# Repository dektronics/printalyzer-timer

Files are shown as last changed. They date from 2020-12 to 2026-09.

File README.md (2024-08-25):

# Printalyzer

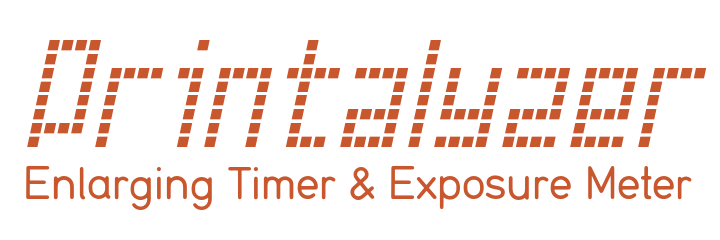
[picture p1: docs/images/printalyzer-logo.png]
Printalyzer Logo


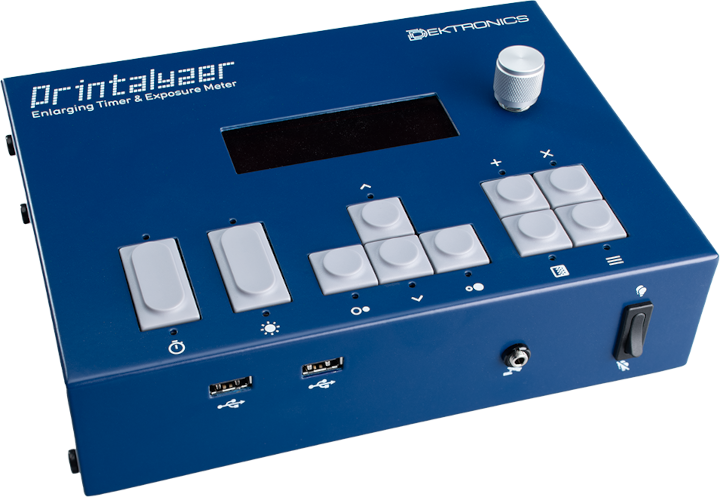
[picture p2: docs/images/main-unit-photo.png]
Main Unit Rendering


## Introduction

The Printalyzer is an F-Stop enlarging timer and print exposure meter.

A good overview of the project can be found in these blog posts:
* [Introducing the Printalyzer!](https://hecgeek.blogspot.com/2020/11/introducing-printalyzer.html)
* [Printalyzer Project Update](https://hecgeek.blogspot.com/2020/12/printalyzer-project-update.html)

Videos demonstrating the project are here:
* [Introducing the Printalyzer](https://youtu.be/2FPqqqVILP8)

The eventual goal of this project is to be available as a complete product available here:
* [Printalyzer Enlarging Timer](https://www.dektronics.com/printalyzer-enlarging-timer)

Note: This project is currently a work-in-progress, so expect the hardware and software to be continuously evolving.  The last functional version of this repository, using the revision A prototype hardware, was
'main-board-rev-a-186-g9bce418'.

## Project Layout

### Hardware
The "hardware" directory contains [KiCad](https://www.kicad.org/) projects
with the complete circuit schematics, bill-of-materials, and
PCB layouts.

* Main Board (main-board)
  * The main circuit board which contains all of the top panel controls and front panel ports
  * Runs off a +12V DC input, and contains regulators for all other voltage rails

* Power Board (power-board)
  * The AC power input board, which is the only part of the system that should ever touch mains AC power
  * Runs off power from an IEC320 C14 inlet, and provides output power to drive two IEC320 C13 outlets
  * Outputs the +12V DC power supply to run the rest of the system
  * Contains any connectors that need to be on the rear panel, isolating them if they do not involve mains AC power

* Printalyzer Meter Probe (meter-probe)
  * The circuit board contained within the external light meter probe peripheral
  * Connected to the main board and powered via a captive USB cable

* Printalyzer DensiStick (densistick)
  * The circuit board contained within the external reflection densitometer peripheral
  * Connected to the main board and powered via a captive USB cable

### Software
The "software" directory contains all the source code for the firmware
that runs on the hardware.

### Enclosure
The "enclosure" directory contains any CAD models and related resources
necessary to physically assemble the project.

## License
Individual directories will contain LICENSE files as needed, with relevant
details. Generally, the hardware will be CC BY-SA and the software will be
BSD 3-Clause. However, external resources may have their own individual license terms.

## Credits

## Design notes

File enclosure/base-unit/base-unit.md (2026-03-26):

# Printalyzer Enclosure Base Unit

## Introduction

This directory contains all the assets necessary to produce the physical
base unit enclosure for the Printalyzer. This document explains how to use
those assets, and ultimately how to assemble the enclosure.

## Electronics

### Main Board

The assets for the main circuit board are contained within the "main-board"
project under the top-level "hardware" directory. This board is installed
into the "cover" part of the main enclosure.

### Power Board

The assets for the main circuit board are contained within the "power-board"
project under the top-level "hardware" directory. This board is installed
into the "base" part of the main enclosure.

## Enclosures

### Main Enclosure

#### Enclosure components

The main enclosure is designed for sheet metal fabrication as two components.
The "base" is the bottom half where the power board is installed, and the
"cover" is the top half where the main board is installed.
Basic mechanical design files are provided, but the artwork is not published.

The provided files are as follows:
* `enclosure-full.step` - Complete enclosure model
* `enclosure-base-flat.dxf` - Flat pattern for the "base"
* `enclosure-cover-flat.dxf` - Flat pattern for the "cover"
* `design-drawings.pdf` - Basic design drawings

Base fabrication notes:
* Material: Galvanized sheet SGCC, 1.2mm thickness
* Contains 2 blind threaded standoffs, M3x0.5, 8mm length (PEM BSO-M3-8ZI)
* Contains 1 self-clinching threaded stud, M3x12mm (PEM FH-M3-12ZI)
* Contains 6 self-clinching nuts, M4x0.7 (PEM S-M4-1ZI)
* All blind standoffs must be inserted before powder coating, so that they are difficult to see from the outside of the finished product.
* Powder coat exterior surfaces only. Do not powder coat interior surfaces or the fold-up tabs with the self-clinching nuts.

Cover fabrication notes:
* Material: Galvanized sheet SGCC, 1.2mm thickness
* Contains 4 blind threaded standoffs, M3x0.5, 10mm length (PEM BSO-M3-10ZI)
* All blind standoffs must be inserted before powder coating, so they are
  difficult to see on the finished product.
* Inside of front edges, where the folds meet, need to be tack welded.
* Powder coat exterior surfaces only.  Do not powder coat interior surfaces.

#### Mounting hardware

Mounting hardware for the main enclosure consists of the following
components from [McMaster-Carr](https://www.mcmaster.com/), unless otherwise
specified. It should be possible to substitute hardware from other vendors as
long as it has the same specifications.

* Mounting "main-board" PCB to enclosure cover
  * **92005A118 (Qty. 4)** - Zinc-Plated Steel Pan Head Screw,
    M3 x 0.5mm Thread, 8mm Long
  * **98688A112 (Qty. 4)** - General Purpose Zinc-Plated Steel Washer for M3 Screw
  * **93925A417 (Qty. 4)** - Zinc-Plated Internal-Tooth Washer for M3 Screw
  * **90768A107 (Qty. 1)** - Side-Mount External Retaining Ring for 7mm ID
  * **97985A113 (Qty. 1)** - Zinc-Plated Steel External-Tooth Lock Washer for M7 Screw

* Mounting OLED display module to "main-board" PCB
  * **90657A106 (Qty. 4)** - Zinc-Plated Steel Narrow Cheese Head Slotted Screw,
    M3 x 0.5 mm Thread, 10 mm Long, 4 mm Head Diameter
  * **93657A203 (Qty. 4)** - Nylon Unthreaded Spacer,
    3 mm Long, for M3 Screw Size
  * **95225A315 (Qty. 4)** - Electrical-Insulating Hard Fiber Washer,
    for M3 Screw Size, 3.2 mm ID, 7 mm OD
  * **90576A102 (Qty. 4)** - Medium-Strength Steel Nylon-Insert Locknut,
    M3 x 0.5 mm Thread, 4 mm High

* Mounting "power-board" PCB to enclosure base
  * **92005A118 (Qty. 2)** - Zinc-Plated Steel Pan Head Screw,
    M3 x 0.5mm Thread, 8mm Long
  * **98688A112 (Qty. 2)** - General Purpose Zinc-Plated Steel Washer for M3 Screw
  * **93925A417 (Qty. 2)** - Zinc-Plated Internal-Tooth Washer for M3 Screw

* Mounting rear panel power connectors to "power board" PCB
  * **92005A120 (Qty. 6)** - Zinc-Plated Steel Pan Head Screw,
    M3 x 0.5mm Thread, 10mm Long
  * **95225A315 (Qty. 6)** - Electrical-Insulating Hard Fiber Washer,
    for M3 Screw Size, 3.2 mm ID, 7 mm OD
  * **90576A102 (Qty. 6)** - Medium-Strength Steel Nylon-Insert Locknut,
    M3 x 0.5 mm Thread, 4 mm High

* Mounting rear panel power and XLR connectors to enclosure base
  * **95836A209 (Qty. 6)** - Black-Oxide 18-8 Stainless Steel Pan Head Phillips Screw,
    M3 x 0.50 mm Thread, 10mm Long
  * **90576A102 (Qty. 6)** - Medium-Strength Steel Nylon-Insert Locknut,
    M3 x 0.5 mm Thread, 4 mm High
  * **A-SCREW-1-8 (Qty. 2)** - Black self-tapping Plastite screw
    (sold by Neutrik via electronics distributors)

#### Non-PCB Electronic Components
These electronic components are not included in the PCB's bill-of-materials,
but are ordered from the same kinds of vendors and are necessary to assemble
a complete device.

* Blackout switch
  * **Marquardt 1911.1102**
  * Rocker Switches ROCKER ON/OFF SWITCH SPST
* Power switch
  * **Marquardt 1801.1148**
  * Rocker Switches ROCKER ON/OFF SWITCH SPST
* Footswitch jack
  * **CUI MJ-3502**
  * Phono Connector 3.5mm Mono Jack
* Footswitch jack retaining ring
  * **Befaco Bananuts Black**
* Main fuse
  * **Littelfuse 0217005.MXBP**
  * Cylindrical cartridge fuse, 5x20mm
  * Fast-blow, rated for 5A @ 250V
* Graphic OLED display module
  * **BuyDisplay ER-OLEDM032-1Y**
  * 3.2" diagonal, 256x64 pixels, 4-wire SPI
  * Choose the version without the pin header
* 01x08 pin header, 2.54mm pitch
  * **Omron XG8T-1631**
  * Used to connect between the display module and the main PCB
  * Shorter than a standard pin header
* Key parallel guide
  * **Marquardt 190.059.023 (Qty. 2)**
  * Used as part of mounting the switches that have double-sized key caps

#### Key caps
For the key caps, use the following
[Marquardt](https://www.marquardt-switches.com/) parts:
* **825.000._xxx_ (Qty. 8)** - Square key cap, without LED window, 19mm pitch
* **844.000._xxx_ (Qty. 2)** - Double key cap, without LED window, 19mm pitch

The **_xxx_** portion of the part number can be any of the following:
* **.011** - Anthracite (Black)
* **.021** - Dark grey
* **.031** - Grey

_Note: Darker colors may look better when displaying the device under normal
room lighting, but lighter colors may be easier to see under actual
darkroom conditions._

For the encoder, use a knob designed for a 6mm D shaft. It is also preferable
to use a knob that has no direction marking.
The following choices have been tested so far:
* mxuteuk Black Aluminum Alloy Potentiometer Control Knob\
  Screw Type 17 x 16mm\
  Part # **KNOB-04-BK**
* mxuteuk Silver Aluminum Alloy Potentiometer Control Knob\
  Screw Type 17 x 16mm\
  Part # **KNOB-04-SR**

_For quantity orders, this same knob can be found from other vendors at
a lower price._

#### Internal wiring

* Connecting Blackout switch and Footswitch connector to the "main-board" PCB
  * **JST PHR-2 (Qty. 2)** - JST PH housing receptacle (2-pin)
  * **JSR ASPHSPH24K102 (Qty. 2)** - JST PH 4" jumper wire (cut each in half)
* Connecting "power-board" and "main-board" PCBs for power and relay
  * **JST PHR-4 (Qty. 2)** - JST PH housing receptacle (4-pin)
  * **JST ASPHSPH24K102 (Qty. 4)** - JST PH 4" jumper wire
* Connecting "power-board" and "main-board" PCBs for DMX connector
  * **JST A06SR06SR30K102A (Qty. 1)** - JST SR 4" 6-position reversed jumper wire
* Connecting "power-board" to the power switch
  * **Molex 46992-0210** - Mini-Fit Jr. Receptacle Housing
  * **Molex 215340-1122** - Mini-Fit Jr. Pre-Crimped Lead (cut in half)
  * **TE 3-520125-2 (Qty. 2)** - TE 187 Ultra-Fast Quick Disconnect Receptacle

_If there is not good electrical conductivity between the boards and the enclosure, and between the two halves of the enclosure, then a ground wire with eyelet terminals must be connected between a mounting hole on each board._

#### Other

* Rubylith-type material
  * This is a filter that is installed into the underside of the enclosure top,
    above the display module, to make the output spectrum of the display
    paper-safe.
  * The current preferred material for this purpose is Rosco E-Color #106.
* Thin transparent material to sandwich the rubylith between, for mounting
  and scratch protection.

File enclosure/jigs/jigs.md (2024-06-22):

# Assembly Jigs

## Introduction

This directory contains all the assets necessary to create the various jigs
used to aid in the assembly of the various components of the Printalyzer
Enlarging Timer and its accessories.

## PCB Assembly

These jigs are designed to help hold various components in place for soldering,
fastening, or general bench work. Many of them contain places where metal dowel
pins can be inserted to help hold the boards in correct alignment.

### Main Board

* `jig-main-board-platform-1`
  * Platform to support the main board when it is being worked on. (Orientation 1)
  * Shorter platform that fits the board with the button side facing upwards, or either side if
    the display and encoder are not yet installed.
* `jig-main-board-platform-2`
  * Platform to support the main board when it is being worked on. (Orientation 2)
  * Taller platform that fits the board with the button side facing downwards,
    with extra clearance for both the display and the encoder.
* `jig-main-board-buttons`
  * Jig to hold all of the push buttons in place for soldering.
  * Does not have clearance for the display, encoder, or button caps.
* `jig-main-board-leds`
  * Jig to hold all of the panel LEDs in place for soldering.
  * Does not have clearance for the display, encoder, or button caps.

### Power Board

* `jig-power-board-1`
  * Jig to hold all of the thru-hole components in place for soldering, and to
    make sure all the rear panel connectors are correctly aligned for fastening.
  * This board is designed to have a thin piece of adhesive foam placed onto
    each of the component holding standoffs, to help provide compliant pressure
    and deal with any vertical tolerance issues.
* `jig-power-board-2`
  * Jig to hold the nuts and washers in place on the bottom side of the board.
* `jig-power-board-platform`
  * Platform to support the power board when it is being worked on.

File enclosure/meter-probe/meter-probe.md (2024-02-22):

# Printalyzer Enclosure Meter Probe

## Introduction

This directory contains all the assets necessary to produce the physical
meter probe enclosure for the Printalyzer. This document explains how to use
those assets, and ultimately how to assemble the enclosure.

## Electronics

### Meter Probe

The assets for the meter probe circuit board are contained within the
"meter-probe" project under the top-level "hardware" directory. This board
is installed into the meter probe enclosure.

## Enclosures

### Meter Probe

#### Enclosure components
The meter probe enclosure was created with
[Autodesk Fusion 360](https://www.autodesk.com/products/fusion-360/overview),
and consists of the following components:
* `meter-probe-top.stl` - Top of the meter probe, which contains holes for
  the trigger button and the light sensor.
* `meter-probe-bottom.stl` - Bottom of the meter probe, which contains
  mounting points for the PCB and holes for screws that hold the enclosure
  together.
* `meter-probe-top-front.dxf` - Top front graphic overlay, with a matte clear
  window over the sensor hole.
* `meter-probe-top-rear.dxf` - Top rear graphic overlay, with a cutout over
  the trigger button.

#### Mounting hardware
Mounting hardware for the meter probe enclosure consists of the following
components from [McMaster-Carr](https://www.mcmaster.com/). It should be
possible to substitute hardware from other vendors as long as it has the
same dimensions.

* Mounting "meter-probe" PCB to the enclosure base
  * **90380A337 (Qty. 3)** - Phillips Rounded Head Thread-Forming Screws (M2.5 x 5mm long)
* Assembling the top and bottom of the enclosure
  * **90380A337 (Qty. 2)** - Phillips Rounded Head Thread-Forming Screws (M2.5 x 5mm long)
  * **90380A339 (Qty. 2)** - Phillips Rounded Head Thread-Forming Screws (M2.5 x 8mm long)

#### Key caps
For the cap on top of the trigger button, choose one of the following
[Marquardt](https://www.marquardt-switches.com/) parts:
* **827.100.011** - Anthracite (Black)
* **827.100.021** - Dark grey
* **827.100.031** - Grey

#### Other components
* 8mm diameter light diffuser, cut from LGT125J material with a hole punch
* 10mm diameter (0.5-1.0mm thick) UV-IR cut filter
* Captive USB mouse cable, with a rubber strain relief and a
  JST PH-compatible 5-pin internal connector.

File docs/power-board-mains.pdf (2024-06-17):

# Printalyzer

# Enlarging Timer & Exposure Meter

# Power Board

## Revision E

2024-06-12

## Table of Contents

## Table of Figures

## Circuit Board Design

The board design and layout is broken up into three major sections:
- Mains AC – The portion that handles incoming line voltage, and the primary focus of this document
- Logic DC – The portion that handles the low voltage 12VDC supply for the main board
- DMX – A completely separate low-voltage DC section that is only located on this board for mechanical convenience since it drives a rear panel connector

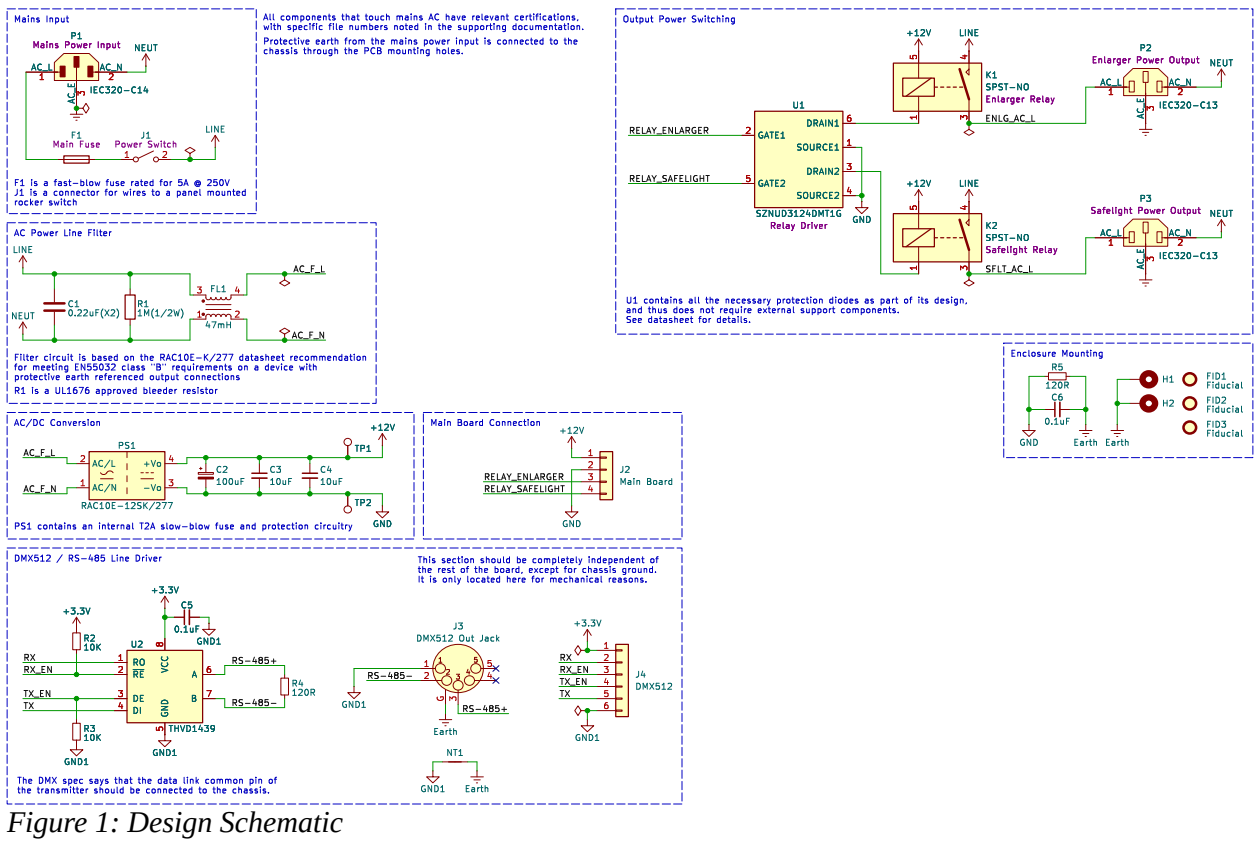
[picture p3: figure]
Figure 1: Design Schematic
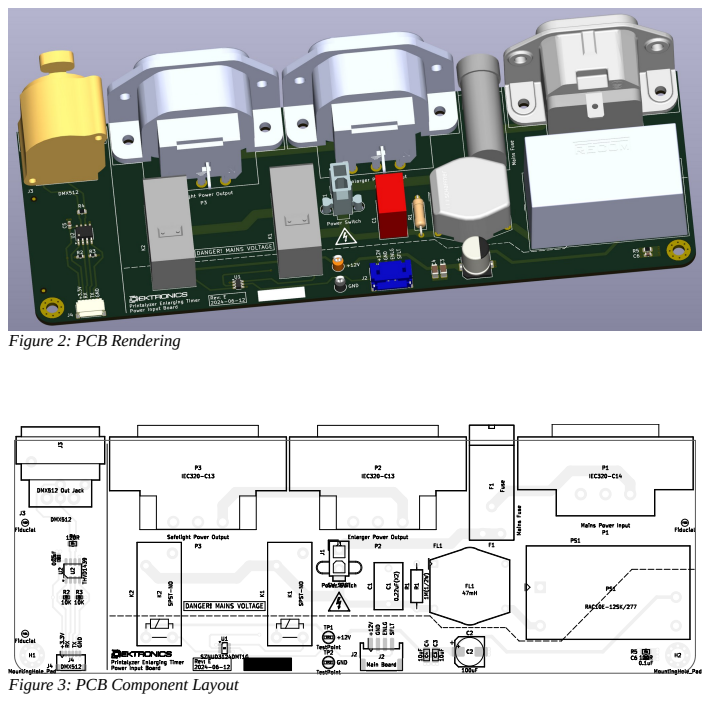
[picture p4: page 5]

Figure 2: PCB Rendering

Figure 3: PCB Component Layout

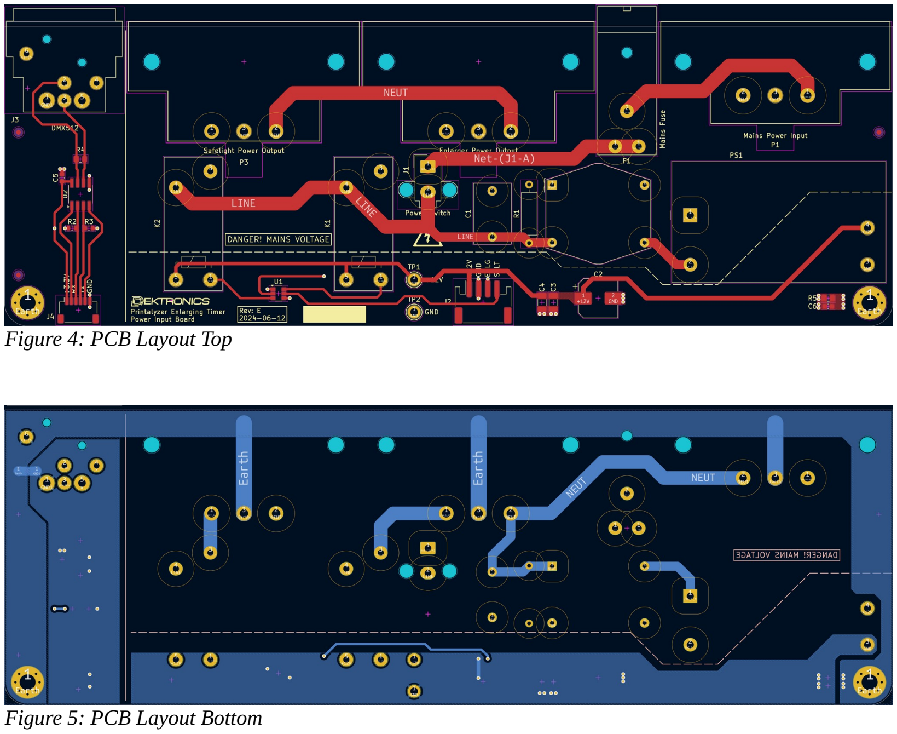
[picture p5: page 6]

Figure 4: PCB Layout Top

Figure 5: PCB Layout Bottom

## Circuit Board Manufacturing

The PCB itself is manufactured by JLCPCB with the following parameters:
- Dimenions: 193 mm x 65 mm
- Thickness: 1.6 mm
- Layers: 2
- Color: Green
- Material type: FR4-Standard TG 135-140
- Outer copper weight: 2 oz
- Surface finish: ENIG

Assembly is conducted in two phases. First, reflow soldering is used to mount the surface mount components. Second, hand soldering is used to mount the thru-hole components. Both are performed using a SAC305 solder alloy.

## Component List

Table 1: PCB Components
Section | Ref | Qty | Manufacturer | Part Number | Description
Mains AC | F1 | 1 | Schurter | 3101.01 | FUSE HLDR CARTRIDGE 400V 16A PCB
Mains AC | J1 | 1 | Molex | 1724470002 | Connector Header Through Hole 2 position
Mains AC | K1,K2 | 2 | Omron | G2RL-1A DC12 | RELAY GEN PURPOSE SPST 12A 12V
Mains AC | P1 | 1 | Schurter | GSP1.9113.1 | PWR ENT RCPT IEC320-C14 PNL SLDR
Mains AC | P2,P3 | 2 | Schurter | 6182 | PWR ENT RCPT IEC320-2-2F PANEL
Mains AC | PS1 | 1 | RECOM Power | RAC10E-12SK/277 | AC/DC CONVERTER 12V 10W
Mains AC | C1 | 1 | Würth Elektronik | 890324023028 | CAP FILM 0.22UF 10% 275VAC (X2)
Mains AC | R1 | 1 | Vishay | VR37000001004JR500 | RES 1M OHM 1/2W 5% MG AXIAL
Mains AC | FL1 | 1 | Schaffner EMC Inc. | RN116-0.5-02-47M | CMC 47MH 500MA 2LN TH
Logic DC | C2 | 1 | Nichicon | UWT1H101MNL1GS | CAP ALUM 100UF 20% 50V SMD
Logic DC | C3,C4 | 2 | Samsung Electro-Mechanics | CL31B106KBHNNNE | CAP CER 10UF 50V X7R 1206
Logic DC | C5,C6 | 2 | Samsung Electro-Mechanics | CL10B104KA8NNNC | CAP CER 0.1UF 25V X7R 0603
Logic DC | J2 | 1 | JST Sales America Inc. | S4B-PH-SM4-TB(LF)(SN) S4B-PH-SM4-TB(LF)(SN)
DMX | J3 | 1 | Neutrik | NC5FBH | XLR Connectors 5C PCB FEMALE RECEPT
DMX | J4 | 1 | JST Sales America Inc. | SM06B-SRSS-TB(LF) (SN) | CONN HEADER SMD R/A 6POS 1MM
Logic DC, DMX | R2,R3 | 2 | Vishay Dale | CRCW060310K0JNEA | RES SMD 10K OHM 5% 1/10W 0603
Logic DC, DMX | R4, R5 | 2 | Vishay Dale | CRCW0805120RFKEA | RES SMD 120 OHM 1% 1/8W 0805
Logic DC | TP1,TP2 | 2 | Keystone Electronics | 5006 | PC TEST POINT COMPACT BLACK
Logic DC | U1 | 1 | ON Semiconductor | SZNUD3124DMT1G | IC PWR DRIVER N-CHANNEL 1:1 SC74
DMX | U2 | 1 | Texas Instruments | THVD1439DR | IC TRANSCEIVER HALF 1/1 8SOIC

Table 2: Non-PCB Components
Section | Qty | Manufacturer | Part Number | Description
Mains AC | 1 | Molex | 46992-0210 | Mini-Fit Jr. Receptacle Housing
Mains AC | 1 | Molex | 215340-1122 | Mini-Fit Jr. Pre-Crimped Lead (cut in half)
Mains AC | 2 | TE Connectivity | 3-520125-2 | TE 187 Ultra-Fast Quick Disconnect Receptacle
Mains AC | 1 | Marquardt Switches | 1801.11 | Rocker On/Off Switch SPST
Mains AC | 1 | Littelfuse | 0217005.MXBP | Cylindrical cartridge fuse, 5x20mm, Fast-blow, rated for 5A @ 250V

## Mains AC Component Details

Manufacturer | Schurter
Part Number | 3101.0050
Description | External Fuse holder, 5 x 20 mm, PCB mounting
Ratings | 250 VAC · 2.5 W / 10 A (VDE) · 500 V · 16 A (UL/CSA)
Approvals | UL | File Number: E39328
| VDE | Certificate Number: 40044101
Manufacturer | Littelfuse
Part Number | 0217005.MXBP
Description | Cylindrical cartridge fuse, 5x20mm, Fast-Blow
Ratings | 5A @ 250V
Approvals | UL | File Number: E10480
| CSA | File Number: 29862
| VDE | Certificate Number: 40016647
Manufacturer | Molex
Part Number | 1724470002
Description | Connector header, through hole, 2 position
Ratings | Voltage: 600V AC (RMS)/DC, Current: 23.5A
Approvals | UL | File Number: (*)
| CSA | File Number: (*)
Manufacturer | Omron
Part Number | G2RL-1A DC12
Description | Electromechanical Relay SPST-NO
Ratings | 12VDC, 12A
Approvals | UL | File Number: E41643
| CSA | File Number: LR31928
| VDE | Certificate Number: 119650

Manufacturer | Schurter
Part Number | GSP1.9113.1
Description | Power Entry Connector Receptacle, Male Blades, IEC 320-C14 Panel Mount, Flange; Through Hole, Right Angle
Ratings | IEC | 10 A / 250 VAC; 50 Hz
| UL/CSA | 15 A / 250 VAC; 60 Hz
Approvals | UL | File Number: E96454
| VDE | Certificate Number: 40012767
| CCC | Certificate Number: 2020180204014251, 2020180204014252
Manufacturer | Schurter
Part Number | 6182.0033
Description | Power Entry Connector Receptacle, Female Sockets IEC 320-2-2/F Panel Mount, Flange; Through Hole, Right Angle
Ratings | IEC | 10 A / 250 VAC; 50 Hz
| UL/CSA | 15 A / 250 VAC; 60 Hz
Approvals | UL | File Number: E103791
| VDE | Certificate Number: 40053329
| CCC | Certificate Number: 2020180204013719 (PC I only)
Manufacturer | RECOM Power
Part Number | RAC10E-12SK/277
Description | Enclosed AC/DC Converter; 10W; 12VDC Output
Ratings | Input: 85-305 VAC 50/60Hz
Output: 12 VDC @ 833 mA
Approvals | E491408-A6019-UL | UL62368-1:2019 3rd Ed CAN/CSA-C22.2 No. 62368-1:2019 3rd Ed.
| 210824013 | IEC62368-1:2018 3rd Ed.
| 210824013 | EN IEC 62368-1:2020 + A11:2020
| 210824014 | IEC62368-1:2014 2nd Ed.
EN62368-1:2014 + A11:2017

Manufacturer | Würth Elektronik
Part Number | 890324023028
Description | CAP FILM 0.22UF 10% 275VAC (X2)
Ratings | 275VAC, Across the mains
Approvals | UL | File Number: E345659
| CQC | File Number: 13001104051
| ENEC10 | File Number: 40038405
Manufacturer | Vishay
Part Number | VR37000001004JR500
Description | RES 1M OHM 1/2W 5% MG AXIAL
Ratings | UL1676
Approvals | UL | File Number: E171160
Manufacturer | Schaffner EMC Inc.
Part Number | RN116-0.5-02-47M
Description | CMC 47MH 500MA 2LN TH
Ratings | 300 VAC, Design corresponding to UL 1283, IEC/EN 60938-1
Approvals | UL | File Number: E64388
| VDE | Certificate Number: 114916
Manufacturer | Molex
Part Number | 46992-0210
Description | Mini-Fit Jr. Receptacle Housing
Ratings | UL 94V-2, Glow-Wire Capable
Approvals | UL | File Number: E29179
| CSA | File Number: LR19980
Manufacturer | Molex
Part Number | 215340-1122
Description | Mini-Fit Jr. Pre-Crimped Lead (cut in half), UL 1015, 16 AWG
Ratings | 600V, 9A

Manufacturer | TE Connectivity
Part Number | 3-520125-2
Description | Ultra-Fast 187 Quick Disconnect Female 14-16 AWG Crimp Connector Fully Insulated
Ratings | 600V
Approvals | UL | File Number: E66717
Manufacturer | Marquardt Switches
Part Number | 1801.1148
Description | Rocker On/Off Switch SPST
Ratings | IEC | 8 (8) A 250 V AC 5E4 12 (4) A 250 V AC 1E4
| North America | 15A 250 V AC 1 1/2 HP 15A 125 V AC 3/4 HP
Approvals | UL | File Number: E41791

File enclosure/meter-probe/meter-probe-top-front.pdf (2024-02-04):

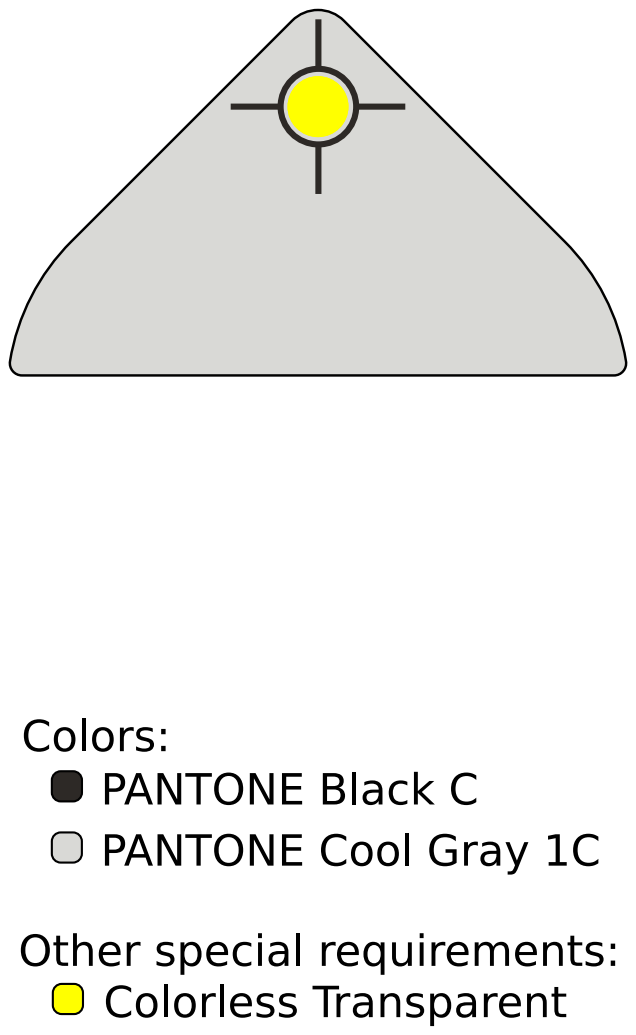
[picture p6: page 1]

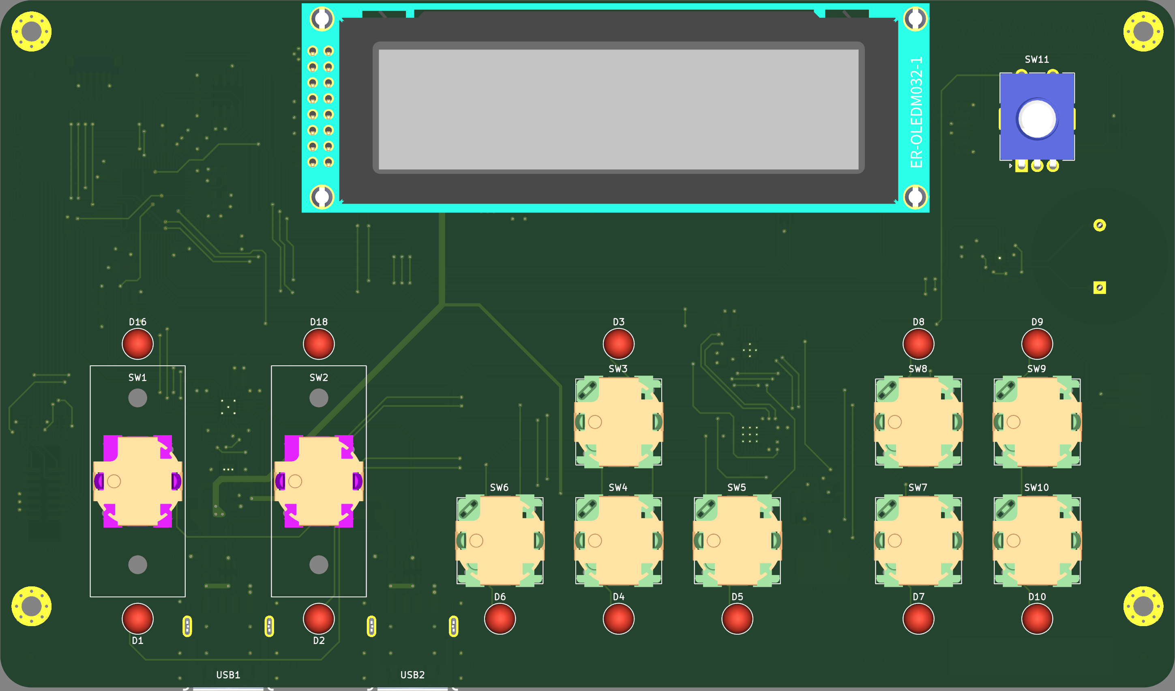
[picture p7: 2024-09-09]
docs/images/main-board-bottom.png

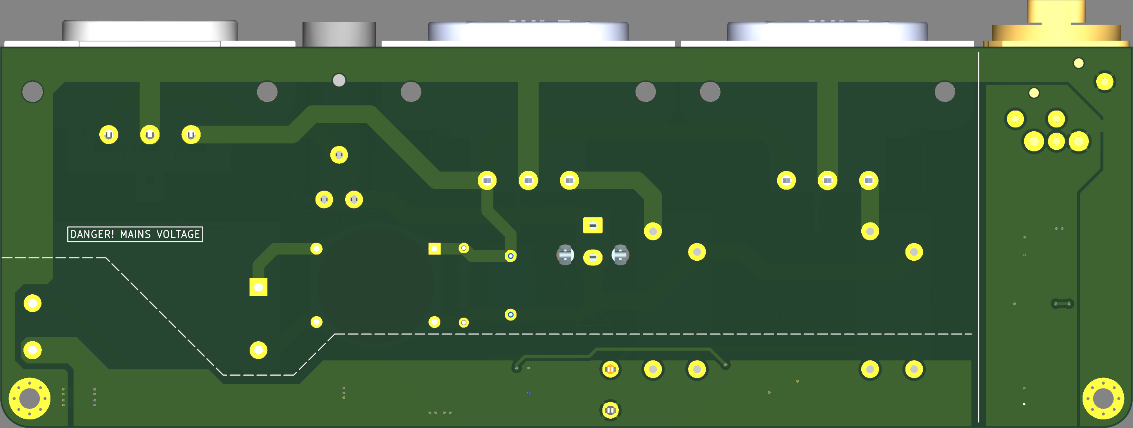
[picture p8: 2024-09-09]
docs/images/power-board-bottom.png

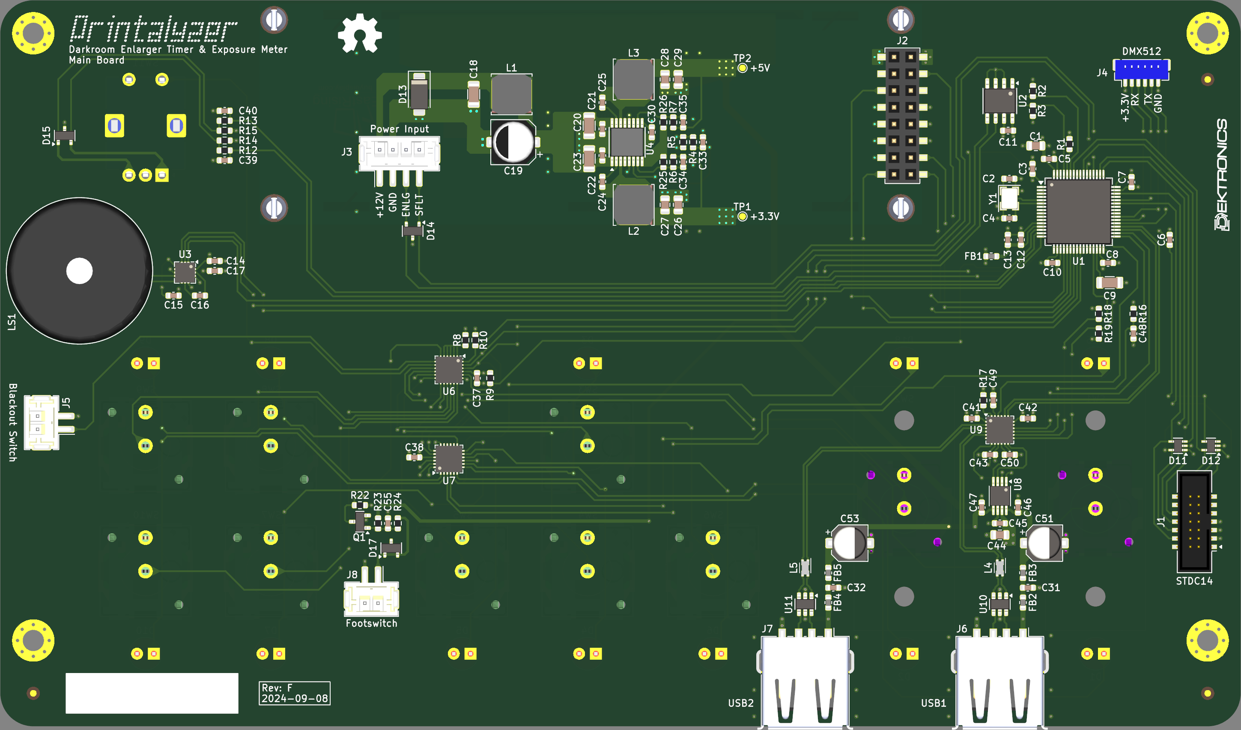
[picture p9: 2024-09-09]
docs/images/main-board-top.png

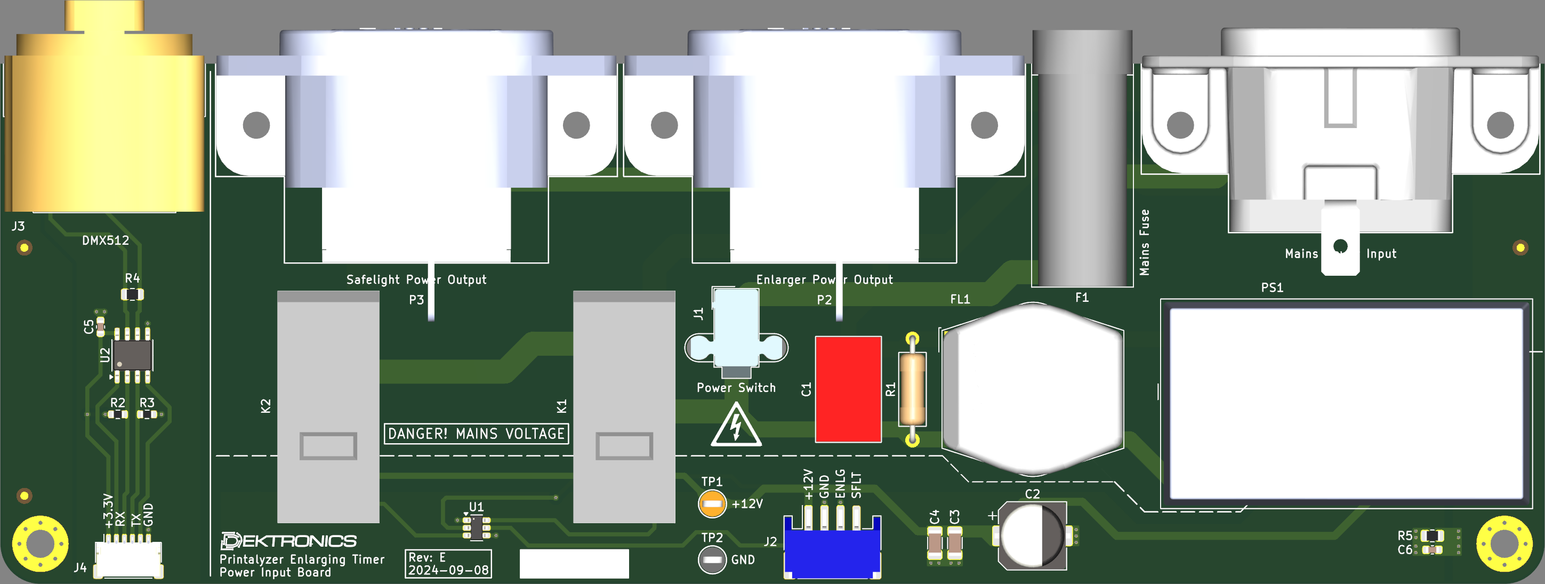
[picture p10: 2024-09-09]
docs/images/power-board-top.png

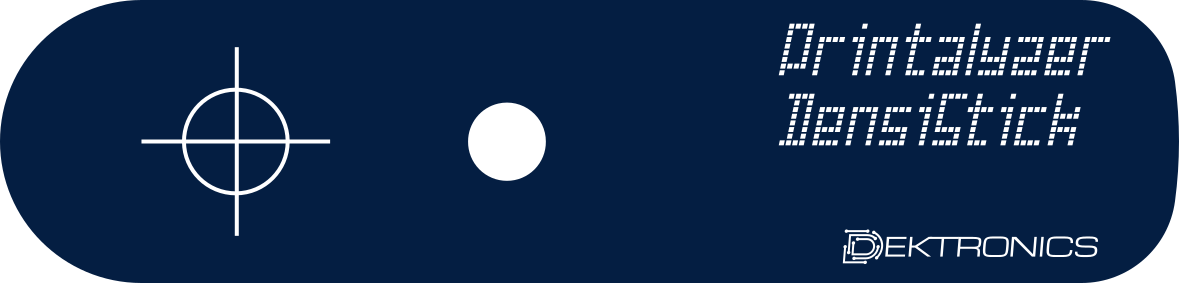
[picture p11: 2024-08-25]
enclosure/densistick/densistick-overlay-image.png

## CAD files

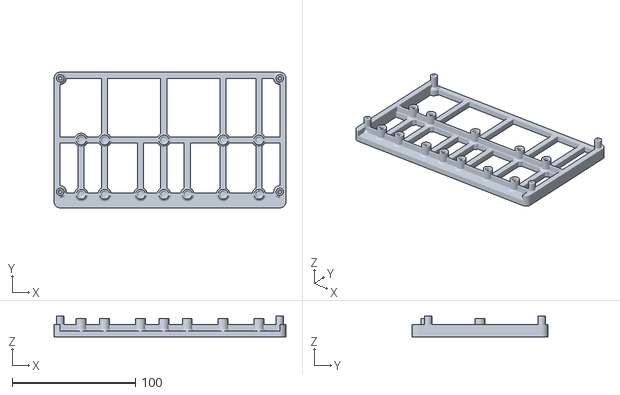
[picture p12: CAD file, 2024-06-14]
enclosure/jigs/jig-main-board-leds.stl
188.0 x 110.0 x 17.0

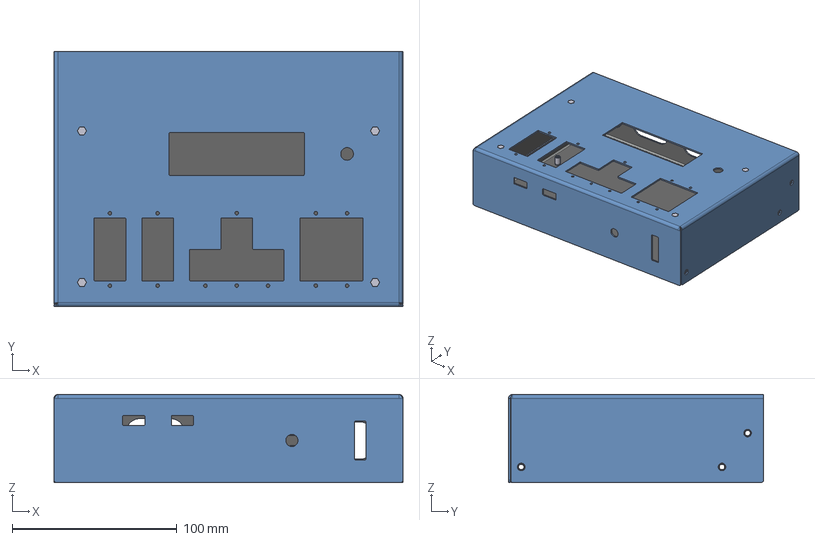
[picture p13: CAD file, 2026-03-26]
enclosure/base-unit/enclosure-full.step
211.9 x 154.9 x 53.5 mm
BSO-M3-8ZI x 2
S-M4-1ZI x 6
FH-M3-12ZI
BSO-M3-10ZI x 4

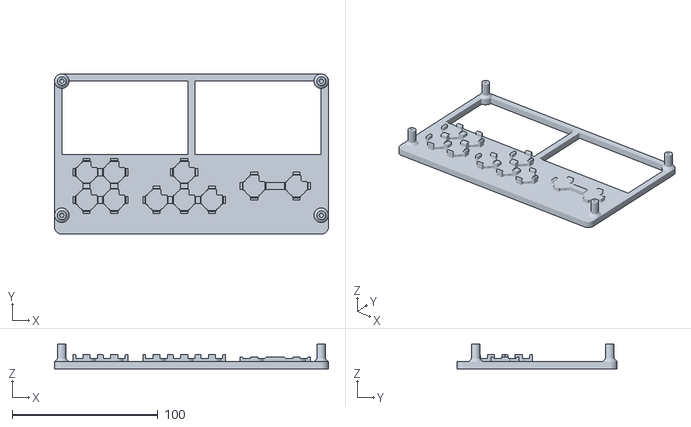
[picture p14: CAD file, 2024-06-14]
enclosure/jigs/jig-main-board-buttons.stl
188.0 x 110.0 x 17.0

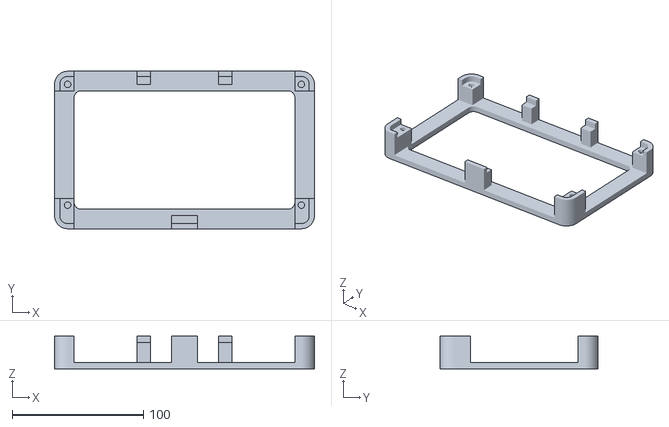
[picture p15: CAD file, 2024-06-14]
enclosure/jigs/jig-main-board-platform-1.stl
198.0 x 120.0 x 25.0

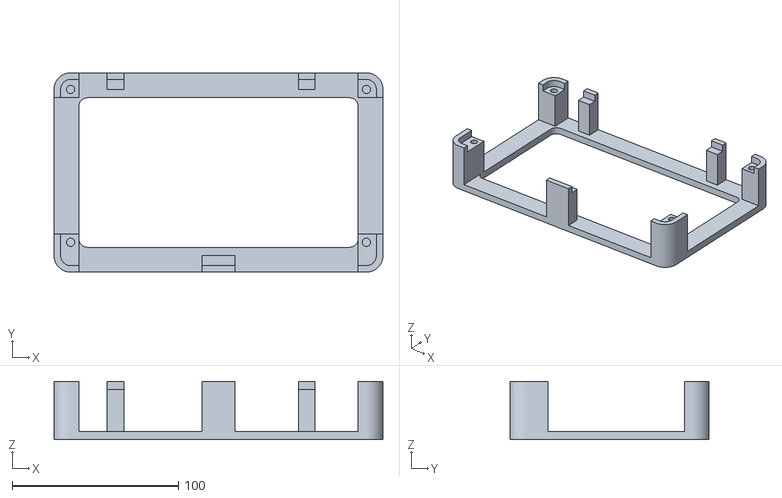
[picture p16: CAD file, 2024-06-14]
enclosure/jigs/jig-main-board-platform-2.stl
198.0 x 120.0 x 35.0

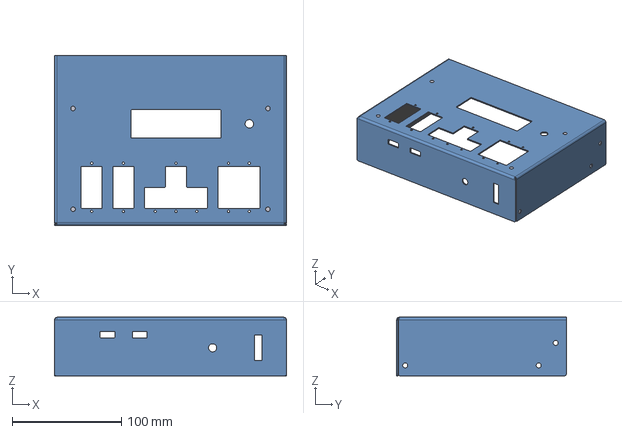
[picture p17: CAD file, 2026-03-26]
enclosure/base-unit/enclosure-cover.step
211.9 x 154.9 x 53.5 mm
BSO-M3-10ZI x 4

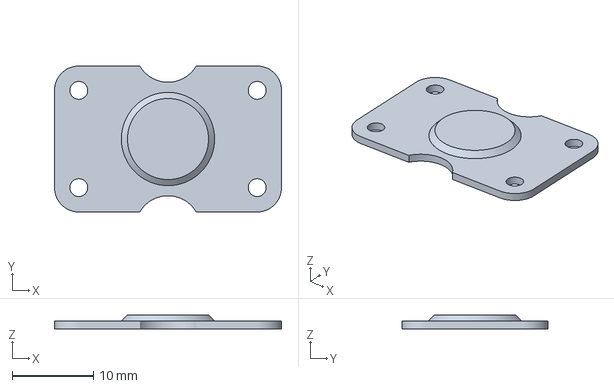
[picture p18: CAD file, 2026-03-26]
enclosure/densistick/sensor-board-cover.3mf
28.0 x 18.0 x 1.75 mm

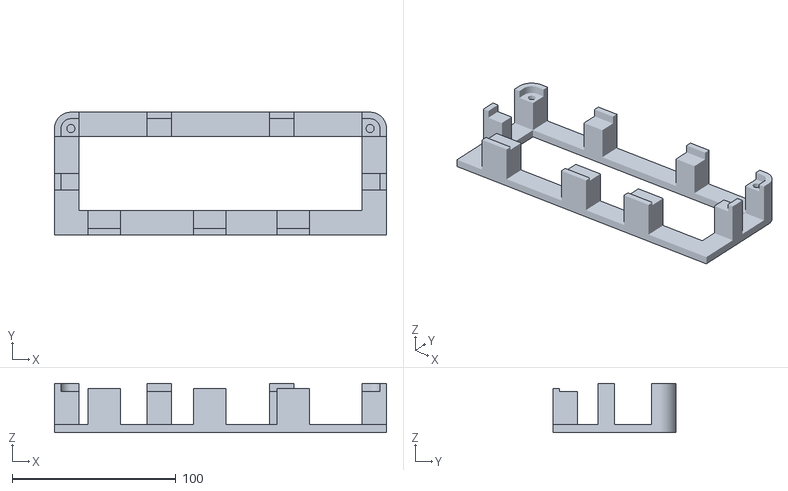
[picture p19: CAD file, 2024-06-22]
enclosure/jigs/jig-power-board-platform.stl
203.0 x 75.0 x 30.0

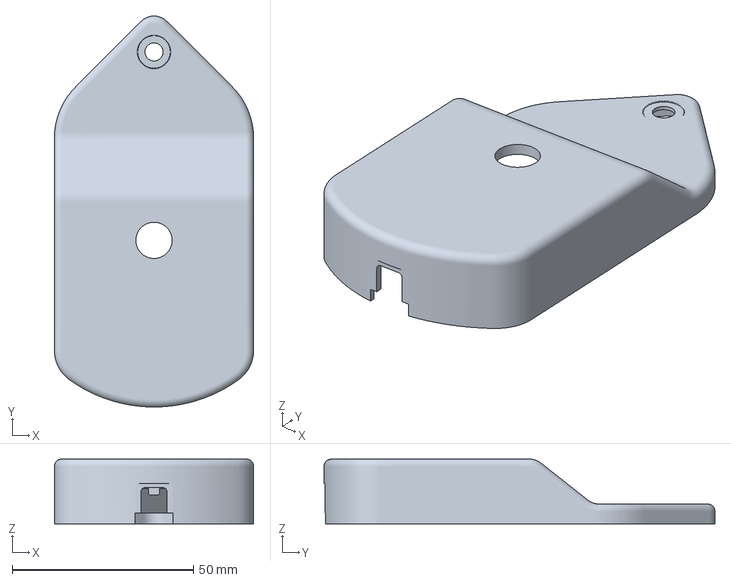
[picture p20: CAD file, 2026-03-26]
enclosure/meter-probe/meter-probe-top.3mf
55.0 x 107.9 x 17.9 mm

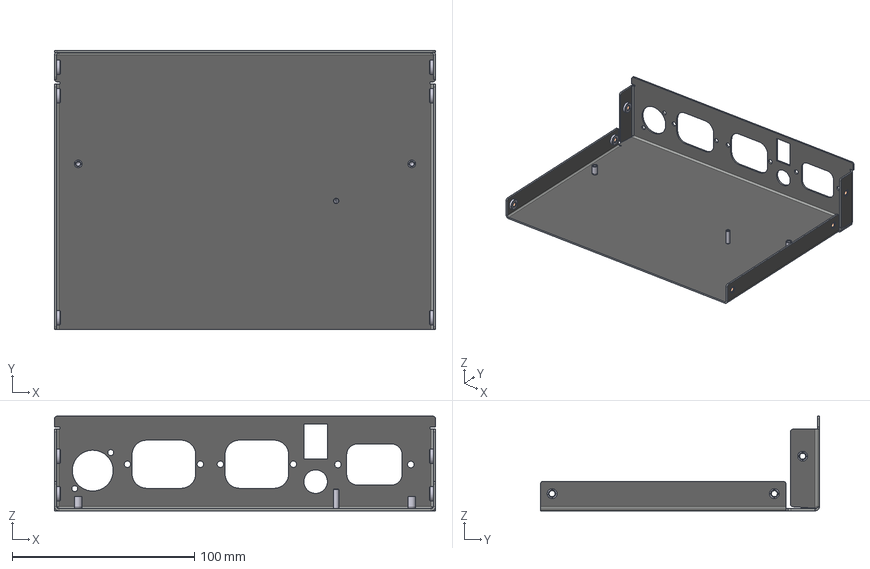
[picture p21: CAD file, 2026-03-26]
enclosure/base-unit/enclosure-base.step
209.0 x 153.0 x 52.0 mm
BSO-M3-8ZI x 2
S-M4-1ZI x 6
FH-M3-12ZI

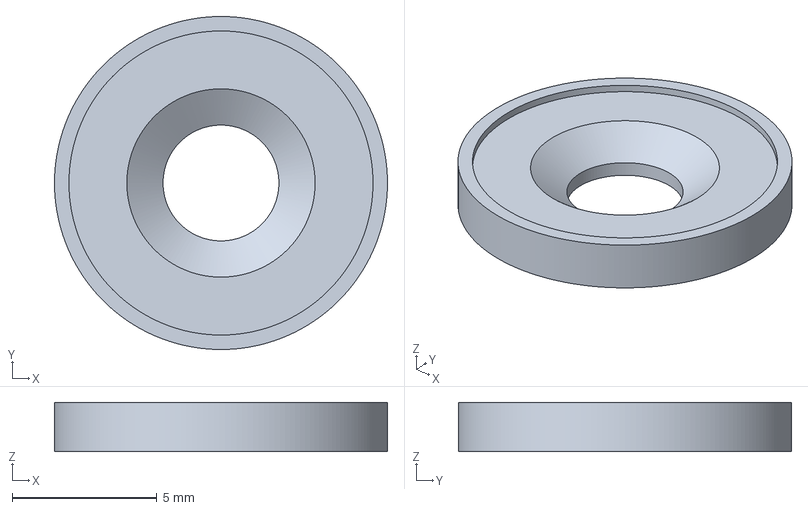
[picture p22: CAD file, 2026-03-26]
enclosure/densistick/lower-filter-ring.3mf
11.5 x 11.5 x 1.70 mm

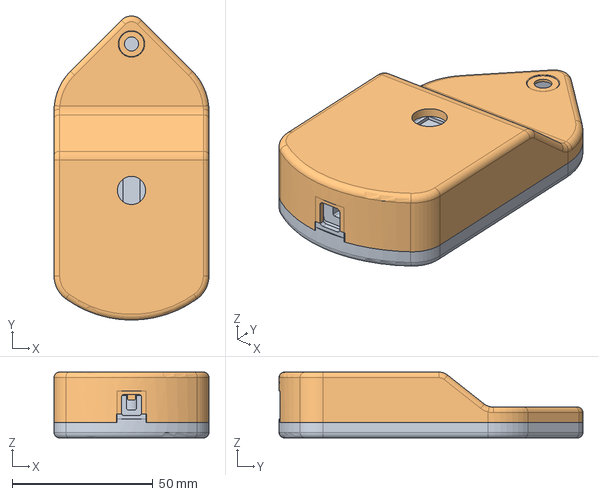
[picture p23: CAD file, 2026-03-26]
enclosure/meter-probe/meter-probe-enclosure.step
55.0 x 107.9 x 23.4 mm
Enclosure Bottom
Enclosure Top

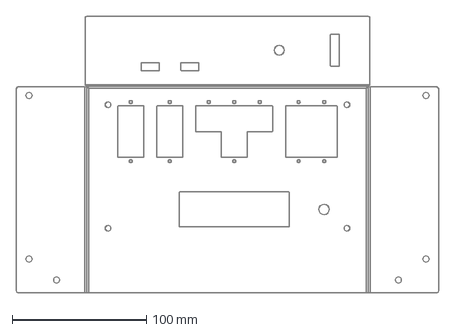
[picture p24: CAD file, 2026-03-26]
enclosure/base-unit/enclosure-cover-flat.dxf
314.6 x 206.3 mm

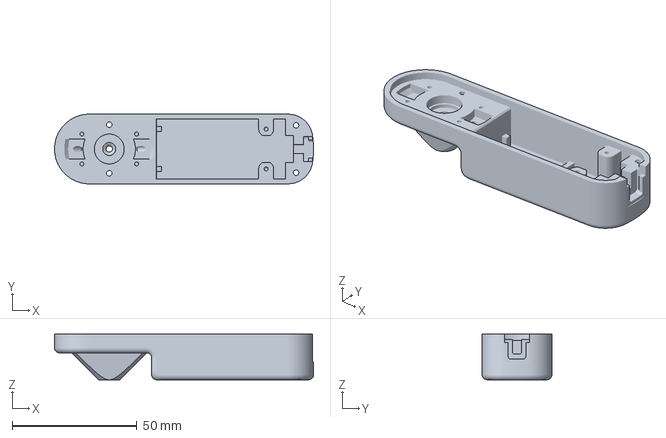
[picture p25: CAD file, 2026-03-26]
enclosure/densistick/densistick-body.3mf
104.0 x 28.0 x 18.3 mm

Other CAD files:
enclosure/jigs/jig-power-board-2.stl
enclosure/meter-probe/meter-probe-bottom.3mf
enclosure/densistick/densistick-enclosure.step
enclosure/meter-probe/meter-probe-top-rear.dxf
enclosure/base-unit/enclosure-base-flat.dxf
enclosure/densistick/densistick-body.stl
enclosure/densistick/densistick-cover.3mf
enclosure/densistick/densistick-cover.stl
enclosure/densistick/densistick-overlay.dxf
enclosure/densistick/lower-filter-ring.stl
enclosure/densistick/sensor-board-cover.stl
enclosure/densistick/upper-filter-ring.dxf
enclosure/jigs/jig-power-board-1.stl
enclosure/meter-probe/meter-probe-bottom.stl
enclosure/meter-probe/meter-probe-top-front.dxf
enclosure/meter-probe/meter-probe-top.stl

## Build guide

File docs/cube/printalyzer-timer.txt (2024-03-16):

Configuration	printalyzer-timer
STM32CubeMX 	6.10.0
Date	03/16/2024
MCU	STM32F446RETx

PERIPHERALS	MODES	FUNCTIONS	PINS
I2C1	I2C	I2C1_SCL	PB8
I2C1	I2C	I2C1_SDA	PB7
I2C2	SMBus-two-wire-Interface	I2C2_SCL	PB10
I2C2	SMBus-two-wire-Interface	I2C2_SDA	PC12
RCC	Crystal/Ceramic Resonator	RCC_OSC_IN	PH0-OSC_IN
RCC	Crystal/Ceramic Resonator	RCC_OSC_OUT	PH1-OSC_OUT
RCC	Clock-out-2	RCC_MCO_2	PC9
SPI1	Transmit Only Master	SPI1_MOSI	PA7
SPI1	Transmit Only Master	SPI1_SCK	PA5
SPI3	Transmit Only Master	SPI3_MOSI	PC1
SPI3	Transmit Only Master	SPI3_SCK	PC10
SYS	JTAG (4 pins)	SYS_JTCK-SWCLK	PA14
SYS	JTAG (4 pins)	SYS_JTDI	PA15
SYS	JTAG (4 pins)	SYS_JTDO-SWO	PB3
SYS	JTAG (4 pins)	SYS_JTMS-SWDIO	PA13
SYS	TIM11	SYS_VS_tim11	VP_SYS_VS_tim11
TIM1	Encoder Mode	TIM1_CH1	PA8
TIM1	Encoder Mode	TIM1_CH2	PA9
TIM3	PWM Generation CH3	TIM3_CH3	PB0
TIM4	Output Compare No Output	TIM4_VS_no_output1	VP_TIM4_VS_no_output1
TIM8	PWM Generation No Output	TIM8_VS_no_output1	VP_TIM8_VS_no_output1
TIM9	PWM Generation CH1	TIM9_CH1	PA2
TIM10	Enable_Timer	TIM10_VS_ClockSourceINT	VP_TIM10_VS_ClockSourceINT
TIM10	PWM Generation No Output	TIM10_VS_no_output1	VP_TIM10_VS_no_output1
USART1	Asynchronous	USART1_RX	PA10
USART1	Asynchronous	USART1_TX	PB6
USART6	Asynchronous	USART6_RX	PC7
USART6	Asynchronous	USART6_TX	PC6
USB_OTG_HS	Host_Only	USB_OTG_HS_DM	PB14
USB_OTG_HS	Host_Only	USB_OTG_HS_DP	PB15

Pin Nb	PINs	FUNCTIONs	LABELs
5	PH0-OSC_IN	RCC_OSC_IN	
6	PH1-OSC_OUT	RCC_OSC_OUT	
9	PC1	SPI3_MOSI	LED_SDI [LED Driver]
10	PC2	GPIO_Output	LED_LE [LED Driver]
14	PA0-WKUP	GPIO_Output	BUZZ_EN1 [Piezo]
15	PA1	GPIO_Output	BUZZ_EN2 [Piezo]
16	PA2	TIM9_CH1	BUZZ_DIN [Piezo]
20	PA4	GPIO_Output	DISP_CS [Display]
21	PA5	SPI1_SCK	DISP_SCK [Display]
22	PA6	GPIO_Output	DISP_DC [Display]
23	PA7	SPI1_MOSI	DISP_MOSI [Display]
24	PC4	GPIO_Output	DISP_RESET [Display]
26	PB0	TIM3_CH3	LED_OE [LED Driver]
29	PB10	I2C2_SCL	
33	PB12	GPIO_Output	USB_HUB_RESET
34	PB13	GPIO_Output	USB_DRIVE_VBUS
35	PB14	USB_OTG_HS_DM	
36	PB15	USB_OTG_HS_DP	
37	PC6	USART6_TX	DMX512_TX
38	PC7	USART6_RX	DMX512_RX
39	PC8	GPIO_Output	DMX512_TX_EN
40	PC9	RCC_MCO_2	USB_HUB_CLK
41	PA8	TIM1_CH1	ENC_CH1
42	PA9	TIM1_CH2	ENC_CH2
43	PA10	USART1_RX	
44	PA11	GPIO_Output	DMX512_RX_EN
46	PA13	SYS_JTMS-SWDIO	
49	PA14	SYS_JTCK-SWCLK	
50	PA15	SYS_JTDI	
51	PC10	SPI3_SCK	LED_CLK [LED Driver]
52	PC11	GPIO_Output	RELAY_SFLT [Safelight]
53	PC12	I2C2_SDA	
54	PD2	GPIO_Output	RELAY_ENLG [Enlarger]
55	PB3	SYS_JTDO-SWO	
57	PB5	GPIO_EXTI5	KEY_INT [Keypad]
58	PB6	USART1_TX	
59	PB7	I2C1_SDA	
61	PB8	I2C1_SCL	
PERIPHERALS	MODES	FUNCTIONS	PINS
I2C1	I2C	I2C1_SCL	PB8
I2C1	I2C	I2C1_SDA	PB7
I2C2	SMBus-two-wire-Interface	I2C2_SCL	PB10
I2C2	SMBus-two-wire-Interface	I2C2_SDA	PC12
RCC	Crystal/Ceramic Resonator	RCC_OSC_IN	PH0-OSC_IN
RCC	Crystal/Ceramic Resonator	RCC_OSC_OUT	PH1-OSC_OUT
RCC	Clock-out-2	RCC_MCO_2	PC9
SPI1	Transmit Only Master	SPI1_MOSI	PA7
SPI1	Transmit Only Master	SPI1_SCK	PA5
SPI3	Transmit Only Master	SPI3_MOSI	PC1
SPI3	Transmit Only Master	SPI3_SCK	PC10
SYS	JTAG (4 pins)	SYS_JTCK-SWCLK	PA14
SYS	JTAG (4 pins)	SYS_JTDI	PA15
SYS	JTAG (4 pins)	SYS_JTDO-SWO	PB3
SYS	JTAG (4 pins)	SYS_JTMS-SWDIO	PA13
SYS	TIM11	SYS_VS_tim11	VP_SYS_VS_tim11
TIM1	Encoder Mode	TIM1_CH1	PA8
TIM1	Encoder Mode	TIM1_CH2	PA9
TIM3	PWM Generation CH3	TIM3_CH3	PB0
TIM4	Output Compare No Output	TIM4_VS_no_output1	VP_TIM4_VS_no_output1
TIM8	PWM Generation No Output	TIM8_VS_no_output1	VP_TIM8_VS_no_output1
TIM9	PWM Generation CH1	TIM9_CH1	PA2
TIM10	Enable_Timer	TIM10_VS_ClockSourceINT	VP_TIM10_VS_ClockSourceINT
TIM10	PWM Generation No Output	TIM10_VS_no_output1	VP_TIM10_VS_no_output1
USART1	Asynchronous	USART1_RX	PA10
USART1	Asynchronous	USART1_TX	PB6
USART6	Asynchronous	USART6_RX	PC7
USART6	Asynchronous	USART6_TX	PC6
USB_OTG_HS	Host_Only	USB_OTG_HS_DM	PB14
USB_OTG_HS	Host_Only	USB_OTG_HS_DP	PB15

Pin Nb	PINs	FUNCTIONs	LABELs
5	PH0-OSC_IN	RCC_OSC_IN	
6	PH1-OSC_OUT	RCC_OSC_OUT	
9	PC1	SPI3_MOSI	LED_SDI [LED Driver]
10	PC2	GPIO_Output	LED_LE [LED Driver]
14	PA0-WKUP	GPIO_Output	BUZZ_EN1 [Piezo]
15	PA1	GPIO_Output	BUZZ_EN2 [Piezo]
16	PA2	TIM9_CH1	BUZZ_DIN [Piezo]
20	PA4	GPIO_Output	DISP_CS [Display]
21	PA5	SPI1_SCK	DISP_SCK [Display]
22	PA6	GPIO_Output	DISP_DC [Display]
23	PA7	SPI1_MOSI	DISP_MOSI [Display]
24	PC4	GPIO_Output	DISP_RESET [Display]
26	PB0	TIM3_CH3	LED_OE [LED Driver]
29	PB10	I2C2_SCL	
33	PB12	GPIO_Output	USB_HUB_RESET
34	PB13	GPIO_Output	USB_DRIVE_VBUS
35	PB14	USB_OTG_HS_DM	
36	PB15	USB_OTG_HS_DP	
37	PC6	USART6_TX	DMX512_TX
38	PC7	USART6_RX	DMX512_RX
39	PC8	GPIO_Output	DMX512_TX_EN
40	PC9	RCC_MCO_2	USB_HUB_CLK
41	PA8	TIM1_CH1	ENC_CH1
42	PA9	TIM1_CH2	ENC_CH2
43	PA10	USART1_RX	
44	PA11	GPIO_Output	DMX512_RX_EN
46	PA13	SYS_JTMS-SWDIO	
49	PA14	SYS_JTCK-SWCLK	
50	PA15	SYS_JTDI	
51	PC10	SPI3_SCK	LED_CLK [LED Driver]
52	PC11	GPIO_Output	RELAY_SFLT [Safelight]
53	PC12	I2C2_SDA	
54	PD2	GPIO_Output	RELAY_ENLG [Enlarger]
55	PB3	SYS_JTDO-SWO	
57	PB5	GPIO_EXTI5	KEY_INT [Keypad]
58	PB6	USART1_TX	
59	PB7	I2C1_SDA	
61	PB8	I2C1_SCL	

SOFTWARE PROJECT

Project Settings : 
Project Name : printalyzer-timer
Project Folder : /home/octo/devel/printalyzer-cube/firmware_d
Toolchain / IDE : STM32CubeIDE
Firmware Package Name and Version : STM32Cube FW_F4 V1.28.0

Code Generation Settings : 
STM32Cube MCU packages and embedded software packs : Copy only the necessary library files
Generate peripheral initialization as a pair of '.c/.h' files per peripheral : No
Backup previously generated files when re-generating : No
Delete previously generated files when not re-generated : Yes
Set all free pins as analog (to optimize the power consumption) : Yes

Toolchains Settings : 
Compiler Optimizations :

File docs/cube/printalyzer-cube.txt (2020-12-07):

Configuration	printalyzer-cube
STM32CubeMX 	6.1.0
Date	12/07/2020
MCU	STM32F411RETx

PERIPHERALS	MODES	FUNCTIONS	PINS
I2C1	I2C	I2C1_SCL	PB8
I2C1	I2C	I2C1_SDA	PB7
I2C2	I2C	I2C2_SCL	PB10
I2C2	I2C	I2C2_SDA	PB9
RCC	Crystal/Ceramic Resonator	RCC_OSC_IN	PH0 - OSC_IN
RCC	Crystal/Ceramic Resonator	RCC_OSC_OUT	PH1 - OSC_OUT
SPI1	Transmit Only Master	SPI1_MOSI	PA7
SPI1	Transmit Only Master	SPI1_SCK	PA5
SPI2	Transmit Only Master	SPI2_MOSI	PB15
SPI2	Transmit Only Master	SPI2_SCK	PC7
SYS	JTAG (4 pins)	SYS_JTCK-SWCLK	PA14
SYS	JTAG (4 pins)	SYS_JTDI	PA15
SYS	JTAG (4 pins)	SYS_JTDO-SWO	PB3
SYS	JTAG (4 pins)	SYS_JTMS-SWDIO	PA13
SYS	TIM11	SYS_VS_tim11	VP_SYS_VS_tim11
TIM1	Encoder Mode	TIM1_CH1	PA8
TIM1	Encoder Mode	TIM1_CH2	PA9
TIM3	PWM Generation CH1	TIM3_CH1	PC6
TIM9	PWM Generation CH1	TIM9_CH1	PA2
USART1	Asynchronous	USART1_RX	PA10
USART1	Asynchronous	USART1_TX	PB6
USB_OTG_FS	Host_Only	USB_OTG_FS_DM	PA11
USB_OTG_FS	Host_Only	USB_OTG_FS_DP	PA12

Pin Nb	PINs	FUNCTIONs	LABELs
5	PH0 - OSC_IN	RCC_OSC_IN	
6	PH1 - OSC_OUT	RCC_OSC_OUT	
9	PC1	GPIO_Output	USB_DRIVE_VBUS [USB FS]
10	PC2	GPIO_EXTI2	USB_VBUS_OC [USB FS]
14	PA0-WKUP	GPIO_Output	BUZZ_EN1 [Piezo]
15	PA1	GPIO_Output	BUZZ_EN2 [Piezo]
16	PA2	TIM9_CH1	BUZZ_DIN [Piezo]
20	PA4	GPIO_Output	DISP_CS [Display]
21	PA5	SPI1_SCK	DISP_SCK [Display]
22	PA6	GPIO_Output	DISP_DC [Display]
23	PA7	SPI1_MOSI	DISP_MOSI [Display]
24	PC4	GPIO_Output	DISP_RES [Display]
27	PB1	GPIO_EXTI1	SENSOR_INT [Meter Probe]
29	PB10	I2C2_SCL	
35	PB14	GPIO_Output	LED_LE [LED Driver]
36	PB15	SPI2_MOSI	LED_SDI [LED Driver]
37	PC6	TIM3_CH1	LED_OE [LED Driver]
38	PC7	SPI2_SCK	LED_CLK [LED Driver]
39	PC8	GPIO_Output	RELAY_SFLT [Safelight]
40	PC9	GPIO_Output	RELAY_ENLG [Enlarger]
41	PA8	TIM1_CH1	ENC_CH1
42	PA9	TIM1_CH2	ENC_CH2
43	PA10	USART1_RX	
44	PA11	USB_OTG_FS_DM	
45	PA12	USB_OTG_FS_DP	
46	PA13	SYS_JTMS-SWDIO	
49	PA14	SYS_JTCK-SWCLK	
50	PA15	SYS_JTDI	
55	PB3	SYS_JTDO-SWO	
57	PB5	GPIO_EXTI5	KEY_INT [Keypad]
58	PB6	USART1_TX	
59	PB7	I2C1_SDA	
61	PB8	I2C1_SCL	
62	PB9	I2C2_SDA	
PERIPHERALS	MODES	FUNCTIONS	PINS
I2C1	I2C	I2C1_SCL	PB8
I2C1	I2C	I2C1_SDA	PB7
I2C2	I2C	I2C2_SCL	PB10
I2C2	I2C	I2C2_SDA	PB9
RCC	Crystal/Ceramic Resonator	RCC_OSC_IN	PH0 - OSC_IN
RCC	Crystal/Ceramic Resonator	RCC_OSC_OUT	PH1 - OSC_OUT
SPI1	Transmit Only Master	SPI1_MOSI	PA7
SPI1	Transmit Only Master	SPI1_SCK	PA5
SPI2	Transmit Only Master	SPI2_MOSI	PB15
SPI2	Transmit Only Master	SPI2_SCK	PC7
SYS	JTAG (4 pins)	SYS_JTCK-SWCLK	PA14
SYS	JTAG (4 pins)	SYS_JTDI	PA15
SYS	JTAG (4 pins)	SYS_JTDO-SWO	PB3
SYS	JTAG (4 pins)	SYS_JTMS-SWDIO	PA13
SYS	TIM11	SYS_VS_tim11	VP_SYS_VS_tim11
TIM1	Encoder Mode	TIM1_CH1	PA8
TIM1	Encoder Mode	TIM1_CH2	PA9
TIM3	PWM Generation CH1	TIM3_CH1	PC6
TIM9	PWM Generation CH1	TIM9_CH1	PA2
USART1	Asynchronous	USART1_RX	PA10
USART1	Asynchronous	USART1_TX	PB6
USB_OTG_FS	Host_Only	USB_OTG_FS_DM	PA11
USB_OTG_FS	Host_Only	USB_OTG_FS_DP	PA12

Pin Nb	PINs	FUNCTIONs	LABELs
5	PH0 - OSC_IN	RCC_OSC_IN	
6	PH1 - OSC_OUT	RCC_OSC_OUT	
9	PC1	GPIO_Output	USB_DRIVE_VBUS [USB FS]
10	PC2	GPIO_EXTI2	USB_VBUS_OC [USB FS]
14	PA0-WKUP	GPIO_Output	BUZZ_EN1 [Piezo]
15	PA1	GPIO_Output	BUZZ_EN2 [Piezo]
16	PA2	TIM9_CH1	BUZZ_DIN [Piezo]
20	PA4	GPIO_Output	DISP_CS [Display]
21	PA5	SPI1_SCK	DISP_SCK [Display]
22	PA6	GPIO_Output	DISP_DC [Display]
23	PA7	SPI1_MOSI	DISP_MOSI [Display]
24	PC4	GPIO_Output	DISP_RES [Display]
27	PB1	GPIO_EXTI1	SENSOR_INT [Meter Probe]
29	PB10	I2C2_SCL	
35	PB14	GPIO_Output	LED_LE [LED Driver]
36	PB15	SPI2_MOSI	LED_SDI [LED Driver]
37	PC6	TIM3_CH1	LED_OE [LED Driver]
38	PC7	SPI2_SCK	LED_CLK [LED Driver]
39	PC8	GPIO_Output	RELAY_SFLT [Safelight]
40	PC9	GPIO_Output	RELAY_ENLG [Enlarger]
41	PA8	TIM1_CH1	ENC_CH1
42	PA9	TIM1_CH2	ENC_CH2
43	PA10	USART1_RX	
44	PA11	USB_OTG_FS_DM	
45	PA12	USB_OTG_FS_DP	
46	PA13	SYS_JTMS-SWDIO	
49	PA14	SYS_JTCK-SWCLK	
50	PA15	SYS_JTDI	
55	PB3	SYS_JTDO-SWO	
57	PB5	GPIO_EXTI5	KEY_INT [Keypad]
58	PB6	USART1_TX	
59	PB7	I2C1_SDA	
61	PB8	I2C1_SCL	
62	PB9	I2C2_SDA	

SOFTWARE PROJECT

Project Settings : 
Project Name : printalyzer-cube
Project Folder : /home/octo/devel/printalyzer-cube
Toolchain / IDE : STM32CubeIDE
Firmware Package Name and Version : STM32Cube FW_F4 V1.25.2

Code Generation Settings : 
STM32Cube MCU packages and embedded software packs : Copy only the necessary library files
Generate peripheral initialization as a pair of '.c/.h' files per peripheral : No
Backup previously generated files when re-generating : No
Delete previously generated files when not re-generated : Yes
Set all free pins as analog (to optimize the power consumption) : Yes

Toolchains Settings : 
Compiler Optimizations :

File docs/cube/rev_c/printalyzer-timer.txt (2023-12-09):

Configuration	printalyzer-timer
STM32CubeMX 	6.10.0
Date	12/09/2023
MCU	STM32F411RETx

PERIPHERALS	MODES	FUNCTIONS	PINS
I2C1	I2C	I2C1_SCL	PB8
I2C1	I2C	I2C1_SDA	PB7
I2C2	I2C	I2C2_SCL	PB10
I2C2	I2C	I2C2_SDA	PB9
RCC	Crystal/Ceramic Resonator	RCC_OSC_IN	PH0 - OSC_IN
RCC	Crystal/Ceramic Resonator	RCC_OSC_OUT	PH1 - OSC_OUT
SPI1	Transmit Only Master	SPI1_MOSI	PA7
SPI1	Transmit Only Master	SPI1_SCK	PA5
SPI2	Transmit Only Master	SPI2_MOSI	PB15
SPI2	Transmit Only Master	SPI2_SCK	PB13
SYS	JTAG (4 pins)	SYS_JTCK-SWCLK	PA14
SYS	JTAG (4 pins)	SYS_JTDI	PA15
SYS	JTAG (4 pins)	SYS_JTDO-SWO	PB3
SYS	JTAG (4 pins)	SYS_JTMS-SWDIO	PA13
SYS	TIM11	SYS_VS_tim11	VP_SYS_VS_tim11
TIM1	Encoder Mode	TIM1_CH1	PA8
TIM1	Encoder Mode	TIM1_CH2	PA9
TIM3	PWM Generation CH3	TIM3_CH3	PB0
TIM4	Output Compare No Output	TIM4_VS_no_output1	VP_TIM4_VS_no_output1
TIM9	PWM Generation CH1	TIM9_CH1	PA2
TIM10	Enable_Timer	TIM10_VS_ClockSourceINT	VP_TIM10_VS_ClockSourceINT
TIM10	PWM Generation No Output	TIM10_VS_no_output1	VP_TIM10_VS_no_output1
USART1	Asynchronous	USART1_RX	PA10
USART1	Asynchronous	USART1_TX	PB6
USART6	Asynchronous	USART6_RX	PC7
USART6	Asynchronous	USART6_TX	PC6
USB_OTG_FS	Host_Only	USB_OTG_FS_DM	PA11
USB_OTG_FS	Host_Only	USB_OTG_FS_DP	PA12

Pin Nb	PINs	FUNCTIONs	LABELs
5	PH0 - OSC_IN	RCC_OSC_IN	
6	PH1 - OSC_OUT	RCC_OSC_OUT	
9	PC1	GPIO_Output	USB_DRIVE_VBUS [USB FS]
10	PC2	GPIO_EXTI2	USB_VBUS_OC [USB FS]
14	PA0-WKUP	GPIO_Output	BUZZ_EN1 [Piezo]
15	PA1	GPIO_Output	BUZZ_EN2 [Piezo]
16	PA2	TIM9_CH1	BUZZ_DIN [Piezo]
20	PA4	GPIO_Output	DISP_CS [Display]
21	PA5	SPI1_SCK	DISP_SCK [Display]
22	PA6	GPIO_Output	DISP_DC [Display]
23	PA7	SPI1_MOSI	DISP_MOSI [Display]
24	PC4	GPIO_Output	DISP_RES [Display]
26	PB0	TIM3_CH3	LED_OE [LED Driver]
27	PB1	GPIO_EXTI1	SENSOR_INT [Meter Probe]
28	PB2	GPIO_Output	SENSOR_VBUS [Meter Probe]
29	PB10	I2C2_SCL	
34	PB13	SPI2_SCK	LED_CLK [LED Driver]
35	PB14	GPIO_Output	LED_LE [LED Driver]
36	PB15	SPI2_MOSI	LED_SDI [LED Driver]
37	PC6	USART6_TX	DMX512_TX
38	PC7	USART6_RX	DMX512_RX
39	PC8	GPIO_Output	DMX512_TX_EN
40	PC9	GPIO_Output	DMX512_RX_EN
41	PA8	TIM1_CH1	ENC_CH1
42	PA9	TIM1_CH2	ENC_CH2
43	PA10	USART1_RX	
44	PA11	USB_OTG_FS_DM	
45	PA12	USB_OTG_FS_DP	
46	PA13	SYS_JTMS-SWDIO	
49	PA14	SYS_JTCK-SWCLK	
50	PA15	SYS_JTDI	
51	PC10	GPIO_Output	RELAY_SFLT [Safelight]
52	PC11	GPIO_Output	RELAY_ENLG [Enlarger]
55	PB3	SYS_JTDO-SWO	
57	PB5	GPIO_EXTI5	KEY_INT [Keypad]
58	PB6	USART1_TX	
59	PB7	I2C1_SDA	
61	PB8	I2C1_SCL	
62	PB9	I2C2_SDA	
PERIPHERALS	MODES	FUNCTIONS	PINS
I2C1	I2C	I2C1_SCL	PB8
I2C1	I2C	I2C1_SDA	PB7
I2C2	I2C	I2C2_SCL	PB10
I2C2	I2C	I2C2_SDA	PB9
RCC	Crystal/Ceramic Resonator	RCC_OSC_IN	PH0 - OSC_IN
RCC	Crystal/Ceramic Resonator	RCC_OSC_OUT	PH1 - OSC_OUT
SPI1	Transmit Only Master	SPI1_MOSI	PA7
SPI1	Transmit Only Master	SPI1_SCK	PA5
SPI2	Transmit Only Master	SPI2_MOSI	PB15
SPI2	Transmit Only Master	SPI2_SCK	PB13
SYS	JTAG (4 pins)	SYS_JTCK-SWCLK	PA14
SYS	JTAG (4 pins)	SYS_JTDI	PA15
SYS	JTAG (4 pins)	SYS_JTDO-SWO	PB3
SYS	JTAG (4 pins)	SYS_JTMS-SWDIO	PA13
SYS	TIM11	SYS_VS_tim11	VP_SYS_VS_tim11
TIM1	Encoder Mode	TIM1_CH1	PA8
TIM1	Encoder Mode	TIM1_CH2	PA9
TIM3	PWM Generation CH3	TIM3_CH3	PB0
TIM4	Output Compare No Output	TIM4_VS_no_output1	VP_TIM4_VS_no_output1
TIM9	PWM Generation CH1	TIM9_CH1	PA2
TIM10	Enable_Timer	TIM10_VS_ClockSourceINT	VP_TIM10_VS_ClockSourceINT
TIM10	PWM Generation No Output	TIM10_VS_no_output1	VP_TIM10_VS_no_output1
USART1	Asynchronous	USART1_RX	PA10
USART1	Asynchronous	USART1_TX	PB6
USART6	Asynchronous	USART6_RX	PC7
USART6	Asynchronous	USART6_TX	PC6
USB_OTG_FS	Host_Only	USB_OTG_FS_DM	PA11
USB_OTG_FS	Host_Only	USB_OTG_FS_DP	PA12

Pin Nb	PINs	FUNCTIONs	LABELs
5	PH0 - OSC_IN	RCC_OSC_IN	
6	PH1 - OSC_OUT	RCC_OSC_OUT	
9	PC1	GPIO_Output	USB_DRIVE_VBUS [USB FS]
10	PC2	GPIO_EXTI2	USB_VBUS_OC [USB FS]
14	PA0-WKUP	GPIO_Output	BUZZ_EN1 [Piezo]
15	PA1	GPIO_Output	BUZZ_EN2 [Piezo]
16	PA2	TIM9_CH1	BUZZ_DIN [Piezo]
20	PA4	GPIO_Output	DISP_CS [Display]
21	PA5	SPI1_SCK	DISP_SCK [Display]
22	PA6	GPIO_Output	DISP_DC [Display]
23	PA7	SPI1_MOSI	DISP_MOSI [Display]
24	PC4	GPIO_Output	DISP_RES [Display]
26	PB0	TIM3_CH3	LED_OE [LED Driver]
27	PB1	GPIO_EXTI1	SENSOR_INT [Meter Probe]
28	PB2	GPIO_Output	SENSOR_VBUS [Meter Probe]
29	PB10	I2C2_SCL	
34	PB13	SPI2_SCK	LED_CLK [LED Driver]
35	PB14	GPIO_Output	LED_LE [LED Driver]
36	PB15	SPI2_MOSI	LED_SDI [LED Driver]
37	PC6	USART6_TX	DMX512_TX
38	PC7	USART6_RX	DMX512_RX
39	PC8	GPIO_Output	DMX512_TX_EN
40	PC9	GPIO_Output	DMX512_RX_EN
41	PA8	TIM1_CH1	ENC_CH1
42	PA9	TIM1_CH2	ENC_CH2
43	PA10	USART1_RX	
44	PA11	USB_OTG_FS_DM	
45	PA12	USB_OTG_FS_DP	
46	PA13	SYS_JTMS-SWDIO	
49	PA14	SYS_JTCK-SWCLK	
50	PA15	SYS_JTDI	
51	PC10	GPIO_Output	RELAY_SFLT [Safelight]
52	PC11	GPIO_Output	RELAY_ENLG [Enlarger]
55	PB3	SYS_JTDO-SWO	
57	PB5	GPIO_EXTI5	KEY_INT [Keypad]
58	PB6	USART1_TX	
59	PB7	I2C1_SDA	
61	PB8	I2C1_SCL	
62	PB9	I2C2_SDA	

SOFTWARE PROJECT

Project Settings : 
Project Name : printalyzer-timer
Project Folder : /home/octo/devel/printalyzer-cube/firmware_b
Toolchain / IDE : STM32CubeIDE
Firmware Package Name and Version : STM32Cube FW_F4 V1.28.0

Code Generation Settings : 
STM32Cube MCU packages and embedded software packs : Copy only the necessary library files
Generate peripheral initialization as a pair of '.c/.h' files per peripheral : No
Backup previously generated files when re-generating : No
Delete previously generated files when not re-generated : Yes
Set all free pins as analog (to optimize the power consumption) : Yes

Toolchains Settings : 
Compiler Optimizations :

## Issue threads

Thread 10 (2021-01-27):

Develop a simple reflection densitometer probe

dkonigsberg, 2021-01-27:
It would be a nice addition if creating accurate paper profiles did not require expensive accessories. Creating a simple reflection densitometer "puck" that could use the same device port as the meter probe, would be one way of doing this.

Fundamentally, this puck could use the same sensor that is currently being used for metering. However, it would require more light-path control, and a light source shining at a 45 degree angle in the appropriate spectrum.

Figuring out how to do this could also be a starting point for an entirely separate project.

dkonigsberg, 2021-07-20:
For now, this is the goal of the related [Printalyzer Densitometer](https://github.com/dkonigsberg/printalyzer-densitometer) project.
In the event that a cheaper limited option is still required, it would be relatively simple to make a version of that device which lacks the user interface (display, extra buttons) and the transmission base.

dkonigsberg, 2024-02-27:
This task is still being considered, due to the necessity of such a device for making decent paper profiles and the fact that we cannot count on every potential user having a separate densitometer.

The current thoughts are to try prototyping something that would share a similar sensor head design as the Printalyzer Densitometer (DPD-100), but replace the rest with the absolute bare minimum of hardware.

This would involve:

- Small enclosure, with only two pieces (main unit and cover)
- Single button for control
- USB interface for power and control
- No microcontroller, just a USB<->I2C bridge chip (e.g. FT260)
- Simple way of controlling reflection LED brightness w/o a standalone PWM source
- All logic delegated to firmware on the base unit, and/or PC software.

The viability of this idea depends entirely on the price point.

Closed 2024-08-25.

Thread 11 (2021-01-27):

Add support for controlling LED-based enlargers

dkonigsberg, 2021-01-27:
This is something that isn't likely to be provided on the first "shipped" version of the Printalyzer, as it would require extensive changes to the way enlarger control is handled.

The basic idea is to be able to control enlargers that need something a bit more sophisticated than simply switching a mains power outlet on and off. The problem is that there is no real standard here, and every different build of an LED-based enlarger would likely need something slightly different. Its also hard to draw the line between what should work "out of the box" and what should require some customized electronics on the part of the user.

There are two main approaches that could be made to work for this:
- Have a port on the back with a series of GPIO outputs with PWM capabilities, hopefully robust against misuse, that can interface to any random hardware someone wants to build an adapter for. Doing it this way may unfortunately require the Printalyzer firmware to be customized to the peculiarities of what is being interfaced to.
- Have a more generic "enlarger control interface" port on the back, which uses a flexible I2C-style interface similar to the meter probe on the front. This could be done in addition to the existing relay-mains-control outlets, or instead of them. Then, a series of modules could be developed to connect to this port, with their own dedicated MCU and capable of speaking a common protocol. These modules could be made in enlarger-type-specific variants, or even individually programmed based on what the user wants to do.

dkonigsberg, 2023-08-29:
The latest hardware/firmware now has a DMX512 control port, which is designed to be used for this purpose.

Closed 2023-08-29.

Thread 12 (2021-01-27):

Fix crosstalk issues on level-shifted front port signals

dkonigsberg, 2021-01-27:
Crosstalk issues have been observed between the front port signals that pass through `D13` (DT2636-O4S) for ESD protection, and are then level-shifted by `Q1`/`Q2`/`Q3`.

Most notably, switch bouncing seems to be the source of the crosstalk. It is mostly ignored by the TCA8418 keypad controller, but it is detected by the GPIO interrupt handler for the `SENSOR_INT` signal.

It is unclear where exactly this crosstalk is happening, however there are enough places where traces are close or crossing around these components that a PCB layout change might solve it. Adding series resistors on some of these input lines may also help. Finally, it may be a good idea to do some breadboard/scratch-PCB tests to really get to the bottom of this.

Thankfully, this issue is not causing any real problems for the system. However, it should still be fixed before a new revision of the PCB is made.

dkonigsberg, 2021-02-23:
Did some initial testing on this by triggering the footswitch, and measuring the signals at its level shifter (Q3) and the adjacent level shifter (Q1).

With a straight-through connection, triggering the footswitch induces over 2V of noise on the traces around Q1.
Adding 20 ohms of series resistance to the footswitch connection reduces that noise to around 1.4V.
Adding 34 ohms of series resistance reduces the noise dramatically, but not completely.
Adding 68-100 ohms of series resistance reduces the noise to a minor glitch that is still visible, but likely not problematic.
Adding 270 ohms of series resistance makes the noise go away completely.

It will take some more research to decide how much series resistance to actually add, and which of the input lines to add it on. However, it should be added and it does help solve the problem.

dkonigsberg, 2023-06-13:
Added series resistors in many places, and debouncing capacitors in other places, so this problem should be solved for the Rev B prototype.  Will reopen the issue if its not.

Closed 2023-06-13.

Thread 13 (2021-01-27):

Change LQFP-64 footprint for U4

dkonigsberg, 2021-01-27:
The footprint used for `U4` (STM32F411RET6) is currently the KiCad default for this package, which is likely script-derived from IEC standards. It differs from the footprint shown in STM's own datasheet for the component, which has shorter pads that don't extend as far under the IC.
During human-assembly, the vast majority of issues came from solder bridging that occurred on or around the pins of this IC. Therefore, a future revision should switch to using STM's footprint which may be less susceptible to the issue.

dkonigsberg, 2023-06-13:
Footprint updated on the Rev B prototype.

Closed 2023-06-13.

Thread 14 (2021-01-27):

Review main board trace clearance near screw holes

dkonigsberg, 2021-01-27:
There are a few places on the main board where traces seem to get a little too close to screw holes. Most obviously this has been seen near the `J2` debug connector, but it may exist in other places as well. Some cleanup of this should be done before the next PCB revision is manufactured.

dkonigsberg, 2023-06-13:
The Rev B main board was almost completely rerouted, so closing this issue for now.

Closed 2023-06-13.

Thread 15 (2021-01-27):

Reduce the sensor-to-surface distance in the meter probe

dkonigsberg, 2021-01-27:
The relationship between the meter probe PCB and the meter probe enclosure has a sensor-to-surface distance of approximately 5.96mm. However, the theoretical minimum (taking sensor package and translucent overlay thickness into account) is 0.62mm.

I think the current design limits sensor visibility to an angle of approximately 23 degrees, which might be sufficient, but we should be able to do better.

The next revision of the meter probe enclosure should make more of an effort to reduce the thickness of the enclosure about the sensor. This may be difficult due to the inherent thickness of the heat-set screw inserts used to hold the shell together, unless the front of the device is redesigned to use clips/tabs to hold itself together.

(Getting clips/tabs to work properly may be difficult with the tolerances of home FDM 3D printing, but may work fine with commercial multi-jet-fusion 3D printing.)

dkonigsberg, 2023-09-08:
Closing as this is just general design guidance at this point, and not a specific task.

Closed 2023-09-08.

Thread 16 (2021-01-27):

Improve centering of the light sensor on the meter probe PCB

dkonigsberg, 2021-01-27:
The actual sensor element inside the TCS3472 sensor IC is offset from the center of the device. It probably makes sense to tweak the PCB layout to make sure the sensor element itself is centered under the enclosure's sensor aperture, rather than just centering the IC.

The positional shift here is small fractions of a millimeter, but it still probably makes sense to do for the next PCB revision.

dkonigsberg, 2023-06-13:
The TSL2585 datasheet does not provide sufficient geometric details to do this correctly, so the current positioning is based on assumptions from the provided diagrams.  Keeping this task open for now, even if there's not much more than can be done at the moment.

dkonigsberg, 2023-09-08:
Closing as this is just general design guidance at this point, and not a specific task.

Closed 2023-09-08.

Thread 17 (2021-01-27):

Add a small I2C EEPROM to the meter probe PCB

dkonigsberg, 2021-01-27:
The design of the Printalyzer was always intended to support a variety of different meter probes, and to allow iteration on the meter probe design. However, the base unit currently has no way to actually detect what specific meter probe is connected beyond the I2C responses from the sensor itself. Since different revisions of the meter probe may use the same sensor, but different enclosures (and thus have different calibration constants), this presents a problem.

Incorporating a small I2C EEPROM directly into the meter probe would add minimal cost, but would allow both meter probe identification and sensor calibration data to be stored inside the probe itself.

For this EEPROM, there are two basic options:
- Memory with a dedicated "ID" page that can contain meter probe model/revision/serial information and then be permanently locked as read-only.
- Regular memory where all of it can be overwritten, but the firmware tries really hard to make it impossible for a normal user to overwrite the "ID" information stored at the start of the memory.

There is a cost difference between these two components, so that decision is TBD for now. However, it is possible that switching between them would require no other hardware or software changes that affect normal operation.

dkonigsberg, 2023-06-13:
Added a M24C02-D I2C EEPROM in the Rev B prototype.

Closed 2023-06-13.

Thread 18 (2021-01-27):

Review power bypass capacitor arrangement for the TCS3472

dkonigsberg, 2021-01-27:
The current design of the meter probe PCB uses a single 0.1uF 0603 capacitor on the Vdd pin of the sensor IC.

Other designs incorporating this sensor appear to show 3 different possible configurations:
https://imgur.com/gallery/W6HvW9M

- Most breakout board designs use a single 0.1uF capacitor as I'm using
- Most AMS datasheets show an example with a 1uF capacitor that they say should be low-ESR
- The official evaluation board for the sensor shows a 1uF bypass capacitor and a 22 ohm resistor to power, with a note saying that both should be 0402 sized

It is still somewhat unclear which is the best approach. I suspect the evaluation board is doing a low-pass filter on the sensor power, which may or may not be necessary in this case.  I may just switch to the design from the evaluation board out of paranoia, but none of this may actually matter.

dkonigsberg, 2023-05-02:
No longer relevant due to #34

Closed 2023-05-02.

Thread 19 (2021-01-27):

Consider adding ESD protection to the meter probe cable input

dkonigsberg, 2021-01-27:
While the main board has ESD protection on all of its external inputs, the meter probe does not have any. Thus, it is possible that incorrectly touching the plug while handling a disconnected probe could cause an issue.

It is probably good practice to add ESD protection components to this PCB, right near the wire-to-board cable connection. However, more research on the design of similar devices is likely to be a good idea.

dkonigsberg, 2023-06-13:
Added numerous TVS components in the Rev B prototype.

Closed 2023-06-13.

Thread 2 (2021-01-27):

Implement a delay period at the start of a burn/dodge exposure

dkonigsberg, 2021-01-27:
When doing burn/dodge exposures, the user will likely need to prepare various tools to cover areas of the print. It is sometimes difficult to do this at the same time as pressing a button on the Printalyzer, especially if not using the foot pedal.

There should be a short delay, accompanied by a notable countdown-style beep, at the start of a burn/dodge exposure. This will enable the user to "get ready" before the enlarger lamp switches on.

Since not all users will need this, especially those using a foot pedal, it should probably be configurable via settings.

Closed 2021-03-10.

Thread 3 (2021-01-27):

Easy way to switch paper profiles from the home screen

dkonigsberg, 2021-01-27:
Since paper profiles are likely to be changed/selected more frequently than enlarger profiles, there should be an easy way to switch between the **active** profile that does not require going into the menus and changing the **default startup** profile.

This could be done by changing the behavior of the "Menu" button so that a short press brings up profile selection, while a long press goes into the menus. However, there are probably other methods that would also work.

Once selected, there should be a clear indication of the active profile from the home screen so that the user always knows which one they are using. Since there isn't really enough screen space to elegantly display actual text, this will most likely need to be a decorated number similar to how burn/dodge exposure counts are shown.

Closed 2021-03-09.

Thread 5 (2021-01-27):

Ability to build paper profiles from a series of densitometer measurements

dkonigsberg, 2021-01-27:
There should be a something in place that can take a series of densitometer measurements of Dmin/Dmax and a step-wedge exposure (along with the corresponding PEV), and then do all the necessary math to figure out reference points and build a paper profile.

This will require the ability to select the step wedge that has been used, which can be done via the following methods:
- Select from a list of known Stouffer step wedges
- Enter a series of standard parameters (e.g. number of steps, density increment per step)
- Fine-tune patch density with densitometer measurements

Then, there needs to be a UI for inputting the following values:
- Paper Dmin and Dmax
- Wedge exposure PEV
- Per-patch density measurements
The Dmin value should probably be optional, if the other density measurements are relative to the paper base and not absolute. (This is probably the same as just saying in the documentation that it can be left as 0 in that case.)

dkonigsberg, 2021-02-19:
The bulk of this feature has now been done:
13b4da88962db26825fae387ef87bc35085bf3e9
5543488dfd4d5962c2db1c49b24a0d8aac416be4
8211c515b68a61e3df916b7c2e0714ccc8537508
e26ab17509535cd6231ce6ccb0e50c872b4a72ac

The only remaining must-have item is the ability to change the Calibration PEV target between what makes sense for a D=0.04 exposure test (~30) and what makes sense for a step wedge exposure test (~200).

dkonigsberg, 2021-03-09:
7b162603046de03f5aa7568f1ae371f50994124e
Completed ability to toggle between two different PEV targets in calibration mode.

Closed 2021-03-09.

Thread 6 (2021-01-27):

Interface for communicating with various densitometers via the USB port

dkonigsberg, 2021-01-27:
This feature is an internal interface layer that is primarily needed to support #5 .

Various densitometers have mechanisms for interfacing with a computer to ease data input for processing measurements. They primarily do this via a serial-like interface. To make step-wedge-based paper profiles a lot less tedious to create, we should support this whenever possible.

For starters, using the USB port on the Printalyzer, it should be possible to directly capture readings from the following two densitometers:
- Heiland TRD-2 /w USB option
  - Presents itself as a USB serial port
  - Has a fairly simple protocol where it streams readings
- X-Rite 810TR
  - Has an RS-232 serial port on the back
  - Should be able to use a common USB-to-Serial adapter to interface with this (not sure if that code can be universal, or if it'll need specific support for specific chipsets)
  - Has a more sophisticated interface, where we can control the device's modes and take readings

dkonigsberg, 2021-01-31:
The actual serial interfaces for both of these densitometers are almost trivial to handle.
The real challenge appears to be that USB serial interfaces are not USB CDC class devices with existing support, and tend to use a vendor-specific device class. So, a prerequisite to adding this feature is implementing drivers for relevant popular USB serial chips.

As both the TRD-2 and my spare USB-to-Serial adapters use the FTDI FT232R chip, it probably makes sense to focus on support for that as a first step.

dkonigsberg, 2021-02-09:
USB<->Serial adapter support added by:
8f39fe3e4f696fdabf6a5ff56dc742bcab0c58be
c6ba9401a1326361b2ecbd35e770a2da240a4940
c92295699a10020d62b87e4733b849f8173a264a
894a3f0dc69531b906cc4c6330b4b1fb60d6c766
59690e0fd5dfe73d8c142b0391324d747fe70d15
1a5529376789b01d827b437e531bbedd0742e59b
cf627fea2c7d3e3f12102f26b0492aa7e92eeea4
a864b34d06475cab1e2a191ce63983a1a6d96d49

Closed 2021-02-11.

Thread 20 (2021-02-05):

Use an upside-down USB connector on the main board

dkonigsberg, 2021-02-05:
The main board is mounted upside-down inside the enclosure, to provide proper clearance for all the components and positioning for the various ports.  Unfortunately, this means that any PCB-mounted connectors are also upside-down.

This isn't a big issue, but it would be nice if any "top" markings on peripheral connectors didn't appear to be facing the wrong way when being plugged in.

Given that they apparently make PCB-mount USB-A receptacles that are inverted, it would make sense to use one of those on the board.

It would be nice if this could also be done for the Mini-DIN meter probe connector as well, but I have not seen any such receptacles available.

dkonigsberg, 2023-03-20:
So they apparently don't make inverted USB-A receptacles.  Such parts are mostly just for mini/micro-USB.
Closing this unless some are discovered.

Closed 2023-03-20.

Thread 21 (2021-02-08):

Some USB-to-serial adapters send garbage when first connected

dkonigsberg, 2021-02-08:
This issue has been observed with both the FTDI FT232R and SI CP2102 adapters that have been tested, but does not appear to happen with the PL2303 adapter.

Whenever one of these adapters is plugged in and powered up, a garbage character (typically 0xFF) is sent out its serial port. After this, it seems to behave normally. (This does not happen when connecting the same adapters to the USB ports of any of my computers.)

Attempting to narrow down the cause via firmware tinkering seems to correlate this behavior to toggling the VBUS connection. If everything else about the USB port is disabled, except for that, toggling the associated GPIO triggers the issue.  The most likely root cause is some sort of transient on the VBUS line, or nearby interference. This will need to be debugged with an oscilloscope to be sure of what is going on.

In a worst case scenario, this issue can likely be worked around. It will confuse certain X-Rite densitometers, but their serial interface can be recovered by sending the right command to them.

dkonigsberg, 2021-02-23:
After some lab testing, it isn't clear that this issue has an obvious cause or is worth fixing.

It seems like the cause could very well be an extreme sensitivity (only at startup) to power supply (or ground) behavior/noise in a way that's proving hard to pin down.

When powering the dongle via a quality bench supply, the issue does not manifest the majority of the time. However, it still does happen on rare occasion.

While this issue does not happen if the FT232R dongle is plugged into one of my desktop's USB ports (as stated above), it absolutely does happen if I plug that same dongle into one of my laptop's USB ports. Therefore, it may be practically unavoidable.

If this issue is left unfixed, then a comment should be added to the user manual.  If the dongle is connected to a densitometer in output-only mode, this issue does no harm. However, if that densitometer has remote-control enabled, it may lock up the local user interface. It is possible to unlock that interface via the remote control serial protocol, but only once we actually start supporting that protocol.

dkonigsberg, 2023-09-08:
Closing as this is likely just a known issue with these parts, and not something that can be resolved.

Closed 2023-09-08.

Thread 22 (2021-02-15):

Add cancel-confirmation to menu screens

dkonigsberg, 2021-02-15:
There are many menu screens, especially in the profile editor areas, where saving is an explicit action at the bottom of a list. However, cancel is a simple button press that is easy and natural to trigger.

These screens should make an effort to detect when the user has made a change, and prompt before letting them cancel. Otherwise, there will be many cases where they think they changed a setting, didn't save it, and wonder why it didn't take effect.

Closed 2021-03-09.

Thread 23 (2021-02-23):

Add features to bootloader

dkonigsberg, 2021-02-23:
This is a follow-on task for #9, and mostly a tracker for wishlist features.

The initial bootloader is fairly basic, and mostly focuses just on the success path of getting a firmware image from a USB stick into flash. It means the minimum requirements, but is far from ideal. Before it can be deemed "complete and ready for primetime" there are some features that should probably be added:

- Implement key event handling for u8g2 to enable actual menus and button-prompt messages.
- Provide Okay/Cancel/Yes/No type prompts at various stages of the firmware install process
- Implement an actual file-list capability from reading the USB stick, such that the firmware need not always match a magic name. This will enable giving firmware images a version-based name and allowing the user to select between different images on the same stick.
- Consider adding some sort of metadata block to firmware images, so that the bootloader can display/verify more detailed information than a simple size and checksum. This may also help prevent loading of arbitrary data or data meant for a different target device.
- Consider a bootloader menu with some extra features, and possibly even a reserved page of EEPROM for persisted bootloader settings (e.g. enable/disable checksum, enable/disable firmware features that should be completely hidden from the firmware when not enabled by the bootloader).

The bootloader is the one component of the system that is essentially fixed in stone once the Printalyzer goes to a normal end-user, so making it "complete" prior to launch is a requirement. If that can't be done, then at least the firmware image format needs to be fixed in stone.

dkonigsberg, 2021-02-28:
The bootloader should check if the selected image on the USB stick matches the already-loaded firmware, and prevent (or warn) if the user tries to reinstall. This will make things easier before actual image versioning/selection is fully implemented.
Checksum verification can be used to make sure re-flashing corrupted firmware is still possible.

dkonigsberg, 2023-12-18:
Several minor tweaks to the bootloader code:
c20b7cc42736e02bdf5625c1c28896fdbd51f638
e451859c358f035950c923cc7c6ceae497c6218f
410bb24e9bcb13e39764709400dca801c6583abb
3d0756bd93f90e156e111c5c2fecc2ecf4b875d1
4a322cf6c6cfb84aff7d78472d3623cb75d40f19
c775bd0f646d28b603fc18bf85448c641befd60f

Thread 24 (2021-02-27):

Upgrade STM32F4 firmware package code from V1.25.2 to V1.26.0

dkonigsberg, 2021-02-27:
ST has upgraded the firmware package distributed with their CubeMX tooling, so we should upgrade the relevant bits of it that have made their way into our codebase.  While doing this for the "firmware" and "bootloader" modules are technically separate tasks, right now they can be taken care of under a single issue. (In the future, the "bootloader" will likely be maintained separately and less frequently.)

The most notable change is moving FreeRTOS from v10.2.0 to v10.3.1.  In addition, they bumped the USB library and some parts of the HAL. However, the majority of the changes (as far as we're concerned) appear to be general housekeeping on the codebase.

This update will be a good opportunity to update the CubeMX code import script, and to improve documentation of any code changes that have been made from the stock framework. The most notable changes are in the USB library and USB HAL interrupt handler to deal with serial adapter integration issues.

In addition to changes that CubeMX will put into a code re-generate output, there may also be changes (including some minor 'system_stm32f4xx.c' updates) that will not appear automatically. Therefore, some care should be taken to review these.

dkonigsberg, 2021-02-28:
It may make sense to take the USB host library off the firmware package release and update to the latest actually posted on Github:
https://github.com/STMicroelectronics/stm32_mw_usb_host

This is one point release past what's included in the STM32F4 firmware package, and includes the majority of minor fixes already made in our own code to resolve compiler warnings.

Closed 2021-03-01.

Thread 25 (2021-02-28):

Improve user indication/handling of short exposure times

dkonigsberg, 2021-02-28:
Enlarger profiles attempt to compensate for ramp-up/ramp-down time during exposures, which should theoretically make short exposures (especially for test strip increments) more consistent. However, they can also end up imposing a minimum exposure time.
When trying to use a time below this minimum, there should be some sort of warning and/or behavior change on the device. This situation is most likely to happen on incremental test strip creation, but is technically possible for normal exposures as well.

For test strips, possible solutions include:
- Prevent creation of test strips with increments that are too short
- Switch test strip mode from incremental to to separate exposures
- Block off sections of the test strip so only portions that can be exposed correctly are created

For normal exposures, a simple limit or warning will suffice.

Closed 2023-08-29.

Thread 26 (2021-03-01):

Add a "densitometer" mode to the meter probe

dkonigsberg, 2021-03-01:
This would be a special mode just for measuring relative density changes across the projected negative. You would switch to it from the same selection system used to toggle between "Printing" and "Calibration."

Basically it keeps track of the lightest area measured, then shows a density reading relative to that as you meter across the image. This would be a fairly simple thing to implement, and would not require keeping track of any state beyond the lowest and most recent measurement.

Closed 2021-03-01.

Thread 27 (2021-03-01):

Display color head filter settings for the selected contrast grade

dkonigsberg, 2021-03-01:
When using a color enlarger, it is possible to use the dichroic filter controls on the enlarger head to select output equivalent to a known contrast grade. However, doing this often requires referencing a chart that is often posted on or near the enlarger head.

It may be useful for the Printalyzer to directly display these numbers, below the selected contrast grade on the main display.
There are a few different schemes for these filters, but lookup tables for all of them can be integrated.

The main question to answer is how this should be configured.  Does it make more sense as a global setting, as part of an enlarger profile, or as part of a paper profile?

It is a property specific to an enlarger, but the same enlarger can be used with either dichroic filtration or standard over/under-the-lens multigrade filters.

However, due to effects on exposure (and thus the paper profile), it may actually make sense to put this setting in the paper profile properties.

Closed 2021-03-14.

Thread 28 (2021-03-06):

Improve wire-to-board cable connection for the meter probe

dkonigsberg, 2021-03-06:
The process of attaching the cable to the PCB is currently quite difficult and time consuming. One must manually strip all the conductors, carefully feed them into the holes, and solder them in place. This is a bit fiddly to get right, and soldering for too long can melt insulation.

Using Molex/JST type connectors can work, but the tooling to do this easily may not be available. So this option may have to be a backup choice.

They do also apparently make IDC-type connectors that could be used for this purpose, such as these product lines from AVX:
https://www.avx.com/products/connectors/wire-to-board/idc-connectors-14-28-awg/

These IDC-type connectors may end up being the easiest option, if they work out.

dkonigsberg, 2023-06-13:
Fixed for the Rev B prototype with Kyocera AVX 009175003001006 IDC connectors, which let the captive cable wires get attached with a simple punch-down tool.

Closed 2023-06-13.

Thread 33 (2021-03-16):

Add temporary spot metering to the burn/dodge adjustment editor

dkonigsberg, 2021-03-16:
This is a feature that may make the user experience of adding a burn/dodge adjustment a lot nicer.

When in the adjustment editor, if the enlarger lamp is on, the meter probe button should take a reading. However, this reading should not go into the main exposure state. Rather it should be placed as an "overlay" on the current tone graph (possibly drawn in a slightly different style from the other marks). It will then be possible to visualize what the adjustment does to a specific point of interest.
Taking additional readings can just replace this highlighted one, rather than overlay a completely separate tone graph. Furthermore, there is no need to persist this reading as part of the configured adjustment state.

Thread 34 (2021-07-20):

Select alternative sensor to replace the TCS3472

dkonigsberg, 2021-07-20:
The [TCS3472](https://ams.com/tcs34725) sensor has recently been discontinued by the manufacturer. As such, a new sensor is going to need to be selected for this project's meter probe.

If it still makes sense to stick with a similar RGB-type sensor, then the most direct replacements appear to be the [TCS3400](https://ams.com/tcs3400) and the [TCS3410](https://ams.com/tcs3410).

Alternatively, a non-color sensor such as the [TSL2572](https://ams.com/tsl25721) could work.

Regardless, any alternate sensor must retain the quick integration time capability for enlarger profiling, and also have adequate low light sensitivity under darkroom conditions.

It is also probably worth testing the placement of a UV/IR cut filter in the optical path, if that improves the quality of readings from the sensor across a variety of conditions.

dkonigsberg, 2023-06-13:
Going with the TSL2585 for the Rev B prototype.

Closed 2023-06-13.

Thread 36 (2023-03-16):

Finalize power board layout and component selection

dkonigsberg, 2023-03-16:
This task is basically a placeholder to cover a potentially endless process of nitpicking that needs to be put aside to make real progress on the rest of the project.  This issue is to cover any changes after commit ae0389b94e9373f0d56c7953cbd01af74e56ad83, and refers to process in the context of the state of things at the time of that commit.

The power board has a number of elements for which we can spend an endless amount of time changing our minds, which include:

- Whether to use Bulgin or Schurter IEC320 connectors (latest update is Schurter)
- Which connector to use for connecting the power switch wires (currently using Molex 768290002, Mega-Fit dual-row series)
- Exactly where to position the power switch wire connector, due to mechanical clearance concerns
- Which AC/DC converter to use, though the current choice (Cincon CFM06S120-E) seems to be a good fit. Alternatives include the CUI PSK-6B-S12 or the Mean Well IRM-10-12.
- Exactly which board-to-board connectors to use, though the current JST selections are probably fine. Still unsure whether to use the horizontal or vertical variants, however.
- Exactly where to position the two relays, the internal fuse holder, etc.
- Exactly where to position the J2 connector and the post-AC/DC-converter components.
- Whether there should be a net tie between U2's ground pin and the chassis ground plane

For such a simple board, this is one area where extensive nitpicking is important.  This is the only part of the product with a safety concern, so it has to be right.  Also, the design/layout will have to be followed up with the assembly of a complete documentation package that includes component data and approval records.

dkonigsberg, 2023-06-13:
Finalized for the first prototype build.  May nitpick further in the future, but it should be good enough for now.

Closed 2023-06-13.

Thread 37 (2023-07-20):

Fix power side-effect with level shifting circuitry for meter probe interface

dkonigsberg, 2023-07-20:
A portion of the meter probe interface's level shifting circuitry, specifically the part used for the sensor interrupt pin and the probe button, is based around a particular [BSS138 circuit](https://cdn-shop.adafruit.com/datasheets/AN10441.pdf).

While this circuit is simple, and generally works, it has one major problem.  If the +3.3V rail is live, but the +5V rail is off, then some amount of voltage leaks through to the +5V side.  This seems to cause the `PROBE_VBUS` net to maintain a constant voltage of around +2.8V when the meter probe port power (`PROBE_DRIVE_VBUS`) is explicitly turned off.

That is just enough voltage to cause the meter probe button to work, even if the meter probe should be off.  It might not be enough for the rest of the meter probe to function in this state, but its not a chance worth taking.

This problem absolutely needs to be solved for the next hardware revision, and there are a number of possible approaches:

- Add the ability to control the +3.3V supply to the BSS138 level shifters
- Switch to using a dedicated level shifter IC, such as the [TXS0102](https://www.ti.com/product/TXS0102) or [LSF0102](https://www.ti.com/product/LSF0102) which offer a cleaner way to enable/disable their functionality

It might also make sense to put the next revision on hold, pending a change to the availability of the PCA9527 bus extender, as using that part would reduce the number of lines we need to care about here from 2 to 1.

dkonigsberg, 2023-09-12:
The path forward with this is going to involve changing components in two areas of this interface.
First, the I2C bus portion will be switched from the [TCA9517A](https://www.ti.com/product/TCA9517A) to the [PCA9527](https://www.nxp.com/products/interfaces/ic-spi-i3c-interface-devices/ic-bus-repeaters-hubs-extenders/three-channel-bidirectional-bus-extender-for-hdmi-ic-bus-and-smb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).  The latter IC was initially avoided due to part availability issues, but its now starting to become available from the usual vendors. Its overall a better choice, for a number of reasons:

- It can handle SCL, SDA, and the interrupt line, whereas most other ICs can only do SCL/SDA
- The way it does dynamic pull-ups does not appear to cause line ringing, and is safe to use on the 5V side that goes across the cable
- Because of how they can be paired, up to 1400pF of capacitance can be okay on the cable, providing plenty of headroom.
- Various app notes point to this IC as the currently recommended solution.

The likely implementation will somewhat resemble this example from the datasheet:
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

Second, the approach taken for level-shifting the button will now be changed.  We no longer need to worry about the interrupt line, due to the above IC, so that helps somewhat.  The problem with the popular "bi-directional" BSS138 level shifter circuit is that it doesn't handle the case of the 5V rail being turned off.  The new approach will still use the BSS138, but in a different configuration that will no longer place a voltage on the button output when the 5V rail to the meter probe port is disabled.  Furthermore, this new approach should probably also be applied to the footswitch port.

This alternate circuit looks something like this:
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

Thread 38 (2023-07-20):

Move footswitch connector off the main board

dkonigsberg, 2023-07-20:
Rev B of the main board moved the footswitch connector from a panel-mount jack to a PCB-mount jack on the edge of the board.

This seemed like a good idea in theory, but in practice it makes it impossible to actually install the PCB into the updated L-shaped enclosure design.

Thus, we need to go back to the old design, which most likely means putting a 2-pin JST PH style connector on the main PCB, and connecting a panel-mount footswitch connector via a pigtail wire.

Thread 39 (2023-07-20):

Replace AC/DC converter brick on the power board

dkonigsberg, 2023-07-20:
The current (Rev A) power board uses a [Mean Well IRM-10-12](https://www.meanwell-web.com/en-us/en-US/ac-dc-single-output-encapsulated-power-supply-irm--10--12) AC/DC converter brick.  While this part does work, it unfortunately has terrible EMC performance and would likely cause the unit to fail a conducted emissions test.  Using it would likely necessitate additional filter components on the power board, which would add cost and complexity.

As of the latest round of testing, the most likely candidate to replace this part is the [Recom RAC10E-K/277](https://recom-power.com/en/products/ac-dc-power-supplies/ac-dc-pcb-mounted/rec-s-RAC10E-K!s277.html).  So far, it seems to have significantly better EMC performance on a conducted emissions test, and may end up meeting all the requirements as-is without additional filtering.  Furthermore, it has the same size, footprint, pin-out, and cost as the IRM-10-12, so its essentially a drop-in replacement.

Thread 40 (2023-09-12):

Change RS-485 transceiver from MAX3075EESA+ to THVD1439DR

dkonigsberg, 2023-09-12:
This is mostly a drop-in part swap, changing from the MAX3075EESA+ to [THVD1439DR](https://www.ti.com/product/THVD1439/part-details/THVD1439DR) for cost reasons.

dkonigsberg, 2023-09-12:
The THVD1439 datasheet also has recommendations for layout and pull-up/pull-down resistors that should be followed.

Closed 2023-09-19.

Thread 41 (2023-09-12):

Reduce power board width as much as possible

dkonigsberg, 2023-09-12:
Reduce board width by as much as possible, even if only a few millimeters can be taken out.  The idea is to maximize how much we can then reduce the width of the overall enclosure, since the current prototype is a lot wider than the original prototype.

There's at least a millimeter that can be taken off either side.  There may also be a few mm between connectors that can be taken out, but care must be taken to avoid risk of clearance issues.

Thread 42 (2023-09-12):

Change encoder part to increase various height dimensions

dkonigsberg, 2023-09-12:
The current design specs a CUI encoder with a 5mm threaded section and a 15mm overall height.

Recommend switching to the Bourns PEC11L-4120F-S0020, which offers a 7mm threaded section and a 20mm overall height.  The goal is to increase the number of threads that poke above the top of the enclosure, and improve fit of the encoder knob.

As part of this change, the footprint should also be reviewed to ensure there's sufficient copper around the mechanical pin pads.  They were a little thin on the last prototype.

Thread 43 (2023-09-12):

Fix power test points on the main board

dkonigsberg, 2023-09-12:
Move, remove, or replace the power test points on the main board.  The current ones hit the back of the display module, and the PCB should really be completely flat on the back-side in that area.

Closed 2023-09-19.

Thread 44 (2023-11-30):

Select alternative config EEPROM for the main board

dkonigsberg, 2023-11-30:
The current I2C EEPROM being used for this purpose is the ST [M24M01-R](https://www.st.com/en/memories/m24m01-r.html), which is now marked as "not recommended for new designs."  It is a 1Mbit (128kb) part.
There does seem to be plenty of vendor stock out there, but for the sake of future-proofing it is probably best to select something else.

This is a fairly standard type of component, so finding a drop-in replacement should hopefully be easy.  Either the same capacity, or larger capacity, depending on what is out there.

dkonigsberg, 2023-11-30:
The most obvious alternative seems to be the brand-new [M24M01E](https://www.st.com/en/memories/m24m01e-f.html) series, which adds additional features and seems to sell for a much lower price.

dkonigsberg, 2024-01-24:
Another option is the onsemi [CAT24M01](https://www.onsemi.com/products/timing-logic-memory/memory/eeprom-memory/CAT24M01), which may be a more direct drop-in replacement.

dkonigsberg, 2024-02-27:
Changed EEPROM to CAT24M01, since its the most direct drop-in replacement.

Closed 2024-02-27.

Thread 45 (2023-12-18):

Add display settings

dkonigsberg, 2023-12-18:
Some elements of how information is displayed on the device should be configurable, as a first step toward some sort of localization and customizability.

The first item that should be added here, is a configurable decimal separator.  (Similar to [this feature](https://github.com/dektronics/printalyzer-densitometer/issues/51) from the densitometer firmware.)

Actual internationalization of the UI, especially the menu text, might be a good idea in the future. However, doing it right adds a lot of complexity to the development process.  As such, it might make sense to just focus on things like display formats for now.

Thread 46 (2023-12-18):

Remove button-embedded indicator LEDs from the buttons on the right side

dkonigsberg, 2023-12-18:
The cluster of buttons on the right side of the device (add-adjustment, test-strip, menu, and cancel) all currently have embedded indicator LEDs.  The purpose of these LEDs was as a way of indicating device state, whereas all the other LEDs across the top panel are primarily for indicating button location when in a darkroom environment.

However, as development of the device as proceeded, two issues have come up against these supplemental LEDs:

1. Indicator lights in these buttons don't directly correspond to any sort of obvious device state, and any state we would want to indicate does not obviously correlate to these buttons.
2. The particular red LEDs in these buttons (chosen by the switch manufacturer) fail the paper-safety test with Foma B&W paper.

As such, we might as well get rid of them.
In specific, this means replacing all the Marquardt 6425.3111 buttons on the device with the LED-free Marquardt 6425.0101 buttons used elsewhere.

It might make sense to add additional state indiciator LEDs, outside of buttons, elsewhere on the panel. However, a decision on that is still TBD.

dkonigsberg, 2024-02-27:
Changed buttons and added suggested panel LEDs elsewhere.

Closed 2024-02-27.

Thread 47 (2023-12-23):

Improve return path layout around display module on the main board

dkonigsberg, 2023-12-23:
The layout around the display module connector on the main board could use some improvement.  The ground plane should surround the connector more closely, perhaps even on the directly adjacent layers, and general routing of the SPI signals should be improved with careful attention to the return path.

Since the largest source of radiated emissions in preliminary testing appears to be the harmonics of the display's SPI frequency, and because probing has shown that its most strongly emanating from that connector, this is simply a place where its better to be paranoid than otherwise.

dkonigsberg, 2023-12-23:
Just a quick update...  Dropping the GPIO speed for the SPI pins from "Medium" to "Low" seems to resolve the emissions spikes, with no obvious downsides.  However, some of this is still probably a good idea to look into for the next board revision.

dkonigsberg, 2024-02-27:
Some minor changes implemented that should help, but there's a limit to what's practical here.

Closed 2024-02-27.

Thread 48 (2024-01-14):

Improve main power switch connection

dkonigsberg, 2024-01-14:
Originally the power switch was connected by wires soldered directly to the PCB.

In Rev B, those wires were changed to connect via [Weidmüller 1825960000](https://catalog.weidmueller.com/catalog/Start.do?localeId=en&ObjectID=1825960000) wire-to-board connectors that use a spring-fit action.  In practice, its difficult to get these sufficiently secure with stiffer wires across a relatively short distance.

Upon further investigation, it seems like the connection point can be moved to the opposite side of the internal fuse, for less cramped wire routing.
Additionally, switching to an actual plug-in-socket connector should provide a much safer and more reliable connection.  The current top candidate is the [Molex Mega-Fit](https://www.molex.com/en-us/products/connectors/wire-to-board-connectors/mega-fit-connectors) series, with a variant that has the necessary approvals and for which pre-made cable assemblies are available.

Closed 2024-02-27.

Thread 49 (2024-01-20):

Convert meter probe interface to USB

dkonigsberg, 2024-01-20:
The current meter probe interface uses a form of buffered I2C over a cable with a 6-pin [Mini-DIN](https://en.wikipedia.org/wiki/Mini-DIN_connector) connector.  This has the advantage of being able to leverage cables left over from the era when PS/2 keyboards and mice were common in PCs, but it also has a number of disadvantages:

- Attaching the cable inside the device requires separating many wires, carefully punching them into the connector, and trimming the ends. This is a process prone to human error.
- The available stock of suitable cables tend to be rather thick
- Thick cables make it a little more annoying to manipulate the meter probe, especially when the meter probe is on the lighter side
- Thick cables cannot easily be strain-reliefed by simply kinking them inside the enclosure, and necessitate some sort of cable clamp of which a suitable option has not been found
- Despite many real-world examples of it being done, I2C is technically not considered to be a suitable protocol for off-board connections due to cable capacitance and noise susceptibility issues
- Mini-DIN connectors are technically not designed for hot-plug, and its not too difficult to fail to plug them in all the way if enough insertion force is not used

The proposed solution to this is to switch the meter probe interface to simply using USB, as it solves many of these issues:

- USB device cables are widely available as a surplus/replacement product intended for use in computer mice
- These "mouse cables" are very flexible, usually have a rubber strain relief as part of their construction, and also typically come with a board connector (often JST PH compatible) already attached
- USB is explicitly designed for hot-plug, and uses differential signalling for better noise immunity

The chosen approach for this change is to integrate the [FTDI FT260](https://ftdichip.com/products/ft260q/) USB bridge IC, which provides a HID-compatible USB 2.0 FS interface on one side, and provides I2C and several supporting signals on the other side.

This IC does have a few drawbacks that will need to be managed, but it is hopefully worth it for the benefits.  These basically revolve around the 1ms SOF interval of USB, which limits our interrupt response time and transaction rate to much lower than we'd have with a direct I2C interface.  However, testing has shown that these can be sufficiently managed so as to not be a serious problem.

The integration plan involves using the "Bus Powered Configuration with +1.8V I/O Voltage" from the datasheet, to enable the use of a simpler LDO, and a configuration EEPROM that is large enough to serve as both the configuration memory and the sensor calibration memory.

dkonigsberg, 2024-02-27:
Changes implemented

Closed 2024-02-27.

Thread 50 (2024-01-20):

Convert base unit peripheral ports entirely to USB

dkonigsberg, 2024-01-20:
There are currently two peripheral ports on the front of the base unit.  One is USB 2.0 FS, and the other is buffered I2C with some support signals over a 6-pin Mini-DIN connector.  As of right now, the Mini-DIN port is dedicated to the meter probe and the USB port is for installing firmware updates and connecting miscellaneous peripherals.

With the implementation of #49, the Mini-DIN port will no longer be necessary.  Furthermore, it will often become desirable to connect more than one USB device to the unit at the same time.  This is so the meter probe does not need to be unplugged if someone wants to insert a memory stick, connect a densitometer, or attach a small keyboard.

The obvious solution to this situation is to simply use a hub, either internally (via an integrated USB hub IC) or externally (as provided by the user). Of course this presents a number of problems with the current design:

- The [ST USB Host Library](https://github.com/STMicroelectronics/stm32_mw_usb_host), which is what our current USB interface is based on, does not support hubs (and is under a somewhat icky license)
- The common open-source [TinyUSB](https://github.com/hathach/tinyusb) library has minimal host support, and does not support USB host on the STM32
- The open-source [CherryUSB](https://github.com/cherry-embedded/CherryUSB) library has far more developed host-side support, actually does support both hubs and STM32, but does not support the (non-DMA) "FS" peripheral in the [STM32F411RE](https://www.st.com/en/microcontrollers-microprocessors/stm32f411re.html) we're currently using

Putting all of that together, here's the proposed path forward:

- Remove the specialized Mini-DIN port from the device (this will eliminate a number of unique components).
- Switch the MCU over to the [STM32F446RE](https://www.st.com/en/microcontrollers-microprocessors/stm32f446re.html), using its (DMA capable) "HS" USB peripheral in FS mode. (this will be a complicated change, but we'll stick with the same package and as few differences as possible)
- Integrate the CherryUSB stack in place of the ST stack for running the USB host interface
  - This will require major bootloader changes, which are hopefully manageable
  - This will require rewriting all of our custom USB<->Serial drivers
  - This has the benefit that any code changes/additions we have to do will be under a much more comfortable license situation, which for some could be enough motivation all on its own.
- Implement the [Microchip USB2422](https://www.microchip.com/en-us/product/USB2422) hub controller, to provide two downstream ports on the device and offer a point of intermediary port control. Can also use a 2-port power controller as part of the implementation, and an MCU-supplied clock signal, to simplify things.
- Switch the external USB ports to using the reverse-mount [Amphenol 74626-11S0BPLF](https://www.amphenol-cs.com/usb-7462611s0bplf.html) connector, so they no longer feel upside-down to the end user due to internal PCB orientation.

_Note: The footswitch port uses a 3.5mm jack, and will remain unchanged by all of this. While USB-attached footswitches do exist, the ones that use a simple 2-wire connection tend to be of much higher quality at an acceptable price range._

dkonigsberg, 2024-02-27:
Changes implemented

Closed 2024-02-27.

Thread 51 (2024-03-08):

Fix USB cable connector routing on the meter probe board

dkonigsberg, 2024-03-08:
The D+ and D- pins on the (Rev E) meter probe's cable connector are backwards with respect to the FT260 IC's input.  This can be worked around by swapping conductors on the attached cable, but that's not a desirable workaround.  Better to just fix the board so the cable will work out of the box.

Closed 2024-04-19.

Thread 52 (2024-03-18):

Fix power switch cable connector size and placement

dkonigsberg, 2024-03-18:
The power board (Rev C) currently uses a [Molex 768290002](https://www.molex.com/en-us/products/part-detail/768290002) Mega-Fit 5.7mm pitch connector, combined with a [Molex 451360201](https://www.molex.com/en-us/products/part-detail/451360201) cable assembly (cut in half, with QC connectors crimped on) as a way of attaching the power switch.

In the current revision of the board, this arrangement has the following problems:

- With the plug and wire hardness connected, the whole thing is rather tall
- This height slightly invades the area where the main board overlaps inside the enclosure, causing fit issues
- The wires on the cable assembly are quite stiff, and also too thick (12AWG) to actually fit the current choice of QC connectors (which only hold up to 14AWG).

This absolutely needs to be fixed, sooner rather than later,  The current proposed approach towards fixing the issue is as follows:

- Draw a reference line on the power PCB layout that's offset >25mm from the interior edge of the board, marking the location where the main board will overlap it inside the enclosure
- Adjust the position of the power switch connector so that it does not cross this line
- Review available connector choices to see if there's anything smaller and/or shorter, which offers better fitting and more flexible wires.  (stiff wires can cause undesired side force on the QC connectors)

The main challenge with smaller and/or more reasonable connectors is simply that the pins are closer together than we'd like for trace clearance.  As such, extra layout/routing care may be necessary.

dkonigsberg, 2024-04-08:
One simple solution would be to not use the noted cable assembly, which uses 12AWG wires, and instead simply buy the components to make a 16AWG assembly:

- Pre-crimped lead: [797582037](https://www.molex.com/en-us/products/part-detail/797582037)
- Crimp socket (plug): [1700010102](https://www.molex.com/en-us/products/part-detail/1700010102)

A bit challenge with selecting any options is wanting sufficient clearance between the pins, and being able to find pre-crimped leads that match the system.

dkonigsberg, 2024-04-15:
The other solution, now likely for the next revision, is to change to a smaller connector.  The Molex Mega-Fit stack puts the top of the plug 28.8mm above the PCB, plus whatever space the cable bend takes.

The alternative now being considered is the Molex Mini-Fit Jr series. With this connector, the stack puts the top of the plug only 23.5mm above the PCB (plus cable bend).  While only a ~5mm difference, when combined with the ease of repositioning a smaller connector, this should be more than enough.  The only downside is that the lowest common rating of the Mini-Fit components is only 9A per contact. However, we're fusing at 5-6A, so that should be fine.  Will still stick to 16 AWG wires, for better flexibility.

Closed 2024-04-19.

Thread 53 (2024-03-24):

Oversize power board enclosure mounting holes

dkonigsberg, 2024-03-24:
The internal mounting holes on the power board currently use a standard KiCad footprint for M3 mounting holes.

To account for tolerance issues between the mounting of the rear panel connectors and the manufacture of the enclosure, these holes should be changed to be a little oversized. That way the board is more tolerant of things not lining up perfectly.

Since the only critical position of this board is those rear panel connectors, and since they have their own mounting points, this is unlikely to have any real downsides.

Closed 2024-04-19.

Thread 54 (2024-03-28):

Switch to an encoder with longer protruding threads

dkonigsberg, 2024-03-28:
The encoder on the main board PCB does not protrude very far above the surface of the enclosure, which means that the nut securing it doesn't have many threads to grab onto.  There's about 10mm from the PCB to the enclosure surface to work with.

The current encoder, the PEC11L-4120F-S0020, only extends 11.5mm from the PCB to the top of the threaded section.

According to current research, the best alternatives are either the PEC11H-4120F-S0020 or the ACZ11BR2E-20FD1-20C.  Either of these extend 13.5mm from the PCB to the top of the threaded section, which should work much better.

Closed 2024-04-19.

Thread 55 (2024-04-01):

Fix startup process so the blackout switch takes effect before any illumination is initialized

dkonigsberg, 2024-04-01:
This is a seemingly simple issue, but there's enough cross-dependency between all of the relevant components to make it not so simple.

Basically, we need to know the initial state of the blackout switch as early in the startup process as possible, and then feed that state into the code that initializes all of the illumination features of the device.

However, this needs to be done independently from the normal blackout callback handling in the illumination controller, because that operation has a number of side-effects that may depend on components that haven't yet been initialized.

Another idea is to simply make everything initialize in an "off" state, then fully initialize the keypad and blackout handling code, then enable light-emitting features.

Regardless, the main challenge could be the fact that we'd like to show the startup splashscreen earlier rather than later in the startup process flow.

Closed 2025-03-11.

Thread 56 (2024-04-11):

Power board needs filtering between the relays and the AC/DC converter

dkonigsberg, 2024-04-11:
The power board contains a pair of relay-switched outlets for controlling enlargers and safelights.  Sometimes, switching these AC loads can causes transients which manage to make their way across to the DC side and can then cause intermittent issues.

The easiest way to reproduce this issue is to use a 10W halogen desk lamp as a "test" enlarger load.  It is powered by a wall wart which contains a transformer that converts 120VAC to 12VAC.  Turning the power to the wall wart on can cause a minor spike, while turning the power off causes a noticeably larger spike.  When this event happens, there's a good chance that connected USB peripherals (such as the meter probe) will stop responding.  (It is unclear if this is due to those devices reacting to the spike, or some other components on the USB interface.)

Here's an example of what this looks like, when measured with an oscilloscope connected to the 12VDC output of the power board and set to AC coupling:
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

This problem can be temporarily eliminated by simply placing an EMC line filter between the enlarger relay outlet and the wall wart.  That is good enough for development, but not a viable long term solution.

The current thoughts about how to fix this for real involve placing some sort of filter at the input to the AC/DC converter brick.  This filter would likely go in place of the internal fuse holder and MOV, which are redundant components that already exist inside the AC/DC brick itself.  (There is still an external fuse, which should handle most other concerns.)

The filter will likely consist of a common mode choke, possibly combined with X and Y capacitors in the usual arrangement. There will be a preference towards using such components with all the relevant safety ratings and sufficiently encapsulated to avoid exposed metal contacts on the top of the PCB.

dkonigsberg, 2024-05-09:
Another likely source of EMI issues is power line noise from nearby brushed AC motors, which some old enlargers use to control the up/down movement of the head.  A good analog for these are old sewing machine motors, which have similar specifications.  Such motors produce far larger transients on start/stop than the above-noted transformer spike, and can cause these same sorts of problems.

Completely solving the issue for all possible sources of noise will likely require a combination of solutions, from improvements to the main board's input filtering and grounding strategies, improvements to decoupling around specific components, software robustness to faults, and a lot of testing.

dkonigsberg, 2024-06-06:
Since this issue was first opened, a number of important things have happened. Notably, extensive testing has now been done with an EFT burst generator, some filter schemes have been tried on and around the power board, and Recom has released an important datasheet update for the AC/DC converter.

The datasheet update contained this specific section of interest:
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

Upon talking with Recom, and reviewing some preliminary specs for the mentioned CMC, I've decided to take the following path forward on this task:

- Select a 47mH CMC with a >=0.5A current rating (45mH with the provided specs doesn't usefully exist as an off the shelf product)
- Put a 0.22uF X capacitor across the input to this CMC (Recom says "long cable" means >1m).
- Consider keeping the bleed resistor currently in the interim design
- Not going to bother with Y capacitors for now
- Review the DC output path, but changes here on the power board may not be useful (TVS diode can probably be removed, as I doubt it performs a useful function here.)

There likely will be changes made to the power input path on the main board, but those aren't covered by this task.

dkonigsberg, 2024-06-13:
Issue resolved to the extent it likely will be.

Closed 2024-06-13.

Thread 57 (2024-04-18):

Move TVS diode D15 further away from the encoder

dkonigsberg, 2024-04-18:
The TVS diode associated with the encoder contacts is currently placed right under the device. This puts it a bit too close to the pins and mounting location, and could lead to assembly issues or mishaps.

This part should be moved a bit further away, as there is ample space in that part of the board.

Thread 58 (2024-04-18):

Increase clearance between traces and display mounting nuts

dkonigsberg, 2024-04-18:
In a few spots, signal traces get rather close to where the display mounting hex nuts are placed.  Some effort should be made to increase the clearance around these spots, to reduce the likelihood of an assembly mishap scratching an important trace.

This can be done by either increasing trace clearance directly, or moving affected traces to the other side of the board.

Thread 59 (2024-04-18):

Add assembly registration holes to the main board and power board

dkonigsberg, 2024-04-18:
The main board and power board may be easiest to assemble as standalone boards, rather than as part of a panel.

If they are handled that way, then it makes sense to add the panel edge rail registration holes to the PCB itself.  Doing this involves adding 3-4 2.05mm holes in a similar arrangement as the fiducial marks.

A little more double-checking needs to happen before this is actually implemented, though, as it may make sense to do the power board as a 2-board panel, even if the main board isn't panelized.

dkonigsberg, 2024-06-07:
This issue might end up being closed without implementation, as it may be easier to simply have edge rails on all the boards.
This idea was floated in casual conversation with an assembly house, but there hasn't been much useful follow-up looking into whether or not it should really be done.

dkonigsberg, 2024-12-03:
Going to not do this, in favor of keeping such things on rails, even if its a one-board panel.

Closed 2024-12-03.

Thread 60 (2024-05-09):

Add additional bypass capacitors to resolve EMI issues

dkonigsberg, 2024-05-09:
The USB2422 IC is especially susceptible to conducted EMI.  The evaluation board datasheet suggests optionally adding 1nF capacitors in a variety of places to help with this.  Lab tests have shown that adding these definitely helps with the problem.  Additionally, adding a 1nF capacitor to the MCU's VDDA pin (which drives the internal PLL, and hence the clock line that runs to the USB2422), also seems to help.

Thus, this task is to add 1nF bypass capacitors (in addition to the ones already there) to the following places:

- USB2422 PLLFILT and CRFILT pins (qty 2)
- USB2422 power pins (qty 3)
- STM32F446RE VDDA pin (next to C12)

This is related to #56

dkonigsberg, 2024-06-06:
Given that the ability of MLCCs to filter high frequency noise has more to do with the package size, than the capacitance value, and given that we'd rather not put 0402 capacitors on the main board, this issue may not be worth implementing.  Chances are that any promising preliminary results from kludging these onto an existing board were not actually conclusive, and other things had a larger impact.

dkonigsberg, 2024-06-13:
This is hopefully taken care of, well enough, by some changes to power input filtering and minor bypass capacitor changes around the USB hardware.
Considering the details of how the EMI issues have been manifesting, if they still exist on Rev E hardware then its probably easier to just make sure the software is robust enough to recover from them.

Closed 2024-06-13.

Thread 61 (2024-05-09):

Update USB connector footprint to improve manufacturability

dkonigsberg, 2024-05-09:
The USB connector footprint is mostly surface mount, except for two thru-hole mechanical pins for the shield.  While these pins do need to be soldered after reflow, the connector is extremely fragile until this is done.

One suggestion is to add some paste layer spots around the annular ring of these mechanical pins, so that they will get at least partially soldered during the reflow process. This should hold them in place until additional soldering can happen, or potentially even make additional soldering unnecessary.

Below is an example of such a footprint:
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

dkonigsberg, 2024-05-24:
This is an example of the first approach being tried:
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

dkonigsberg, 2024-06-13:
Implemented in the Rev E hardware, as shown above.
Will re-open, or open a new task, if this approach needs further tweaking.

Closed 2024-06-13.

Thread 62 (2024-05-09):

Revisit main board grounding strategy

dkonigsberg, 2024-05-09:
The main board's grounding strategy is currently somewhat naive, as it uses DC ground for everything (including TVS diodes) and then directly bonds the DC circuit ground plane to the chassis through the mounting holes.

There is a lot of confusing and conflicting advice out there as to how to correctly handle this.  It is often suggested to connect TVS diodes to the chassis ground.  Then some suggest connecting DC ground to the chassis in one place near I/O ports.  Some suggest doing this, but then connecting the rest of the mounting holes through high voltage capacitors.  Furthermore, some suggest that when the chassis is actually connected to mains earth, then don't connect DC ground to the chassis except maybe at the power supply, and maybe connect all the mounting holes through capacitors.  Like always, the real answer is some form of "it depends" where the specific scenario in question is never directly covered.

As some of the improvements in power filtering that will result from #56 are likely to couple some amount of noise to mains earth, dealing with this correctly is going to become a little more important.

So for the next revision, the current proposal is to do the following:

- If main board power input filtering is added, GND needs to go through that filter **before** its connected to the internal ground plane.
- All TVS diodes around the main board should now connect to chassis ground.
- All mounting holes should now connect to chassis ground.
- Some sort of traces/fills of chassis ground may need to be added, to help connect mounting holes and provide access to anything that needs to connect to them.
- Add high voltage capacitors between the mounting holes and DC ground, to avoid a difference in AC potential
- Any time a chassis-grounded shield needs to also connect to DC ground, do it through a filter similar to what is on the USB connector shields.  This may be a concern for the footswitch jack.  (It also may be a concern for the XLR connector on the power board.)

And finally, all of this can be changed or thrown out if more useful advice is actually provided.

dkonigsberg, 2024-05-13:
It should be noted that there's a good chance that the current approach is perfectly fine.  Its just that there is so much conflicting guidance out there that it always creates doubt, so this ticket was created simply to track that doubt.

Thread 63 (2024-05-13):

Change main board panel illumination LEDs again

dkonigsberg, 2024-05-13:
The main board has an array of panel illumination LEDs, to make it easier to see the button locations in a darkroom environment. These LEDs shine through small holes placed adjacent to the panel buttons.

The early prototypes used the Lite-On LTL-4225, which are somewhat standard T-1 3/4 LEDs.  They worked, but were slightly too tall to comfortably fit in the space between the top of the PCB and the interior surface of the enclosure. Whether or not they fit, is way too dependent on manufacturing/assembly tolerances.

The more recent prototypes switched to using the SunLED XLUR11D. These are smaller T-1 LEDs, which require spacers to achieve the desired height for being close to the interior surface of the enclosure.  While this option works, adding the spacer involves an extra component and an extra manual assembly step for each LED.  It would be best to avoid this, if possible.

The current proposal is to switch to the Lite-On LTL-10223W.  This LED is closer in size to the original choice, a little bit shorter and without a flanged base. Making sure its aligned correctly during soldering may depend a bit more heavily on a positioning jig, but should still be possible.  Its specs are also similar to the original choice, but with a wider viewing angle.  Its possible there will be a bit more spill from its light, so that should be tested to see if that is even a concern.

Closed 2024-05-24.

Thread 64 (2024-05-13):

USB host implementation needs to be robust against hub IC failures

dkonigsberg, 2024-05-13:
The most common failure mode of the issues noted in #56 and #60 is that the USB2422 hub IC stops responding on the upstream USB interface. Probing has shown that the USB lines go completely dead when this glitch happens.  The current theory is that this is a result of noise on the clock or signal lines breaking the state machine of the hub.

Regardless, toggling the "VBUS detect" pin on the USB2422 seems to cause it to reset its state and start working again.  Actually doing this is the easy part.  Detecting the issue in firmware, and cleanly handling all the state and race issues around the toggle is a bit more work.

So what needs to happen, is that the firmware needs to be able to detect when this state happens.  This could be via a timeout on some periodic hub transaction, or more likely a timeout on something the USB host interface always does when idle (such as an SOF interrupt).  Then, when the issue is detected, a robust reset cycle should be implemented.  Since its likely that multiple glitch events happen in a row, a glitch during reset shouldn't be allowed to break anything.

Ultimately the hope is that hardware fixes will make the occurrence of this glitch rather rare. But as it cannot be eliminated completely, it should still be handled gracefully.

Testing of this code is best performed on the initial "Rev D" hardware configuration, since that is especially vulnerable to the issue. Future updates to the power board and main board may make it harder to deliberately reproduce.

dkonigsberg, 2024-05-21:
The first step of resolving this is handled by the following two commits:
598103fcea51e4cb04459859221a0171e1b0a4ae
1fa5e16ee356f8af803434ec6a69954996ea0347

They solve the issue of the USB layer becoming non-responsive due to the USB2422 freezing up and refusing to respond to USB commands.  Further work may be needed to deal with this issue in downstream hubs, particularly handling of various USB device reset (and maybe overcurrent) events that are not currently handled by CherryUSB.

dkonigsberg, 2024-12-04:
Testing under the latest hardware (Main board F, Power Board E, Meter Probe F) and firmware as of today (2024-12-04) shows pretty good behavior.  The 1kV EFT pulses do cause the USB device to reset, but it seems to recover every time.  Furthermore, bursts don't seem to cause any extra problems.  These tests included bursts during a long exposure countdown.

However, in the interest of extra robustness, there are a few cases which should be explicitly tested and handled (even if they need to be artificially induced for development):

- Internal hub does not recover on a VBUS toggle, and needs a full reset
- Errors during descriptor and setup requests when the FT260 is reconnecting
- General review of places where things could get stuck

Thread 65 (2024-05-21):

Rework power supply scheme for the meter probe

dkonigsberg, 2024-05-21:
Extensive testing has shown that the root cause of all the issues which have led to #56, #60, and #64 may actually be related to the meter probe itself.  This realization was arrived at because these particular USB glitches only seem to occur when testing with the meter probe.  They do not seem to occur with any other USB peripherals, including the evaluation board for the controller IC (FT260) used in the meter probe.

First, some basic issues were noticed, which should be addressed:

- The bulk capacitor on `VBUS` should be increased in size. (FT260 eval board uses a 4.7uF tantalum, whereas the meter probe currently uses a 4.7uF MLCC.  It would be a better idea to simply use a 10uF MLCC here.)
- The `RESETN` pin has a smaller resistor and a capacitor on it in the recommended schematic, whereas it only has a 10k resistor on the current meter probe.  For stability, the components on the meter probe here should be changed to match the recommended schematic.

Bodging around these two issues in bench testing did improve resistance to one of the easier power transient tests (lamp transformer on unfiltered AC supply), but did not help against the more difficult tests (AC motor or EFT generator). Regardless, implementing these changes is a good idea.

Then, upon further inspection, the likely root issue was noted.  The meter probe runs the FT260 I/O voltage at 1.8V, based on the example on page 34 of the FT260 datasheet. This was done because the TSL2585 sensor needs 1.8V, and results in everything on the surrounding board running at 1.8V.  This includes the sensor, EEPROM, push button pull-up, and various FT260 pin pull-ups.  This also likely means that the margins on the power rails and many of the pins are now rather small, and could be a lot more sensitive to glitches.

So the plan is to switch to a new power supply configuration, which is a much closer match to how the breadboarded version of the meter probe works:

- Incorporate all the changes noted above
- Switch the FT260 I/O voltage to 3.3V, using its internal regulator, as shown on page 31 of the FT260 datasheet
- Use the FT260 `VOUT3V3` pin to provide a 3.3V rail for the EEPROM and the push button
- Keep the 1.8V regulator mostly separate, directly tapping the filtered `VBUS` 5V rail and providing 1.8V to just the TSL2585 section
- Leverage the fact that the TSL2585 has 3.3V tolerant I/O pins to avoid the need for any additional level shifting

This is essentially how the breadboarded version of the meter probe is configured, using the FT260 evaluation board and a dedicated breakout board for the TSL2585. Testing has shown that the breadboarded version is mostly immune to the power glitch. (it only fails on a repeated burst from the EFT generator, not normal pulses, which is more of a lab test than a real world transient, and one that can likely be handled in software.)

dkonigsberg, 2024-06-07:
A new version of the meter probe with this change has been constructed, and is performing far better in initial tests.  This issue may be closed shortly, pending a little bit more testing.

dkonigsberg, 2024-06-13:
Updated (Rev F) meter probe with these changes is performing much more reliably.
There really isn't that much more that can be tweaked here, so closing this issue for now.

Closed 2024-06-13.

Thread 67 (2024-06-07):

Rework main board power input and voltage regulation

dkonigsberg, 2024-06-07:
The main board receives +12VDC from the power board, from which it then needs to provide both 3.3V and 5V rails for various purposes.  The on-board components typically run off 3.3V, while the front ports (including USB) require 5V to operate.

The current design brings power into a pair of RT8258 buck regulator circuits, from which both rails are generated.

The proposed change is to do the following:

- Redesign the power input path using some suggestions from [Infineon AN80994](https://www.infineon.com/dgdl/Infineon-AN80994_Design_Considerations_for_Electrical_Fast_Transient_(EFT)_Immunity-ApplicationNotes-v09_00-EN.pdf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), such that both the +12VDC and GND inputs pass through various components before going to the buck regulators or ground plane, to improve power quality and hopefully reduce the impact of transients.
- Replace the current buck regulator setup with one based around the [TI TPS54294](https://www.ti.com/product/TPS54294) dual converter, which has performed quite well in testing and should make it easier to use a single input filter path
- Clean up the output path, removing unnecessary components (the ferrite beads currently there are likely unnecessary, for example)

The motivation behind these changes is similar to the motivation behind #56, #60, and #65, which is to generally improve the power subsystem in the device.  Actual cost is unlikely to change much, and there may be a slight reduction in component count.

dkonigsberg, 2024-06-13:
Changes implemented on the Rev E hardware.

Closed 2024-06-13.

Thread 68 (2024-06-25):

Tweak footprints for CMC (FL1) and bleeder resistor (R1) for easier installation

dkonigsberg, 2024-06-25:
Both of these component footprints are based on stock KiCad footprints for similar components.  The holes in their pads are somewhat tight, making component installation difficult.

This task is to slightly increase the diameter of the pad holes for these parts, to make assembly easier.

This is only a minor mechanical change, and should have no functional impact.

Closed 2024-09-02.

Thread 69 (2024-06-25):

Increase size of mechanical pin holes for the rotary encoder

dkonigsberg, 2024-06-25:
The mechanical pin holes for the rotary encoder on the main board are extremely tight, and make component installation quite difficult.  The size of these should be adjusted for ease of assembly.

This is a purely mechanical change, and should have no functional impact.

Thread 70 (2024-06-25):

BOM consolidation of low value resistors

dkonigsberg, 2024-06-25:
On the main board, there are both 220 ohm and 330 ohm resistors.  Considering how close these values are, and what they're being used for, there is no need for both values.  Combine these to reduce BOM line item count.

dkonigsberg, 2024-09-01:
Redundant resistors removed as part of a different change.

Closed 2024-09-01.

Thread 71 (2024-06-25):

Make sure all 1% resistors are marked as such on the schematic

dkonigsberg, 2024-06-25:
During assembly, it was discovered that R11 was not marked as 1% in its schematic label.  This should be fixed, and the rest of the schematic should be reviewed to make sure no other similar omissions exist.

If a part isn't explicitly marked as 1%, then its tolerance should not matter.

Closed 2024-07-23.

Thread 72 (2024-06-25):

Fix startup issues with new buck converter on the main board

dkonigsberg, 2024-06-25:
The Rev E hardware switched over to the TI TPS54294 buck converter, which is a dual-output component that can supply both the 3.3V and 5V rails.
In testing, it was found that the power board sometimes cannot supply the inrush current needed to start both sides of the converter at once. When this happens, the power rails either fail to come up or initialize unreliably.

Extensive lab testing has reproduced this issue with a test board and bench instruments providing the supply and load.

To solve this problem, three changes are being proposed:

1. Sequence the power rails, so that 3.3V comes up before 5V.
2. Slightly delay the startup of the power rails, so that the AC/DC converter's 12V supply has a little time to stabilize and charge its capacitors
3. [Optional] Add feedforward capacitors to the buck converter's feedback circuit to help stabilize its response

The first change alone may be sufficient to solve the problem, but doing all three should lead to a generally better and more reliable system.

The current plan is to bodge these change into the Rev E hardware to get development and testing back on track, then to incorporate them directly into the Rev F update.

Closed 2024-07-23.

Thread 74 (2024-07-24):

Review and clean up main board power input

dkonigsberg, 2024-07-24:
As a result of #67, several changes were made to the power input path on the main board.  This includes adding ferrite beads and a TVS diode, as well as some routing adjustments.

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

The goal of these changes was to reduce the effect of EFT bursts downstream in the system.

In practice, these changes appear to have accomplished little, and might even be counterproductive on their own.

Going forward, this area of the board should be reviewed and updated, pending additional lab testing.  The TVS diode is still a good idea, though perhaps a different one.  The EMI filter section is still absolutely needed.  However the ferrite beads should probably be removed, and adjustments to the capacitors may still make sense.

Closed 2024-09-01.

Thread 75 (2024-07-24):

Review and clean up USB port power connections

dkonigsberg, 2024-07-24:
The front USB ports contain several components between their power/ground pins and the rest of the system.  These were rearranged and added to in the latest Rev E hardware, and now have the following configuration:

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

Every example or evaluation board schematic for USB ports seems to do this differently.  Some put ferrite beads on power and ground, some only put ferrite beads on power, there are various configurations of capacitors, and some even stick a common mode choke upstream on the data lines.

Regardless, what's done here is probably not the best solution.  This whole layout needs to be reviewed and updated, possibly pending some lab testing on prototype hardware.  The most likely solution will involve reverting to the Rev D layout, removing the ferrite bead on ground, and making some adjustments to the ferrite bead configuration on power.

Closed 2024-09-01.

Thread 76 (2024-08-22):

Improve display module connection and mounting

dkonigsberg, 2024-08-22:
The current approach for mounting the OLED display module is somewhat fiddly and labor intensive.  It involves soldering a short pin header to the display module itself (the normal ones are too long), then assembling it to the main board using a screw+spacer+washer+locknut stack in all four corners, then soldering the other side of the connector.

This can be made easier, using some slightly more expensive connector and mounting hardware.

The proposal is as such:

- Use the stock version of the display module that ships with normal-length pin headers
- Add the Harwin M20-7810845R connector (or similar) to the main PCB.  This is a special reverse-mount surface-mount connector that is soldered on the component side, with the display module's pins sticking through and securing into it.  As a result, no manual soldering will be necessary to mount the display.
- Place Wurth 9775046360R standoffs in each of the four corners of the display.  This is a reverse-mount SMD solderable threaded standoff, which should protrude ~3mm above the display side of the PCB.  With these, mechanically securing the display should only require four screws (and some Loctite), and little else.  Maybe lock washers, but those are optional.
- Increase the main PCB board width (and/or tweak the standoff footprints) just enough to make it all fit.  Don't move the enclosure mounting holes if possible.

dkonigsberg, 2024-08-28:
Decided to go with the Harwin reverse-mount pin connector, and Keystone 8879 standoffs.
By using these particular nylon standoffs, its easy to later change our minds if they don't workout, without having to change any board designs.

Closed 2024-08-28.

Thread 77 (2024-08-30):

Change LED driver to enable more panel illumination features

dkonigsberg, 2024-08-30:
The "panel illumination" LEDs are the set of LEDs that surround all of the buttons on the top of the device, and are used to make it easier to see where the buttons are when operating the device in a darkroom environment.

These LEDs are currently driven by a [STP16CPC26](https://www.st.com/en/power-management/stp16cpc26.html) driver IC.  This driver allows for on/off control of individual LEDs, but only allows for easy brightness control on a global level.  It is controlled via a PWM signal to set LED brightness, and control messages via SPI to turn LEDs on and off.

In cases where it would be a nice UI touch to call attention to particular buttons by making certain LEDs brighter or pulsate, more granular control would be helpful.

The proposal is to switch to the [AW9523B](https://www.awinic.com/en/productDetail/AW9523BTQR), which is controlled via I2C and supports per-channel brightness settings.  This driver also works by varying the current, rather than PWM.  It is also a much cheaper IC, though it cannot be sourced from the same distributors as most other components.

Making this switch will free up 3-4 I/O pins, an SPI peripheral, and a timer channel.  However, there isn't likely to be another use for those in the system.

Closed 2024-09-01.

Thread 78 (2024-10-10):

Fix orientation of ESD321 TVS diodes on all peripherals

dkonigsberg, 2024-10-10:
Nearly all TVS diodes I've ever used are documented such that pin 1 is the cathode and marked on the package.

Apparently the ESD321DYAR (but **not** the ESD321DPYR) is a special exception to this.  On the ESD321DYAR, pin 1 is still marked, but the cathode is actually on pin 2.

This is briefly mentioned in the [datasheet](https://www.ti.com/lit/ds/symlink/esd321.pdf), on page 3, in a way that's very easy to miss.

It also confused someone enough to result in a [TI forum thread](https://e2e.ti.com/support/interface-group/interface/f/interface-forum/1410599/esd321-pin1-position).

Fixing this on the EDA side likely involves some footprint changes, however as far as the actual PCB is concerned, it is little more than a positioning data and silkscreen update.

Note: This issue affects current working designs of the Meter Probe and the DensiStick, and must be addressed before the next revision of those are assembled.

Closed 2024-11-24.

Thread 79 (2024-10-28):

Investigate EOL digital potentiometer component

dkonigsberg, 2024-10-28:
Just received a part life notification from Digi-Key, indicating that the MCP4017T-104E/LT digital potentiometer is now end-of-life.
Need to investigate whether this part is really being discontinued, or if its just a vendor database rule being triggered by some change in supplier part numbering specifics.

This part is used to control the LED drive current on the DensiStick.

Ultimately, either a drop-in replacement needs to be found, or an alternative solution.  So this will be a BOM change or a circuit change.

In practice, the only drive current settings actually being used are "maximum current" (minimum resistance) and "minimum current" (maximum resistance).  A digital pot is the easiest, cheapest, and most flexible way to accomplish this, but not the only way.  So anything that makes it easy to switch between 2-3 resistance settings on the LED driver's RSET pin will work here.

dkonigsberg, 2024-10-28:
After a little digging, this seems to be just a manufacturing change.

While not linked in the Email, Digi-Key does have a document talking about it:
https://mm.digikey.com/Volume0/opasdata/d220001/medias/docus/6448/BLAS-06WDEF500.pdf

Which then links  to the following document on Microchip's website:
https://www.microchip.com/product-change-notifications/Data/BLAS-06WDEF500/PCN_BLAS-06WDEF500_Recommended%20Replacements.pdf

This gist of this is that we simply need to update our BOM such that:
`MCP4017T-104E/LT` becomes `MCP4017T-104E/LTY`

This replacement part is not yet listed with vendors, but is effectively the same thing with a different finish on the leads.

dkonigsberg, 2024-12-03:
There's a good chance that the existing part will be available in quantity for long enough that a production quantity can be purchased, and that the new part won't be available until after that point.  So this issue should be tracked, but a BOM change isn't a production hold-up.

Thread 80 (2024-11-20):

Change DensiStick LED driver wiring to reduce minimum drive current

dkonigsberg, 2024-11-20:
The current LED driver design in the DensiStick drives a pair of LEDs from a MIC4812, using a 100k I2C potentiometer (MCP4017-104E) as part of its current set resistor (RSET) chain.

More specifically, each LED is wired to two channels of the MIC4812, and RSET uses a 16.5k resistor with the 100k digital pot.
This gives a maximum current of 100mA per LED, with a minimum current of 14mA per LED.

This is fine for measurement, but still a little bit too bright for idling.

The proposed change is to wire each LED to only one channel of the MIC4812 (so only using 2 of 6 total channels), and changing the base current set resistor to 8.25k.  This will keep the 100mA maximum, but drop the minimum to about 7.6mA.

Closed 2024-11-24.

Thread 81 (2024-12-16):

Put serial number rectangle on opposite side of DensiStick board

dkonigsberg, 2024-12-16:
The white silkscreen filled rectangle, intended as a spot to write the device serial number, is on the component side of the DensiStick board.  This side is not visible once the board is installed into the lower half of its enclosure, and thus becomes obscured a little early in the assembly process.

It would make more sense to put this on the back-side (top-side as installed) part of the board, and/or both sides.

If this change gets made, it needs to be a silkscreen-only change, and done right before generating the final Gerber files for mass production.  No need for it to be part of any prototypes.

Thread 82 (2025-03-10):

Update configuration import/export code

dkonigsberg, 2025-03-10:
There's a feature where the device configuration can be imported/exported to/from a USB stick.  Its been a long time since this code was touched, and thus its out-of-date with respect to the current device functionality.

This code needs to be brought up-to-date with the current device featureset.

There are also additional import/export implementations related to the Meter Probe and DensiStick peripherals.  Those were primarily added to support development, and should probably be removed.  If updated, they don't need to be as user visible.  Meter Probe calibration is considered a "factory" task performed by external software, and DensiStick calibration is a user-interactive flow.

dkonigsberg, 2025-03-14:
"Factory" setup and calibration for the Meter Probe and DensiStick are currently being handled with a combination of [FT_Prog](https://ftdichip.com/utilities/#ft_prog) and an all-in-one internal application.  This internal application also runs the calibration rig being used to calibrate the meter probes.

While there are no end-user use cases where someone may want to alter the contents of the calibration memory on these peripherals from the Printalyzer Enlarging Timer itself, there may be use cases where someone wants to fiddle with it out-of-band.  This is especially true if anyone wants to build their own hardware from the schematics published in this repository.

To that end, as a follow-on task, this internal application should probably be split into two separate applications.  There should be a published "utility" that can handle everything necessary to take "fresh" hardware and configure it, and there should still be an internal application to run the internal calibration rig.  (obviously these two will share some interface code)

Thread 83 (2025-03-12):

Add watchdog support to the firmware

dkonigsberg, 2025-03-12:
This task is a bit of a "maybe" where it is debatable whether it should be implemented.

In the unlikely event that the device firmware becomes non-responsive, a watchdog timer could be used to make the device auto-reset.  However, a blind auto-reset isn't really safe for this device and some user interaction will always be required.

Thus, we have two possible options:

1. If the device freezes, the user will quickly notice and simply toggle the power switch
2. If the device freezes, a watchdog will reset it into a "safe" mode that informs the user of the freeze, after which user interaction will still be required to get back into a normal operating mode.

This sort of user-in-the-loop "safe" mode is necessary, because the user may have light sensitive materials out that they need to secure before continuing to fiddle with the device.  And even if they don't, a user is likely to perform some unwanted action on the device if they're not well aware of what happened.

Another downside of implementing a watchdog timer is that there will then be landmines all over the firmware where a reset could be triggered if we forget to kick the watchdog in some loop somewhere.

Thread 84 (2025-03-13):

Change XLR connector used for the DMX512 control port

dkonigsberg, 2025-03-13:
This is an optional change, pending further investigation.  It would likely require a new power board revision to implement.

The connector currently being used for the DMX512 output port is the Neutrik [NC5FBH](https://www.neutrik.com/en/product/nc5fbh) or [NC5FBH-B](https://www.neutrik.com/en/product/nc5fbh-b).  This is a 5-pin XLR connector for a metal shell.  This is also a very expensive connector, but with pricing varying wildly between different distributors and the two variants, almost changing every time one looks at pricing.  There is a similar plastic shell connector, the [NC5FAH](https://www.neutrik.com/en/product/nc5fah), which is sometimes a little bit cheaper.  However, due to the aforementioned pricing variety, the difference isn't always there.

During development and testing, a number of interesting things with DMX connectors and cables have been discovered:

- While the "standard" connector is 5-pin XLR, the vast majority of DMX devices use a 3-pin XLR connector.  Its extremely uncommon to find any piece of hardware that actually has a 5-pin connector on it.
- 3-pin XLR connectors are massively cheaper than 5-pin XLR connectors
- The metal shell of DMX cables is rarely connected to anything, and is often painted black and non-conductive.  Even when the shell is conductive, there is rarely any continuity from the shell on one end to the other.  This means that having metal contact in the shell area of a receptacle connector provides no real benefit.

Keeping this all in mind, it may make sense to just switch from the NC5FBH over to something in the [NC3FAH](https://www.neutrik.com/en/neutrik/products/xlr-connectors/xlr-chassis-connectors/a-series) series or the [NC3FAAH](https://www.neutrik.com/en/neutrik/products/xlr-connectors/xlr-chassis-connectors/aa-series) series.

This shouldn't require any changes to the metal chassis design or mounting screws.

dkonigsberg, 2025-08-31:
Right now Neutrik appears to have marked many connectors as "Phase Out" on their website, including may of the options listed above.  The NC5FBH-B is also marked "EOL" by Mouser, but the others aren't as of yet.  Some of these appear to have what might be replacement parts listed on the Neutrik website, but those parts aren't yet known to distributors.

The safest option for now is probably to switch to the NC5FAH as it still seems to have good stock, even if its status is a little ambiguous.  It is also a drop-in replacement.  If a new revision of the power board is required, the 3-pin variants might be worth considering, but otherwise its probably best to just stick with the 5-pin version.

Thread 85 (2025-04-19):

Switch light sensor in peripherals from the TSL2585 to the TSL2522

dkonigsberg, 2025-04-19:
Both the Meter Probe and the DensiStick use an ambient light sensor from AMS-OSRAM to perform their functions.  At the time those devices were originally designed, the best available choice was the [TSL2585](https://ams-osram.com/products/sensor-solutions/ambient-light-color-spectral-proximity-sensors/ams-tsl2585-light-sensor-with-uva-detection).  This sensor has two Photopic photodiodes, which measure the spectrum these devices are intended to measure, as well as two UV-A and two IR photodiodes which are not used.

Recently, AMS-OSRAM has released the new [TSL2522](https://ams-osram.com/products/sensor-solutions/ambient-light-color-spectral-proximity-sensors/ams-tsl2522-ambient-light-sensor-with-flicker-detection) sensor, which has four Photopic photodiodes.  In testing, the TSL2522 gets approximately double the signal for a given light level as the TSL2585, which is highly desirable to improve the low-light sensitivity of the Meter Probe.

Unfortunately the TSL2522 has a different pinout from the TSL2585, even if it is otherwise almost identical in design and interface.  So to implement this change, a new PCB revision will be required.

While there is little benefit to also making this change on the DensiStick, it should still be made there for the sake of component commonality across the project's PCBs.

Closed 2025-07-17.

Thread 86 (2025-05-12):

Piezo buzzer component is EOL

dkonigsberg, 2025-05-12:
The main board uses a [Murata PKM22EPPH4001-B0](https://www.murata.com/en-us/products/productdetail?partno=PKM22EPPH4001-B0) as its piezo buzzer for all the beeps and bloops of the timer.  Apparently Murata just decided to EOL their entire catalog of these components, though the "last time buy" date isn't until 3/31/2027.

Need to either decide to stick with this part, and simply order a long term supply, or select an alternative.  Even if this part is kept, alternatives should at least be researched.

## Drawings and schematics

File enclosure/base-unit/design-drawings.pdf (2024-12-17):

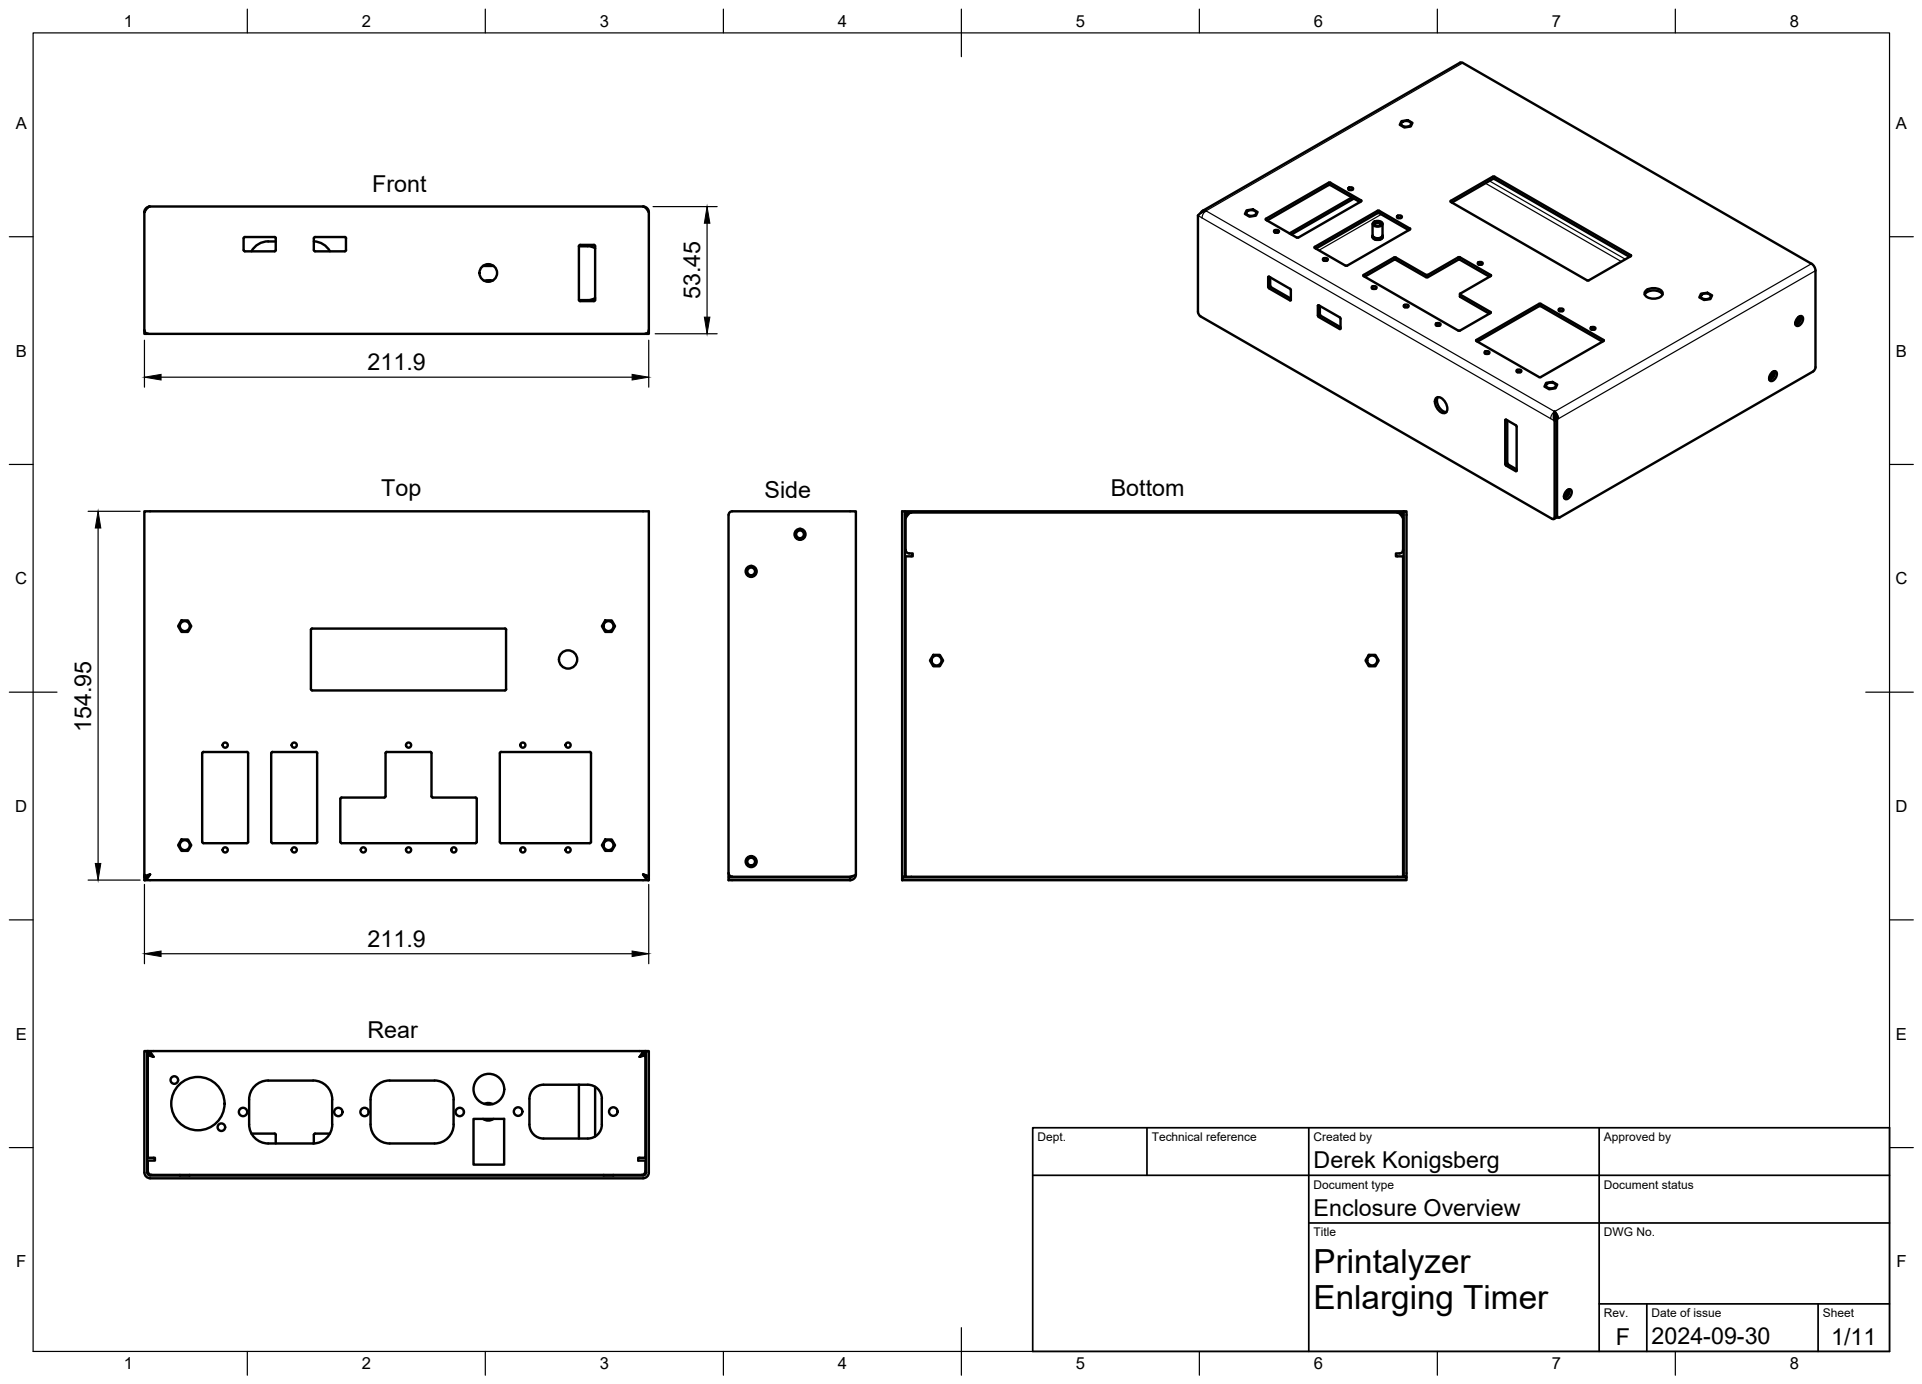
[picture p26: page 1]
Title; DWG No.; Rev.; Date of issue; Sheet; Enlarging Timer; Derek Konigsberg 53.45

Dept. | Technical reference | Created by | Approved by

Document type Enclosure Overview | Document status

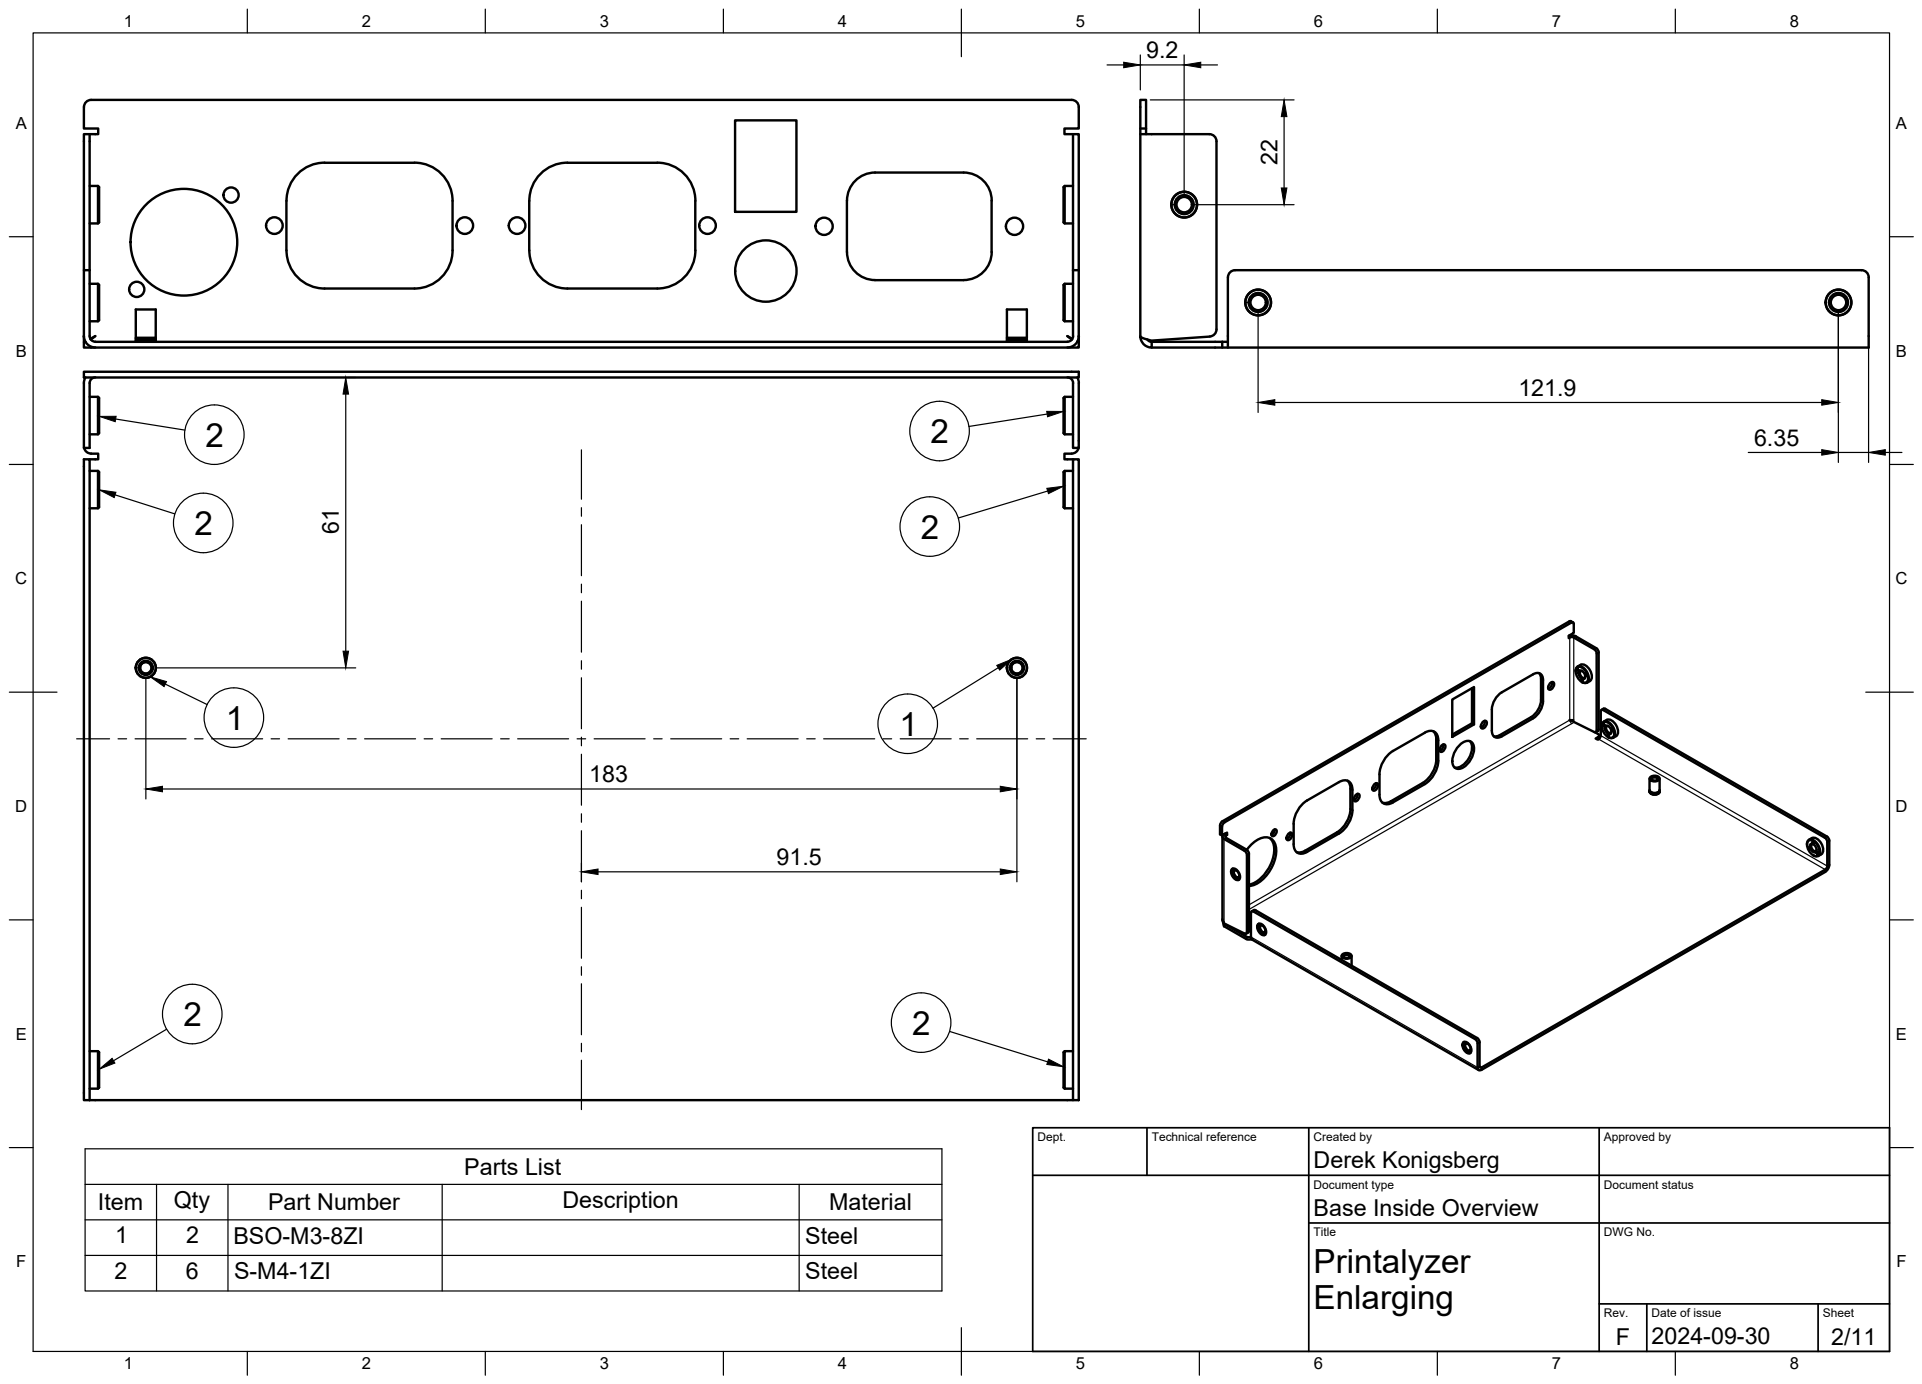
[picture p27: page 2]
Dept.; Technical reference; Created by; Approved by; Title; DWG No.; Parts List; Derek Konigsberg

Document type Base Inside Overview | Document status

Item | Qty | Part Number | Description | Material
1 | 2 | BSO-M3-8ZI | | Steel
2 | 6 | S-M4-1ZI | | Steel

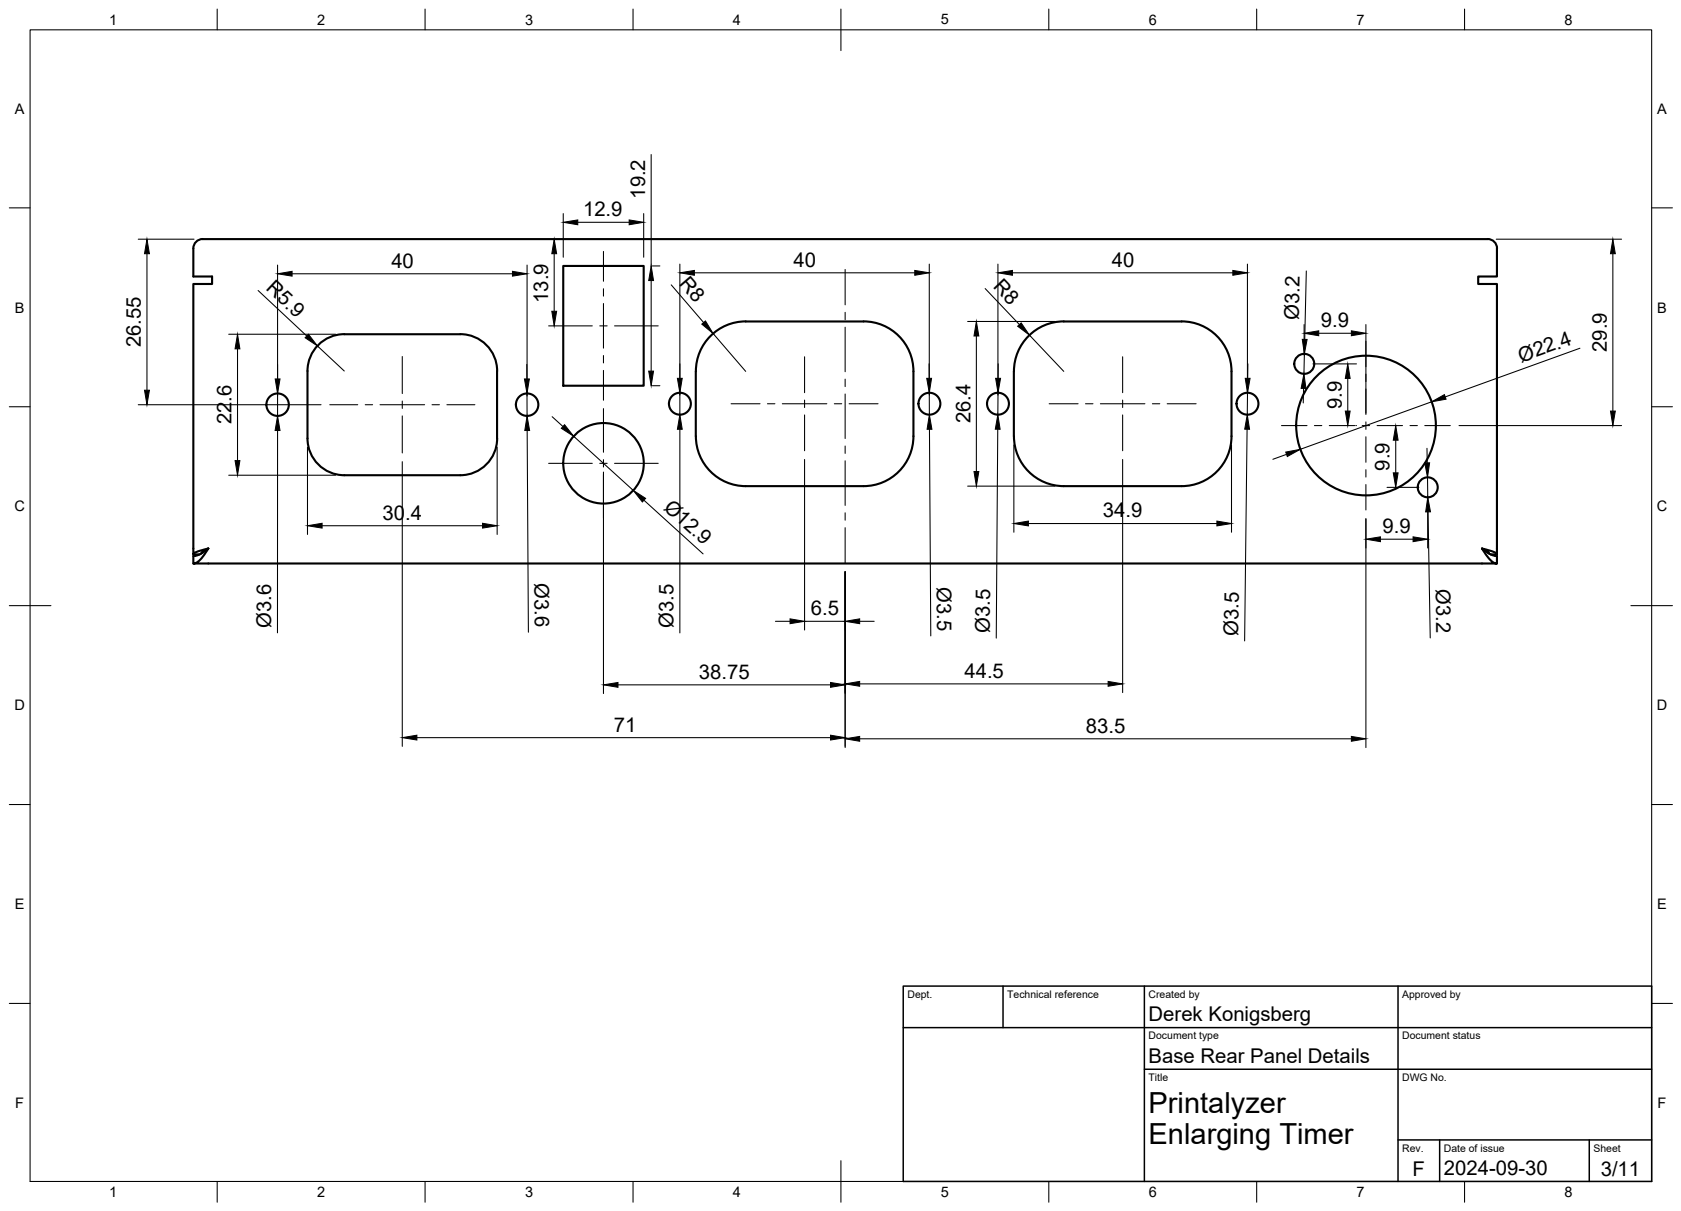
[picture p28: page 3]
Title; DWG No.; Derek Konigsberg Ø3.6

Dept. | Technical reference | Created by | Approved by

Document type Base Rear Panel Details | Document status

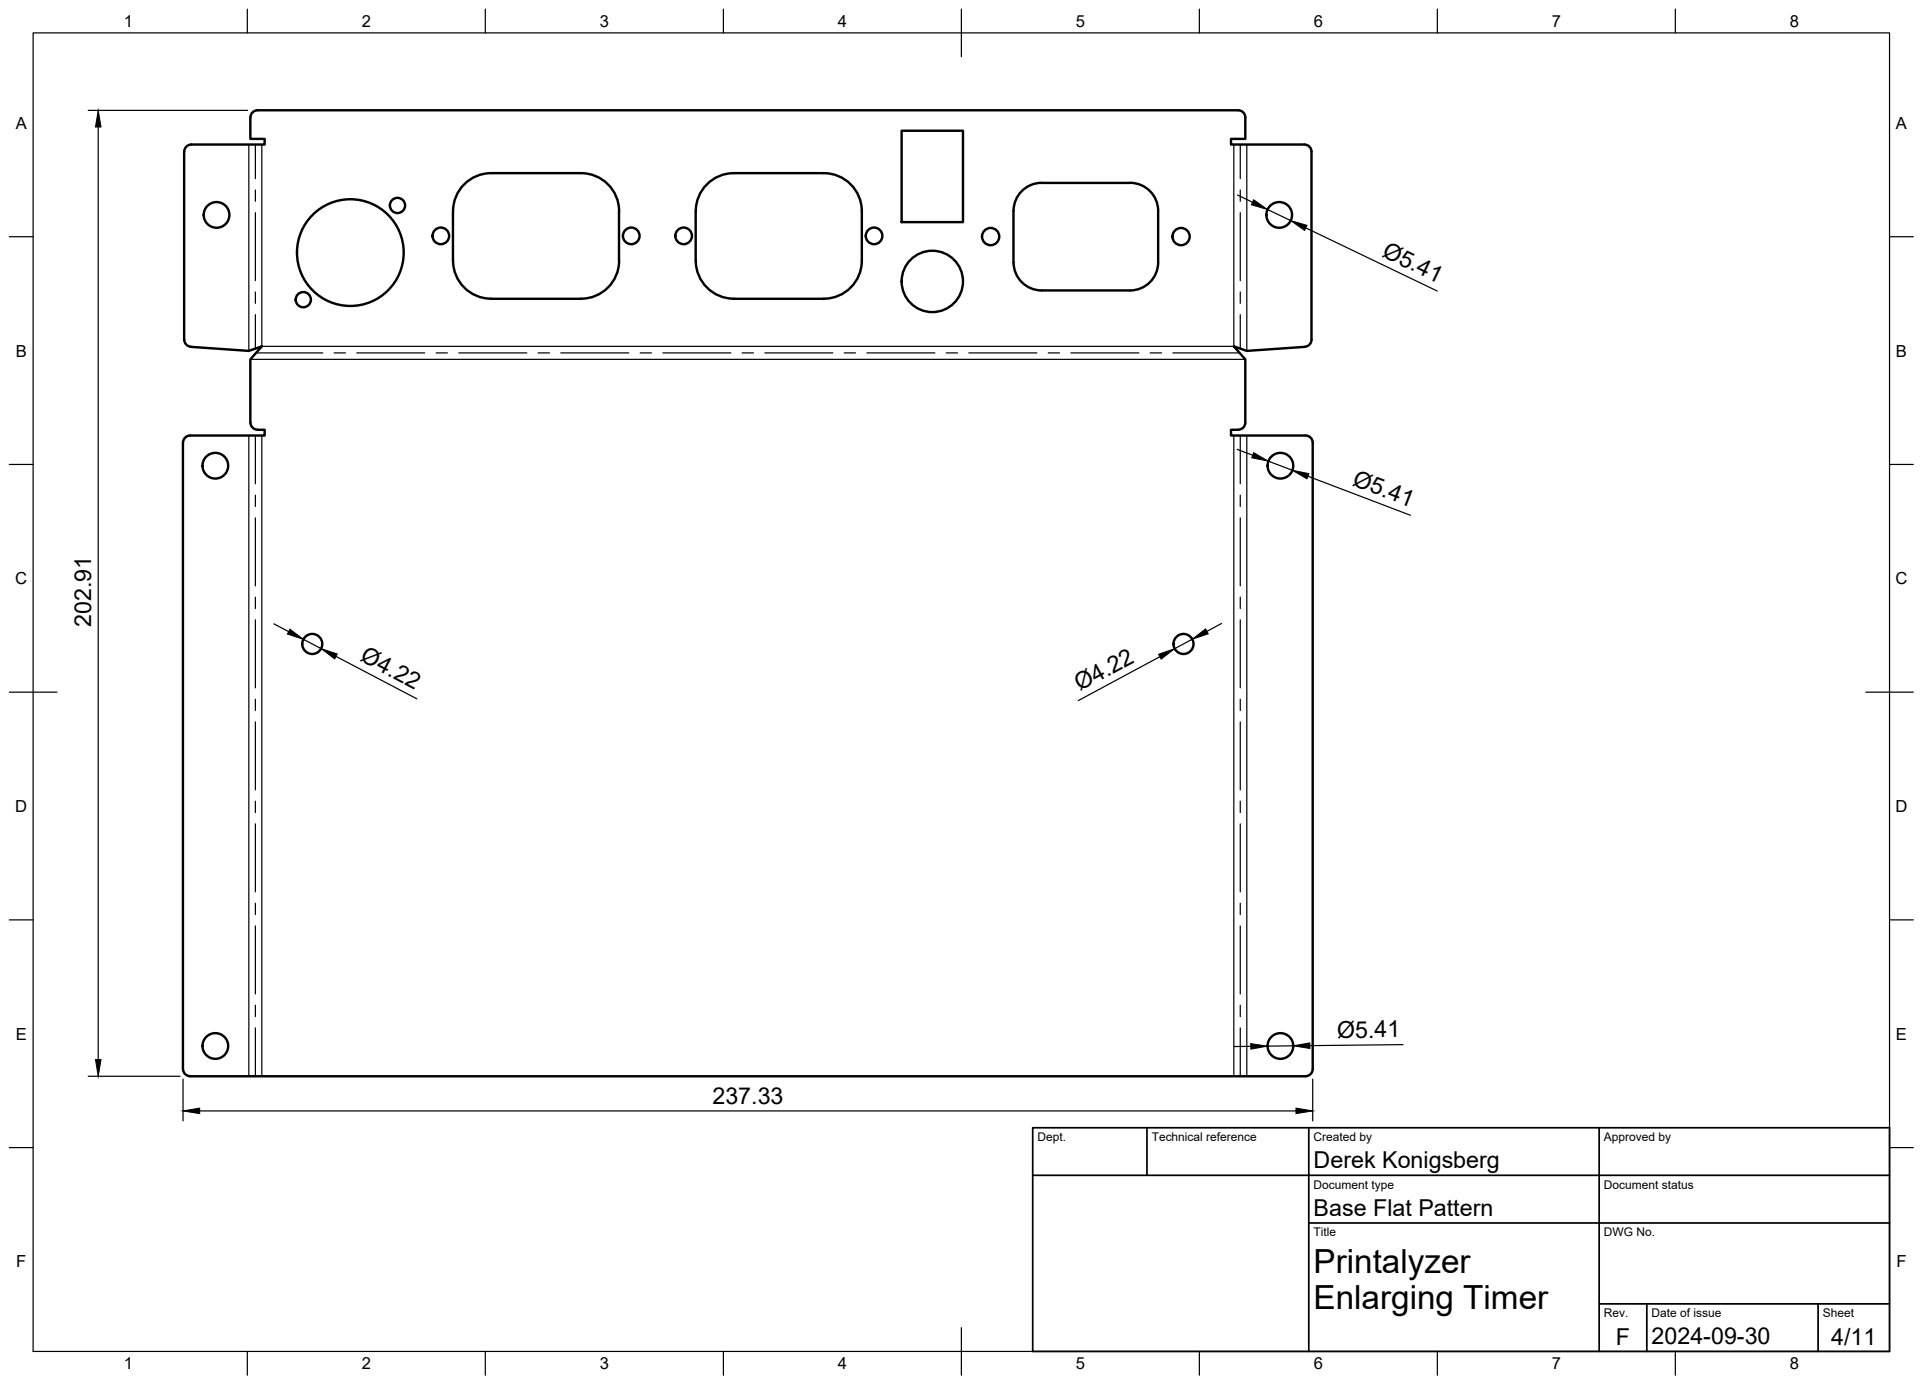
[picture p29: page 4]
Title; DWG No.

Dept. | Technical reference | Created by Derek Konigsberg | Approved by

Document type Base Flat Pattern | Document status

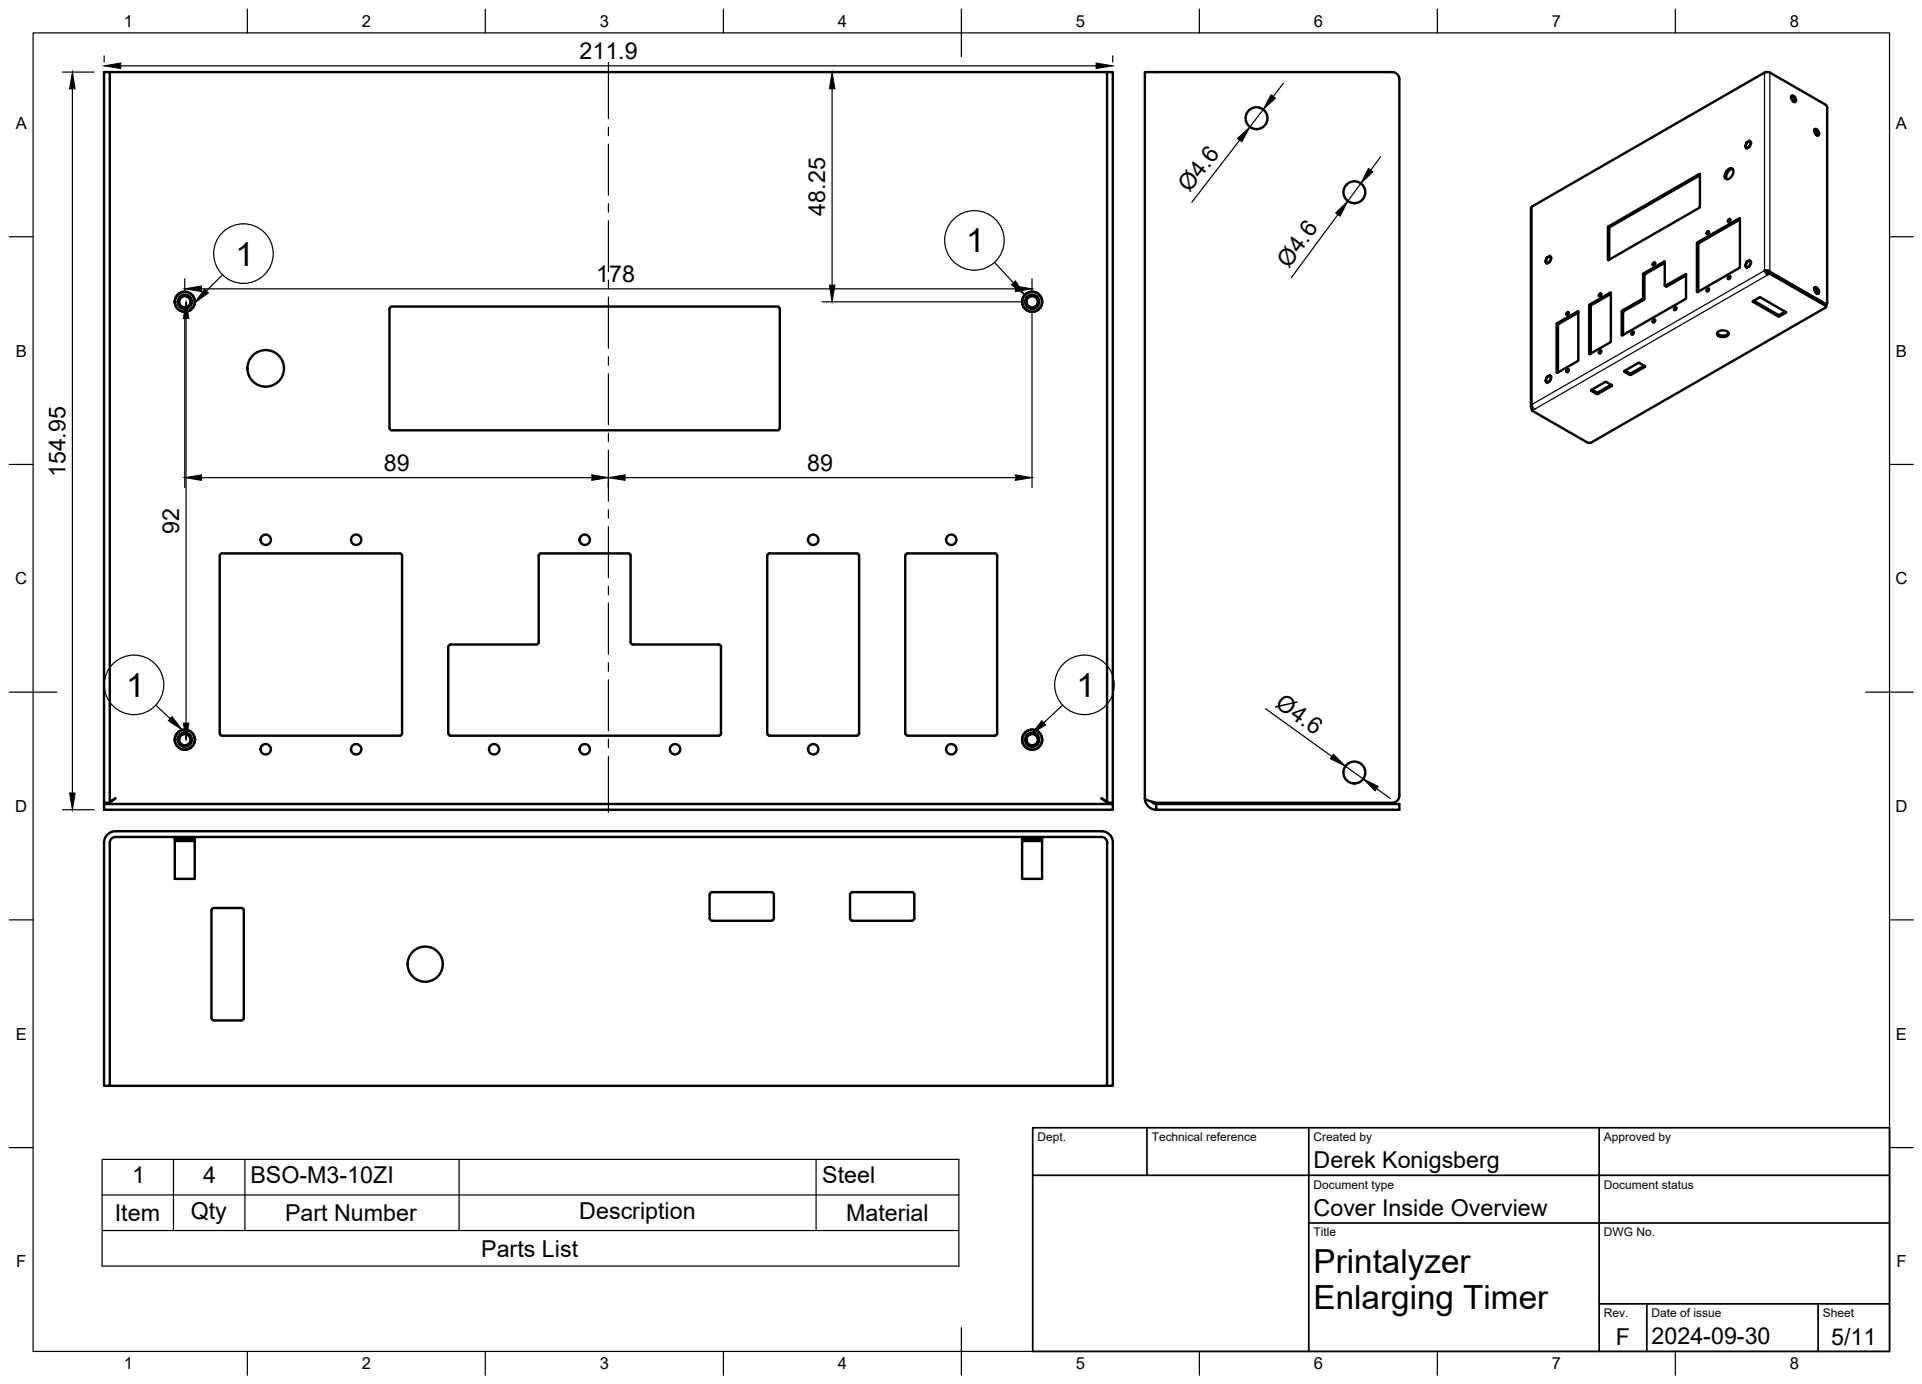
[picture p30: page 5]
Title; DWG No.; Parts List

Dept. | Technical reference | Created by Derek Konigsberg | Approved by

1 | 4 | BSO-M3-10ZI | | Steel
Item | Qty | Part Number | Description | Material

Document type Cover Inside Overview | Document status

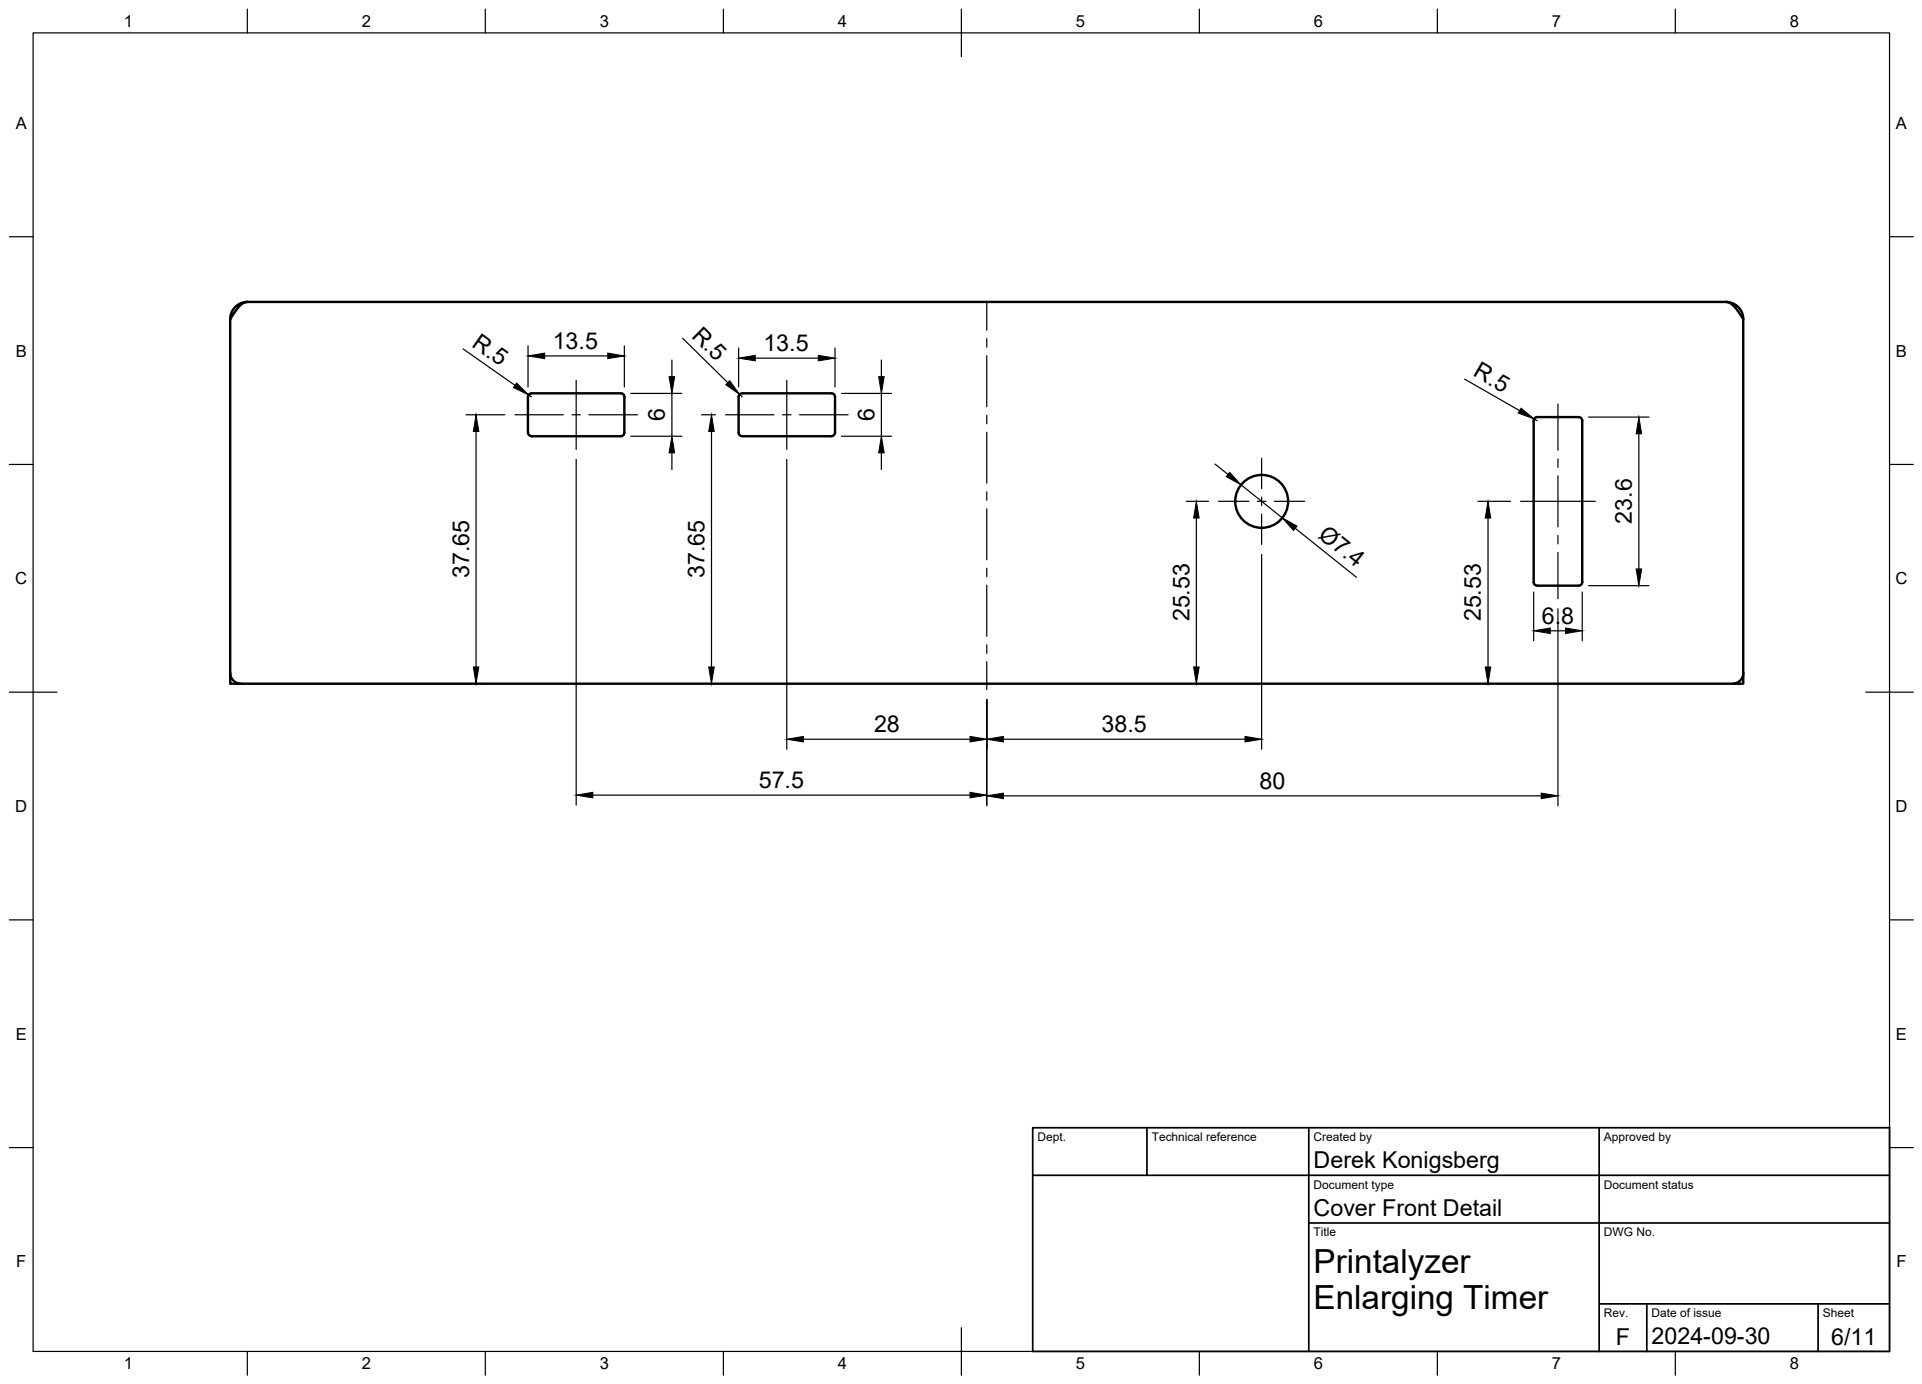
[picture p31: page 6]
Title; DWG No.

Dept. | Technical reference | Created by Derek Konigsberg | Approved by

Document type Cover Front Detail | Document status

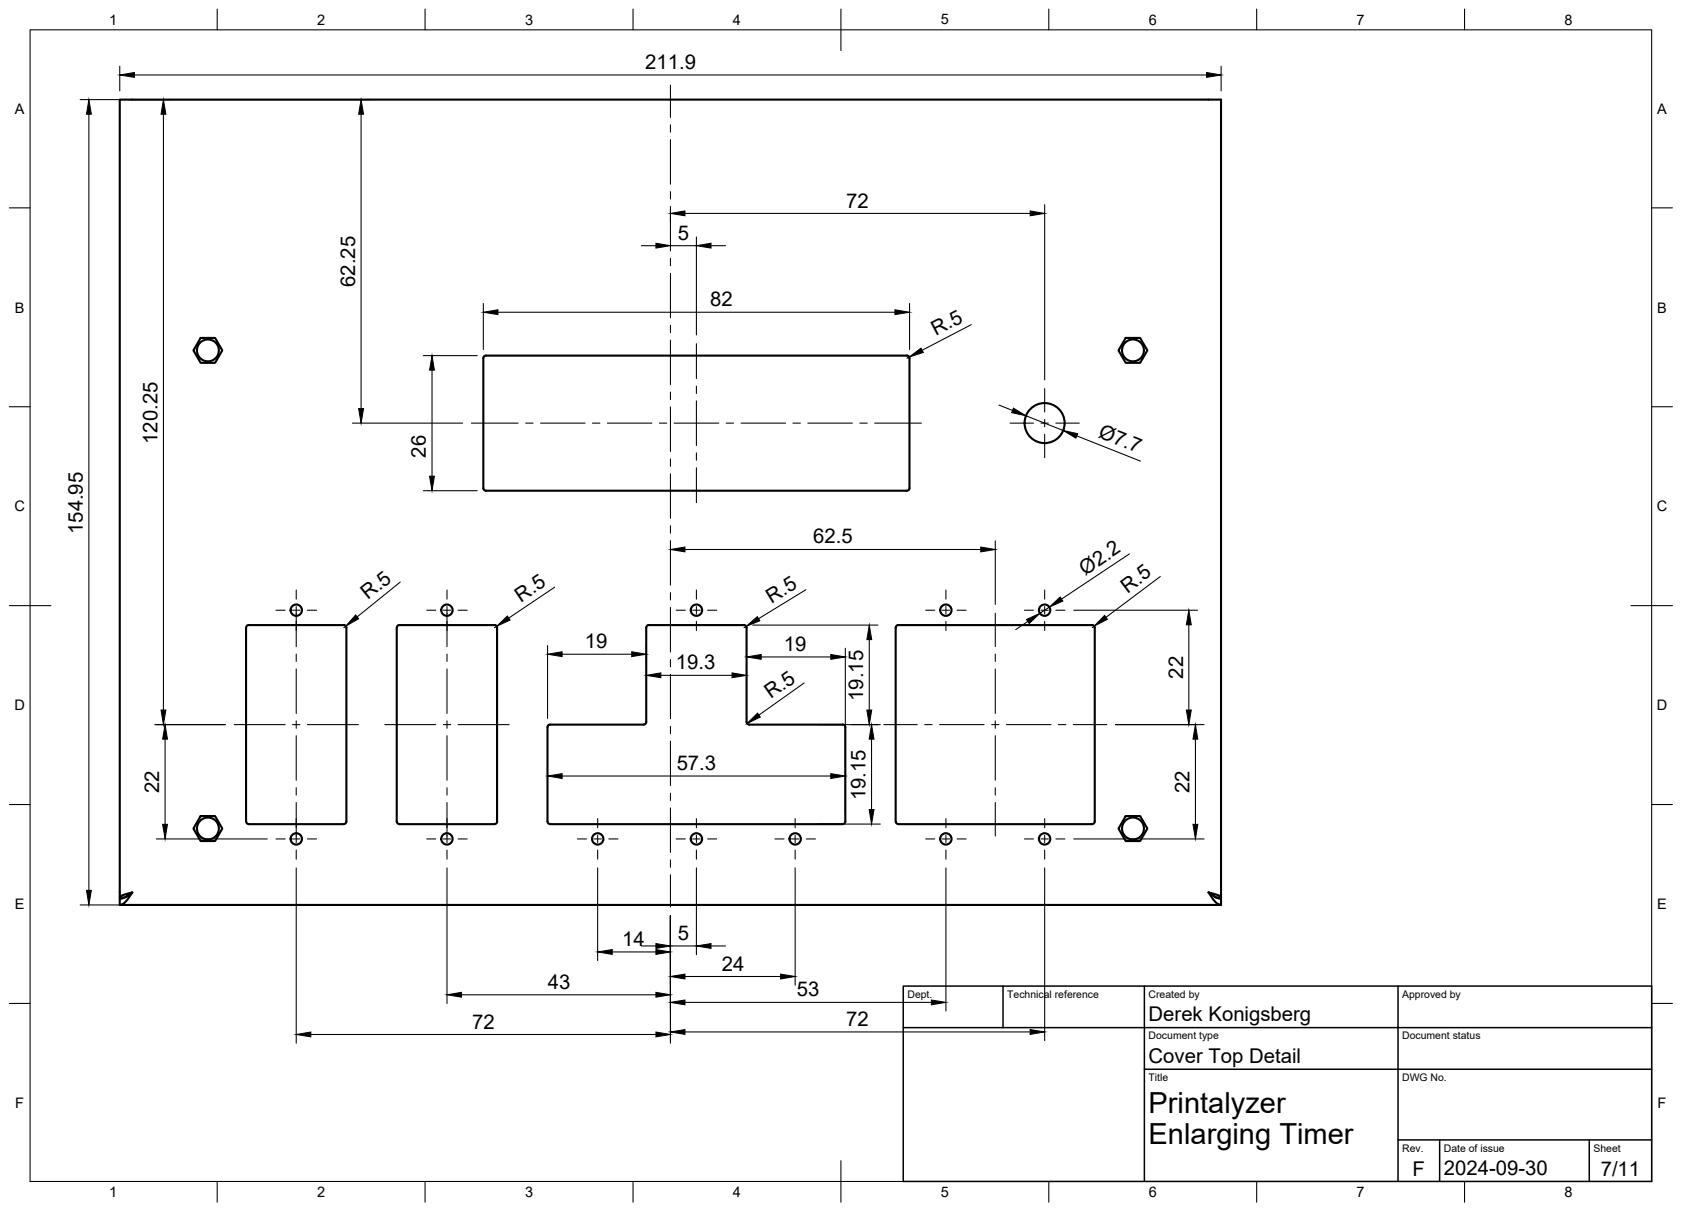
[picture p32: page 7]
Dept.; Technical reference; Created by; Approved by; Document type; Document status; Title; DWG No.; Derek Konigsberg 154.95

Cover Top Detail
Printalyzer

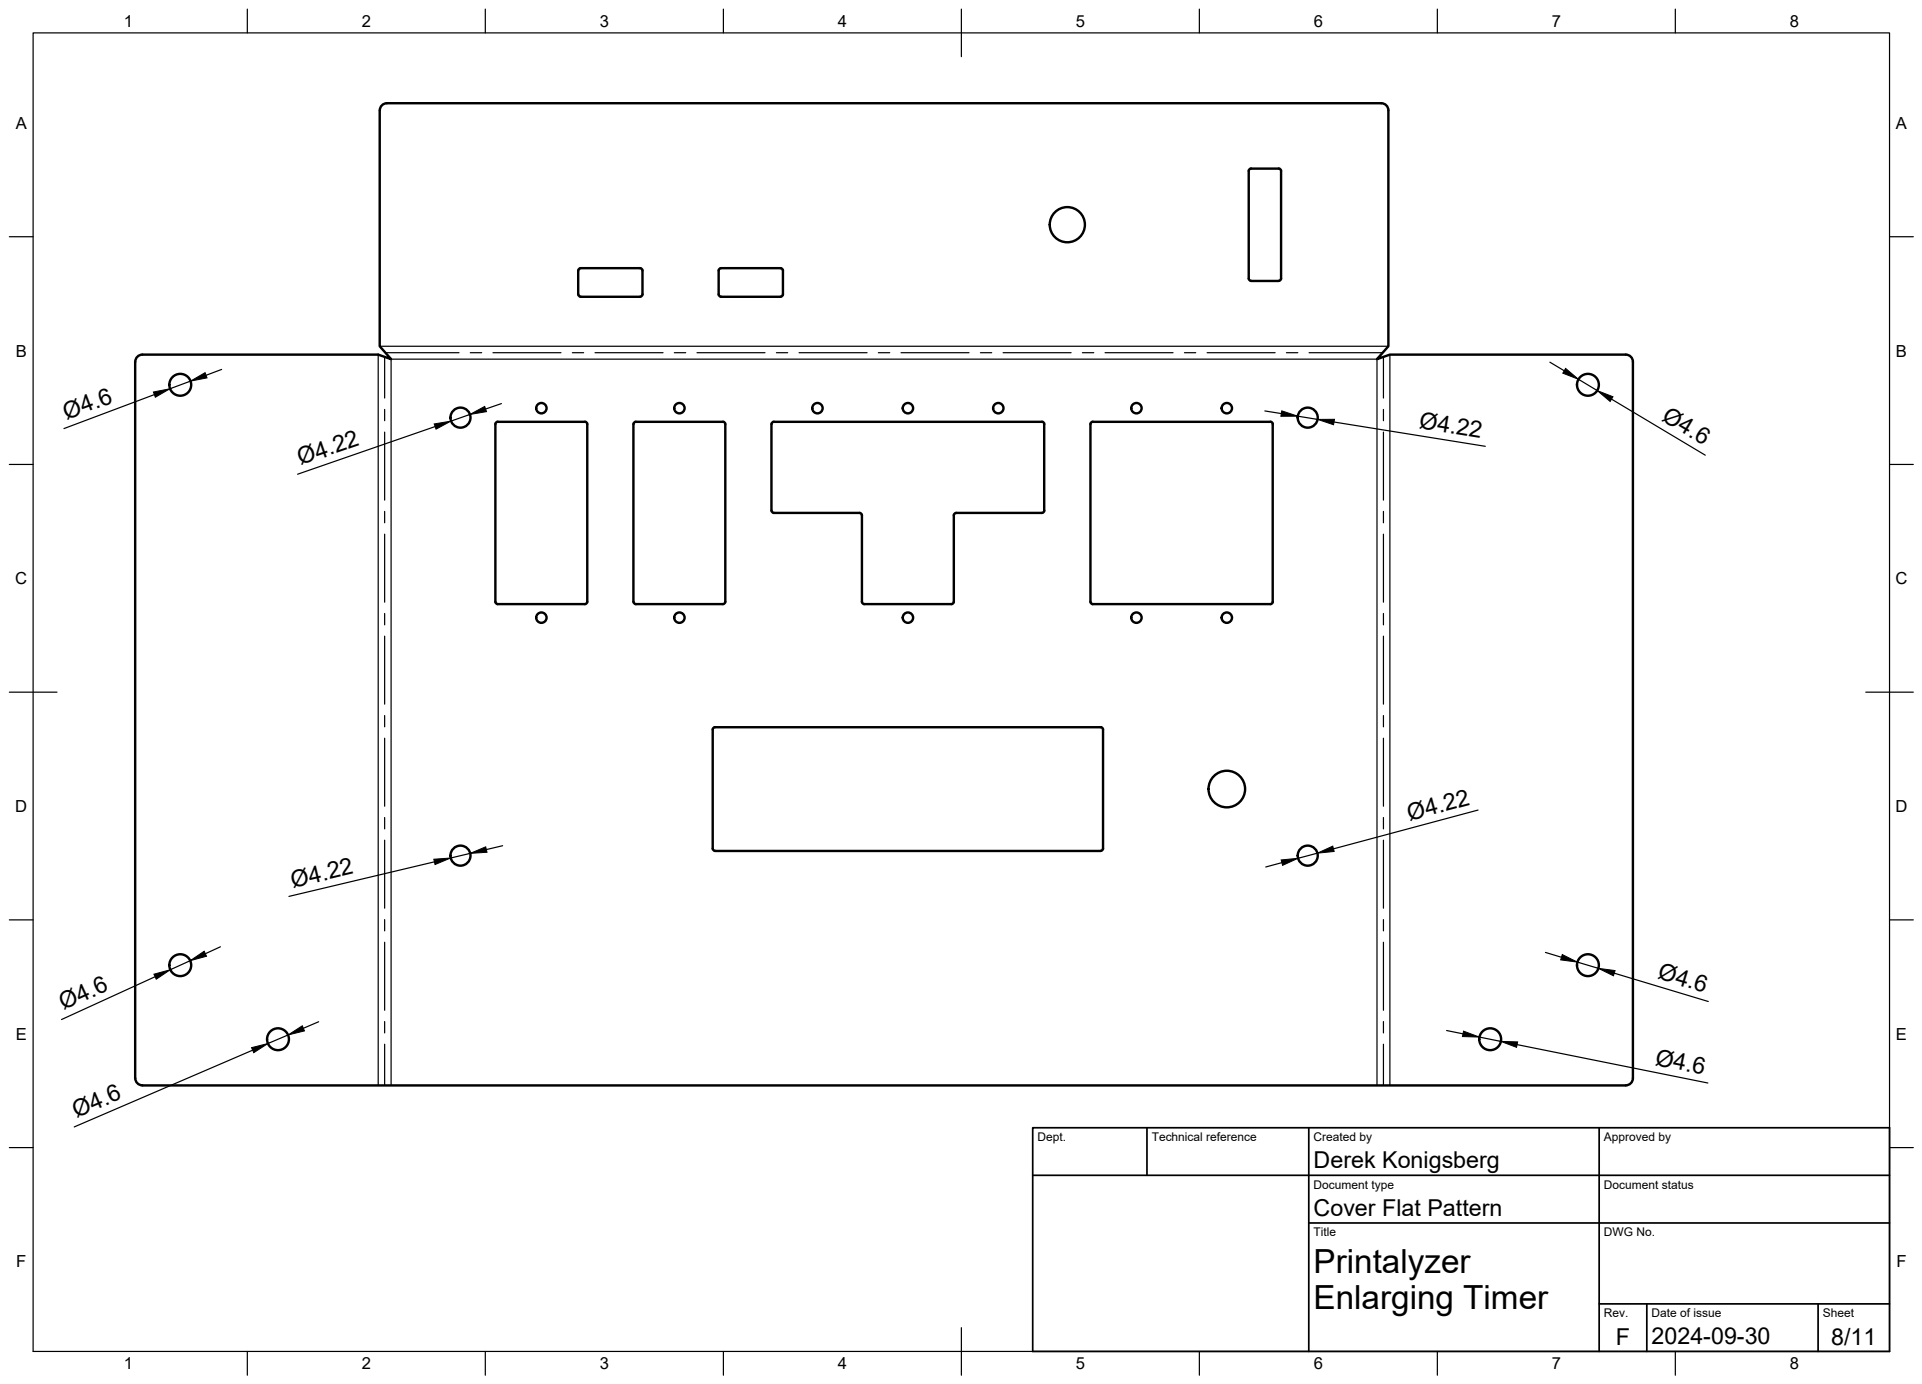
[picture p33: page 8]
Title; DWG No.

Dept. | Technical reference | Created by Derek Konigsberg | Approved by

Document type Cover Flat Pattern | Document status

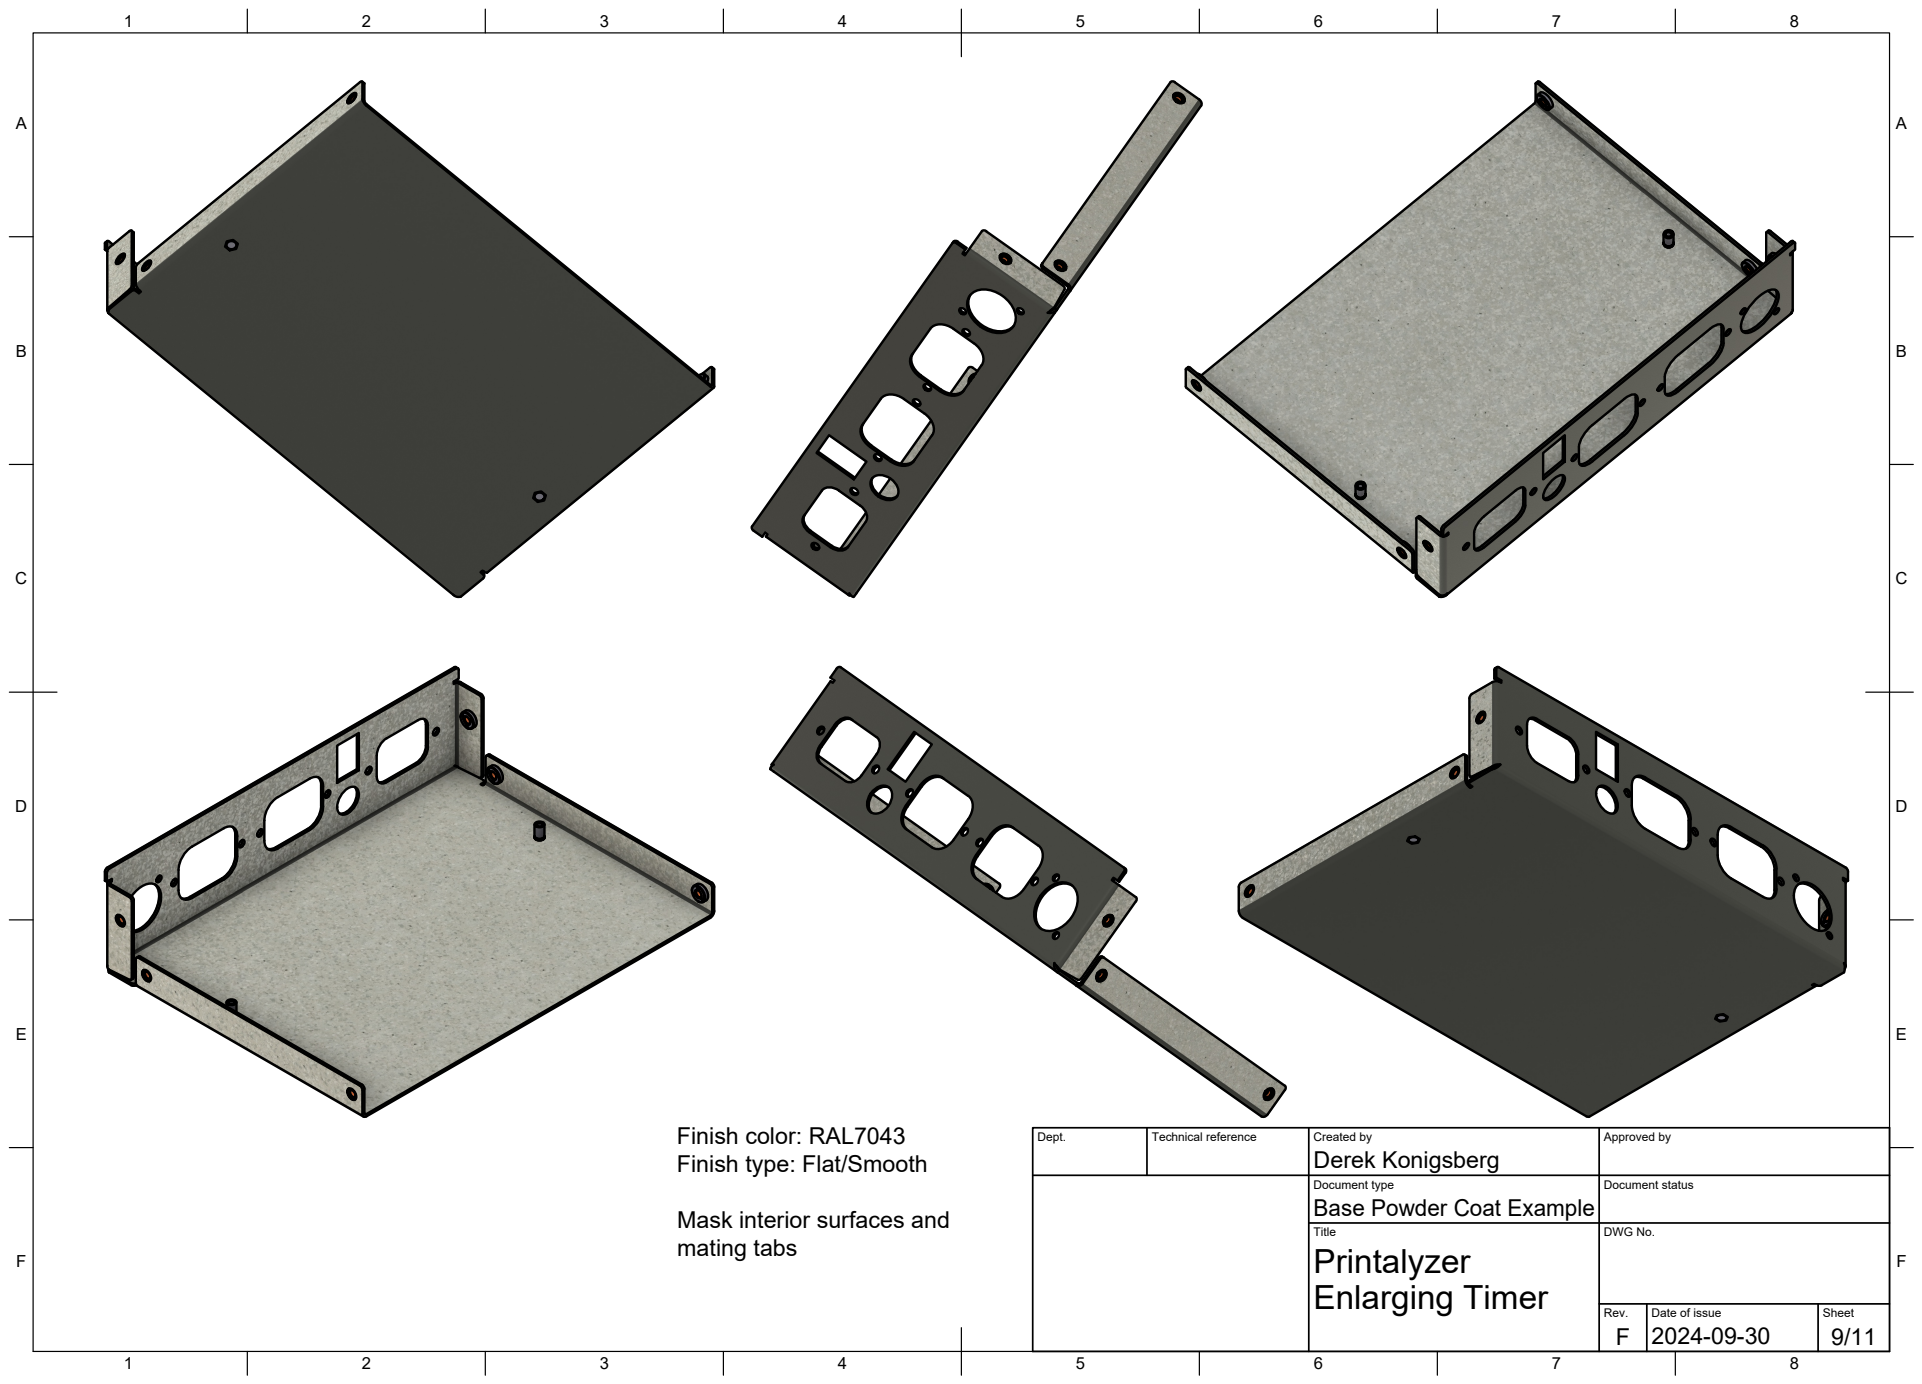
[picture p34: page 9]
Title; DWG No.

Finish color: RAL7043
Finish type: Flat/Smooth

Dept. | Technical reference | Created by Derek Konigsberg | Approved by

Document type Base Powder Coat Example | Document status

Mask interior surfaces and
mating tabs

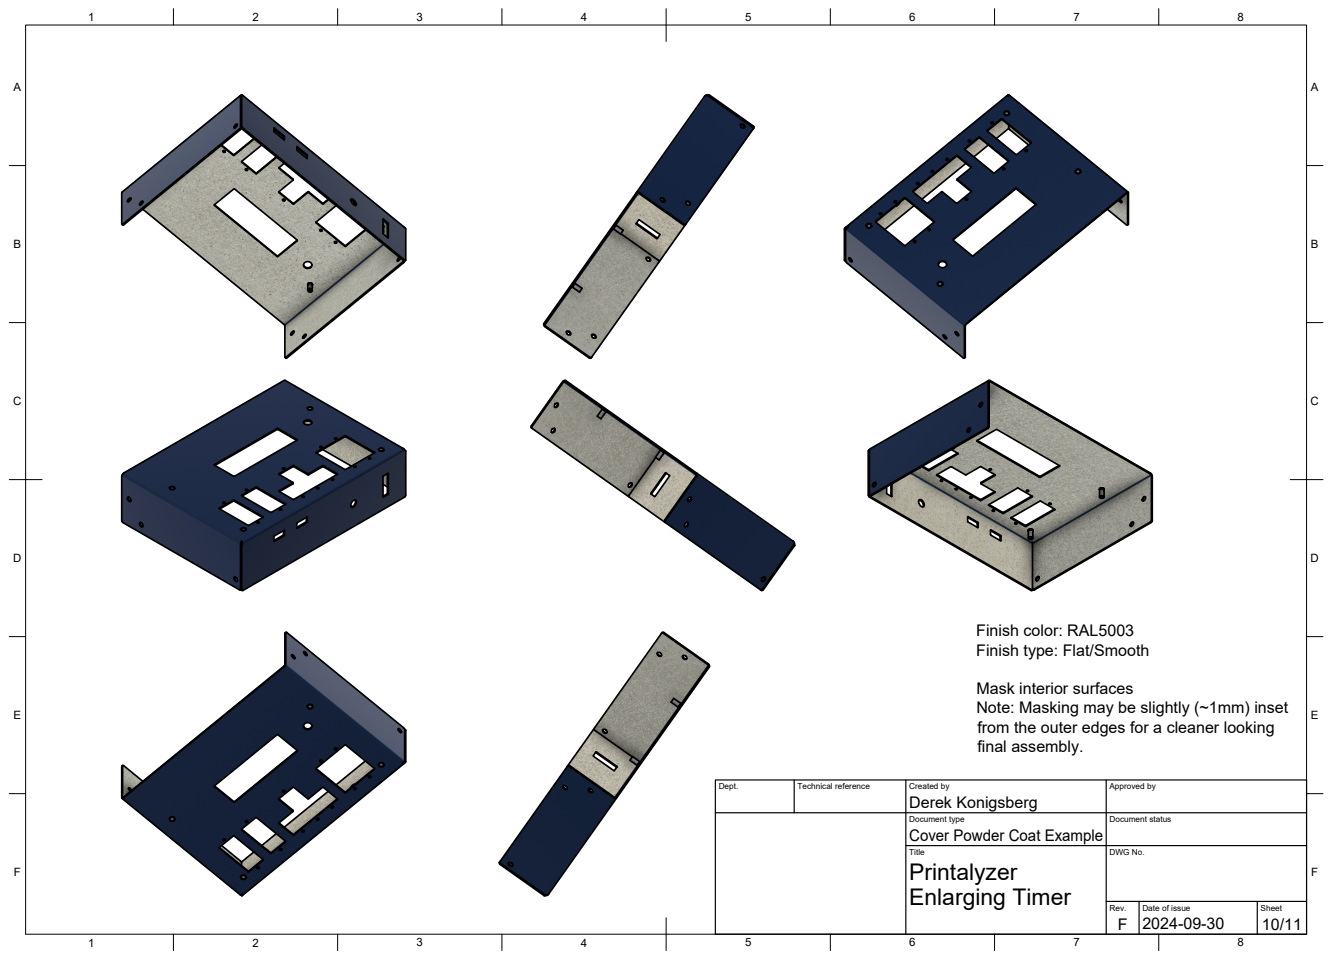
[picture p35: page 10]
Title; DWG No.

Finish color: RAL5003
Finish type: Flat/Smooth

Mask interior surfaces
Note: Masking may be slightly (~1mm) inset
from the outer edges for a cleaner looking
final assembly.

Dept. | Technical reference | Created by Derek Konigsberg | Approved by

Document type Cover Powder Coat Example | Document status

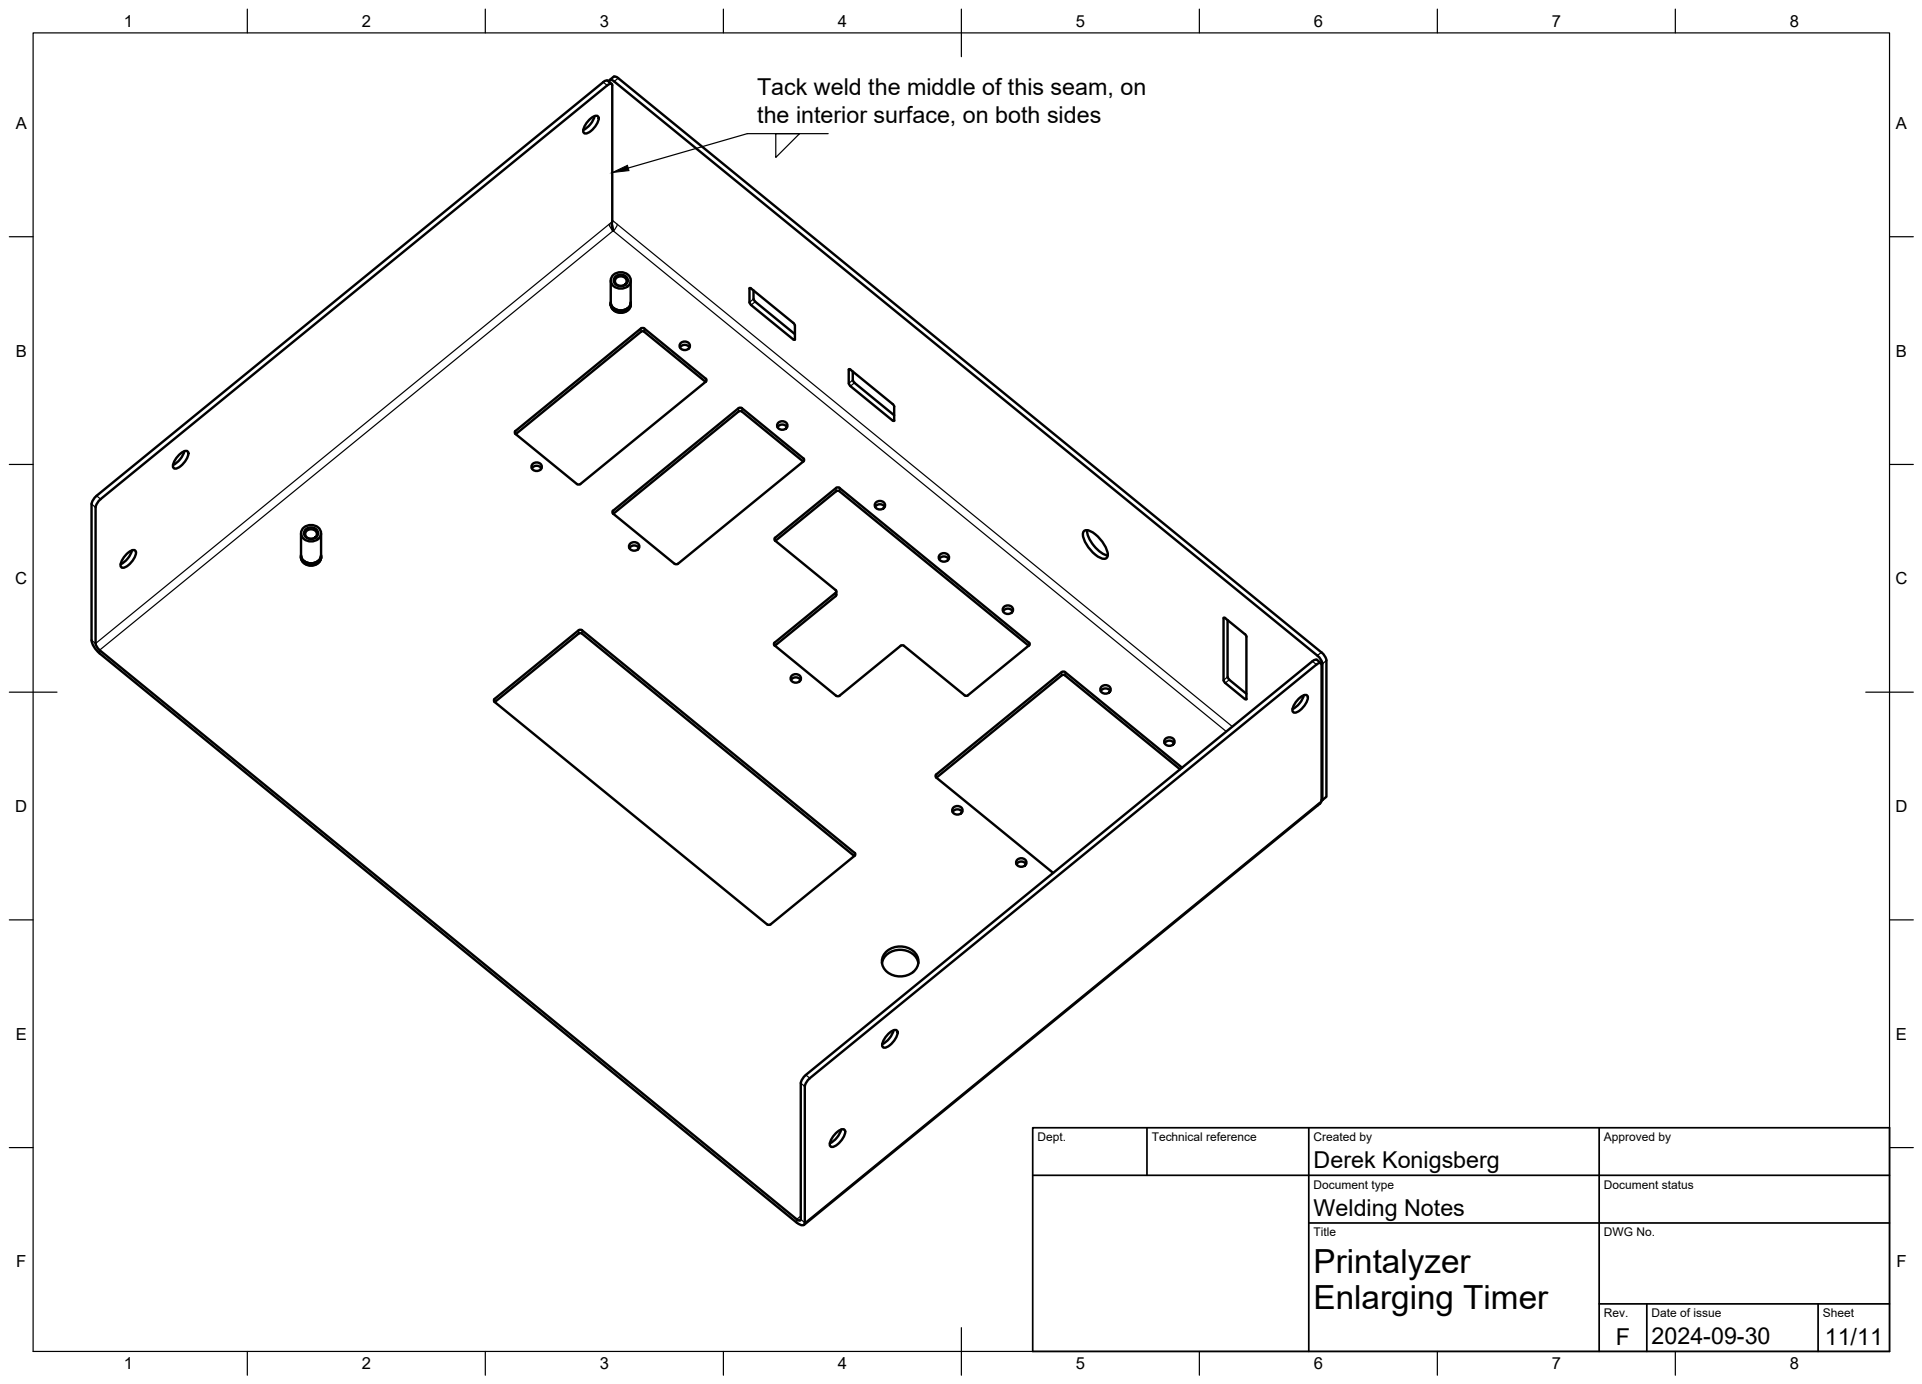
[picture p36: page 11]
Title; DWG No.

Tack weld the middle of this seam, on
the interior surface, on both sides

Dept. | Technical reference | Created by Derek Konigsberg | Approved by

Document type Welding Notes | Document status

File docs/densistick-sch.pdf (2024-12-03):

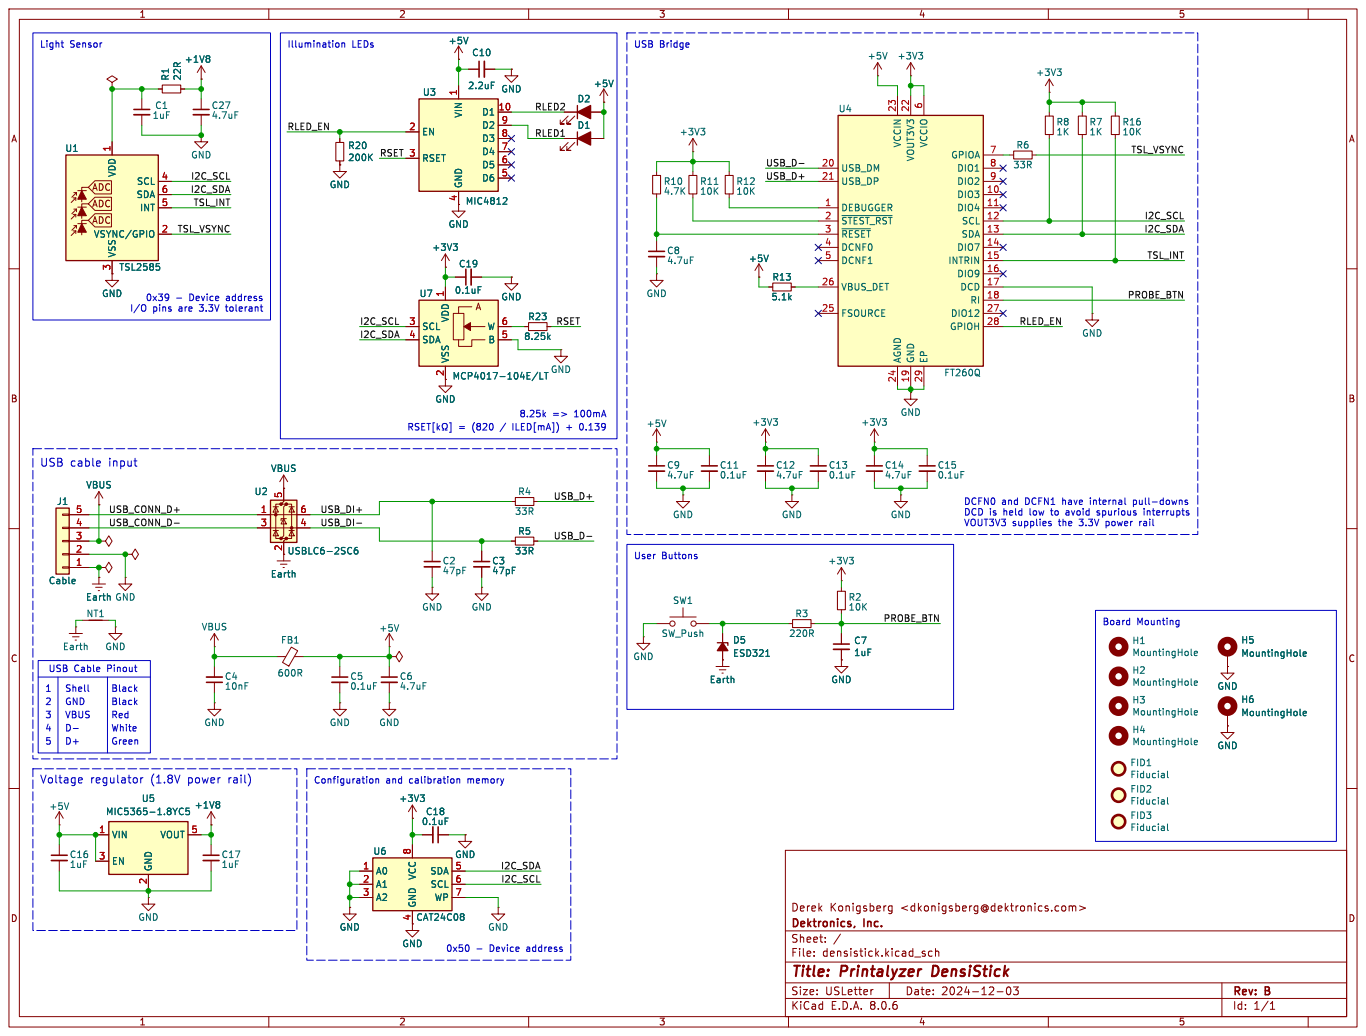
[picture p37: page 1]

INTRIN 15 DIO9 16 DCD 17 RI 18 GND 19

H4 MountingHole FID1 Fiducial FID2 Fiducial FID3 Fiducial C12
4.7uF GND

4 SDA 5 SCL 6 WP 7 VCC

Id: 1/1 Title: Printalyzer DensiStick

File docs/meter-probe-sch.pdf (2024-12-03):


2 EN 3 VOUT 5 Earth GND

4 SDA 5 SCL 6 WP 7 VCC

Id: 1/1 Title: Printalyzer - Meter Probe

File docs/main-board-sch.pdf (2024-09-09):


Microcontroller 0.1uF caps are for each power pin

Power Supply and Control File: main-board-power.kicad_sch VBAT

1 PC2 10 PC3 11 VSSA 12 VDDA 13 PA0 14 PA1 15 TIM9_CH1 16 PA3 17 VSS 18 VDD 19 PC13 2 PA4 20 SPI1_SCK 21 PA6 22 SPI1_MOSI 23 PC4 24 PC5 25 PB0 26 PB1 27 PB2 28

Front External Connections File: main-board-front.kicad_sch

1 VSS 10 VSS 11 VSS 12 VSS 13

4 SDA 5 SCL 6 WP 7 VCC

Id: 1/4 Title: Printalyzer - Main Board


Id: 2/4 Title: Printalyzer - Main Board


SW8 Add Adjustment GND GND

Id: 3/4 Title: Printalyzer - Main Board


1 CRFILT 10 PRTPWR2 11 ~{OCS2}12 SMBDATA/NON_REM1 13 SMBCLK/CFG_SEL 14 ~{RESET} 15 VBUS_DET 16 SUSP_IND/LOCAL_PWR/NON_REM0 17 VDD33 18 USBDM_UP 19 USBDM_DN1/PRT_DIS_M1 2 USBDP_UP 20 XTALOUT 21 XTALIN/CLKIN 22 PLLFILT 23 RBIAS 24 VSS 25 USBDP_DN1/PRT_DIS_P1 3 USBDM_DN2/PRT_DIS_M2 4 USBDP_DN2/PRT_DIS_P2 5 PRTPWR1/BC_EN1 7 ~{OCS1} 8 VDD33 U9 9 USB2422

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

0.1uF next to pins 1 and 18
1uF next to pin 9
10K GND GND

Id: 4/4 Title: Printalyzer - Main Board

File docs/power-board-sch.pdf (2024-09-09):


4 K1SPST-NO
IEC320-C13 Enlarger Power Output LINE
2 AC_E 3 K1SPST-NO

J1 Power Switch F1 Main Fuse

the rest of the board, except for chassis ground.

Id: 1/1 Title: Printalyzer - Power Input Board

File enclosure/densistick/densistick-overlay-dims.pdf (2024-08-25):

SIZE; CODE; DWG NO; REV; Derek Konigsberg 7/22/2024

PROJECT
Printalyzer DensiStick
DensiStick Graphic Overlay

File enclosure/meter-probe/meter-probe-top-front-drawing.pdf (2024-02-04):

SIZE; CODE; DWG NO; REV; Derek Konigsberg2/4/2024

PROJECT
Printalyzer Meter Probe
Top Front Overlay


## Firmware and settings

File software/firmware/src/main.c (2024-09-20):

#include <stm32f4xx_hal.h>

#include <stdio.h>
#include <cmsis_os.h>

#ifdef USE_SEGGER_RTT
#include "SEGGER_RTT.h"
#endif

#define LOG_TAG "main"
#include <elog.h>

#include "board_config.h"
#include "main_task.h"
#include "gpio_task.h"
#include "dmx.h"

CRC_HandleTypeDef hcrc;

UART_HandleTypeDef huart1;
UART_HandleTypeDef huart6;
DMA_HandleTypeDef hdma_usart6_tx;

I2C_HandleTypeDef hi2c1;
SMBUS_HandleTypeDef hsmbus2;

SPI_HandleTypeDef hspi1;

TIM_HandleTypeDef htim1;
TIM_HandleTypeDef htim4;
TIM_HandleTypeDef htim8;
TIM_HandleTypeDef htim9;
TIM_HandleTypeDef htim10;

static void system_clock_config(void);
static void peripheral_common_clock_config(void);
static void mpu_config();

static void usart1_uart_init(void);
static void usart6_uart_init(void);
static void gpio_init(void);
static void dma_init(void);
static void i2c1_init(void);
static void i2c2_smbus_init(void);
static void spi1_init(void);
static void tim1_init(void);
static void tim4_init(void);
static void tim8_init(void);
static void tim9_init(void);
static void tim10_init(void);
static void crc_init(void);

static void usart_deinit(void);
static void gpio_deinit(void);
static void dma_deinit(void);
static void i2c_deinit(void);
static void spi_deinit(void);
static void tim_deinit(void);
static void crc_deinit(void);
void deinit_peripherals();

static void logger_init(void);

void Error_Handler(void);
void HAL_TIM_MspPostInit(TIM_HandleTypeDef *htim);

void system_clock_config(void)
{
    RCC_OscInitTypeDef RCC_OscInitStruct = {0};
    RCC_ClkInitTypeDef RCC_ClkInitStruct = {0};

    /* Configure the main internal regulator output voltage */
    __HAL_RCC_PWR_CLK_ENABLE();
    __HAL_PWR_VOLTAGESCALING_CONFIG(PWR_REGULATOR_VOLTAGE_SCALE1);

    /*
     * Initialize the RCC Oscillators according to the specified parameters
     * in the RCC_OscInitTypeDef structure.
     */
    RCC_OscInitStruct.OscillatorType = RCC_OSCILLATORTYPE_HSE;
    RCC_OscInitStruct.HSEState = RCC_HSE_ON;
    RCC_OscInitStruct.PLL.PLLState = RCC_PLL_ON;
    RCC_OscInitStruct.PLL.PLLSource = RCC_PLLSOURCE_HSE;
    RCC_OscInitStruct.PLL.PLLM = 8;
    RCC_OscInitStruct.PLL.PLLN = 180;
    RCC_OscInitStruct.PLL.PLLP = RCC_PLLP_DIV2;
    RCC_OscInitStruct.PLL.PLLQ = 8;
    RCC_OscInitStruct.PLL.PLLR = 2;
    if (HAL_RCC_OscConfig(&RCC_OscInitStruct) != HAL_OK) {
        Error_Handler();
    }

    /* Activate the Over-Drive mode */
    if (HAL_PWREx_EnableOverDrive() != HAL_OK) {
        Error_Handler();
    }

    /* Initialize the CPU, AHB and APB buses clocks */
    RCC_ClkInitStruct.ClockType = RCC_CLOCKTYPE_HCLK|RCC_CLOCKTYPE_SYSCLK
                                  |RCC_CLOCKTYPE_PCLK1|RCC_CLOCKTYPE_PCLK2;
    RCC_ClkInitStruct.SYSCLKSource = RCC_SYSCLKSOURCE_PLLCLK;
    RCC_ClkInitStruct.AHBCLKDivider = RCC_SYSCLK_DIV1;
    RCC_ClkInitStruct.APB1CLKDivider = RCC_HCLK_DIV4;
    RCC_ClkInitStruct.APB2CLKDivider = RCC_HCLK_DIV2;
    if (HAL_RCC_ClockConfig(&RCC_ClkInitStruct, FLASH_LATENCY_5) != HAL_OK) {
        Error_Handler();
    }

    /* Activate the MCO2 pin to supply a 24MHz clock to the on-board USB hub */
    HAL_RCC_MCOConfig(RCC_MCO2, RCC_MCO2SOURCE_PLLI2SCLK, RCC_MCODIV_2);
}

void peripheral_common_clock_config(void)
{
    RCC_PeriphCLKInitTypeDef PeriphClkInitStruct = {0};

    /* Initializes the peripherals clock */
    PeriphClkInitStruct.PeriphClockSelection = RCC_PERIPHCLK_PLLI2S;
    PeriphClkInitStruct.PLLI2S.PLLI2SN = 96;
    PeriphClkInitStruct.PLLI2S.PLLI2SP = RCC_PLLI2SP_DIV2;
    PeriphClkInitStruct.PLLI2S.PLLI2SM = 8;
    PeriphClkInitStruct.PLLI2S.PLLI2SR = 4;
    PeriphClkInitStruct.PLLI2S.PLLI2SQ = 2;
    PeriphClkInitStruct.PLLI2SDivQ = 1;
    if (HAL_RCCEx_PeriphCLKConfig(&PeriphClkInitStruct) != HAL_OK) {
        Error_Handler();
    }
}

void mpu_config(void)
{
    MPU_Region_InitTypeDef MPU_InitStruct = {0};

    HAL_MPU_Disable();

    MPU_InitStruct.Enable = MPU_REGION_ENABLE;
    MPU_InitStruct.BaseAddress = 0x20000000;
    MPU_InitStruct.Size = MPU_REGION_SIZE_128KB;
    MPU_InitStruct.AccessPermission = MPU_REGION_FULL_ACCESS;
    MPU_InitStruct.IsBufferable = MPU_ACCESS_NOT_BUFFERABLE;
    MPU_InitStruct.IsCacheable = MPU_ACCESS_CACHEABLE;
    MPU_InitStruct.IsShareable = MPU_ACCESS_SHAREABLE;
    MPU_InitStruct.Number = MPU_REGION_NUMBER0;
    MPU_InitStruct.TypeExtField = MPU_TEX_LEVEL0;
    MPU_InitStruct.SubRegionDisable = 0x00;
    MPU_InitStruct.DisableExec = MPU_INSTRUCTION_ACCESS_DISABLE;
    HAL_MPU_ConfigRegion(&MPU_InitStruct);

    HAL_MPU_Enable(MPU_PRIVILEGED_DEFAULT);
}

void usart1_uart_init(void)
{
    /*
     * USART1 is used for debug logging
     */
    huart1.Instance = USART1;
    huart1.Init.BaudRate = 115200;
    huart1.Init.WordLength = UART_WORDLENGTH_8B;
    huart1.Init.StopBits = UART_STOPBITS_1;
    huart1.Init.Parity = UART_PARITY_NONE;
    huart1.Init.Mode = UART_MODE_TX_RX;
    huart1.Init.HwFlowCtl = UART_HWCONTROL_NONE;
    huart1.Init.OverSampling = UART_OVERSAMPLING_16;
    if (HAL_UART_Init(&huart1) != HAL_OK) {
        Error_Handler();
    }
}

void usart6_uart_init(void)
{
    /*
     * USART6 is used for the DMX512 port
     */
    huart6.Instance = USART6;
    huart6.Init.BaudRate = 250000;
    huart6.Init.WordLength = UART_WORDLENGTH_8B;
    huart6.Init.StopBits = UART_STOPBITS_2;
    huart6.Init.Parity = UART_PARITY_NONE;
    huart6.Init.Mode = UART_MODE_TX_RX;
    huart6.Init.HwFlowCtl = UART_HWCONTROL_NONE;
    huart6.Init.OverSampling = UART_OVERSAMPLING_16;
    if (HAL_UART_Init(&huart6) != HAL_OK) {
        Error_Handler();
    }
}

void gpio_init(void)
{
    GPIO_InitTypeDef GPIO_InitStruct = {0};

    /* GPIO Ports Clock Enable */
    __HAL_RCC_GPIOC_CLK_ENABLE();
    __HAL_RCC_GPIOH_CLK_ENABLE();
    __HAL_RCC_GPIOA_CLK_ENABLE();
    __HAL_RCC_GPIOB_CLK_ENABLE();
    __HAL_RCC_GPIOD_CLK_ENABLE();

    /* Configure GPIO pin Output Level */
    HAL_GPIO_WritePin(GPIOC, LED_RESET_Pin|DISP_RESET_Pin|KEY_RESET_Pin|DMX512_TX_EN_Pin|RELAY_SFLT_Pin, GPIO_PIN_RESET);

    /* Configure GPIO pin Output Level */
    HAL_GPIO_WritePin(GPIOA, BUZZ_EN1_Pin|BUZZ_EN2_Pin|DISP_CS_Pin|DISP_DC_Pin, GPIO_PIN_RESET);

    /* Configure GPIO pin Output Level */
    HAL_GPIO_WritePin(GPIOB, USB_HUB_RESET_Pin|USB_DRIVE_VBUS_Pin, GPIO_PIN_RESET);

    /* Configure GPIO pin Output Level */
    HAL_GPIO_WritePin(DMX512_RX_EN_GPIO_Port, DMX512_RX_EN_Pin, GPIO_PIN_SET);

    /* Configure GPIO pin Output Level */
    HAL_GPIO_WritePin(RELAY_ENLG_GPIO_Port, RELAY_ENLG_Pin, GPIO_PIN_RESET);

    /* Configure unused GPIO pins : PC13 PC14 PC15 PC0 PC3 PC5 */
    GPIO_InitStruct.Pin = GPIO_PIN_13|GPIO_PIN_14|GPIO_PIN_15|GPIO_PIN_0
                          |GPIO_PIN_1|GPIO_PIN_3|GPIO_PIN_10;
    GPIO_InitStruct.Mode = GPIO_MODE_ANALOG;
    GPIO_InitStruct.Pull = GPIO_NOPULL;
    HAL_GPIO_Init(GPIOC, &GPIO_InitStruct);

    /* Configure GPIO pins: LED_RESET_Pin DISP_RESET_Pin DMX512_TX_EN_Pin RELAY_SFLT_Pin */
    GPIO_InitStruct.Pin = LED_RESET_Pin|DISP_RESET_Pin|DMX512_TX_EN_Pin|RELAY_SFLT_Pin;
    GPIO_InitStruct.Mode = GPIO_MODE_OUTPUT_PP;
    GPIO_InitStruct.Pull = GPIO_NOPULL;
    GPIO_InitStruct.Speed = GPIO_SPEED_FREQ_LOW;
    HAL_GPIO_Init(GPIOC, &GPIO_InitStruct);


    /* Configure GPIO pins: BUZZ_EN1_Pin BUZZ_EN2_Pin DISP_CS_Pin DISP_DC_Pin DMX512_RX_EN_Pin */
    GPIO_InitStruct.Pin = BUZZ_EN1_Pin|BUZZ_EN2_Pin|DISP_CS_Pin|DISP_DC_Pin
                          |DMX512_RX_EN_Pin;
    GPIO_InitStruct.Mode = GPIO_MODE_OUTPUT_PP;
    GPIO_InitStruct.Pull = GPIO_NOPULL;
    GPIO_InitStruct.Speed = GPIO_SPEED_FREQ_LOW;
    HAL_GPIO_Init(GPIOA, &GPIO_InitStruct);

    /* Configure GPIO pins: PA3 PA12 */
    GPIO_InitStruct.Pin = GPIO_PIN_3|GPIO_PIN_12;
    GPIO_InitStruct.Mode = GPIO_MODE_ANALOG;
    GPIO_InitStruct.Pull = GPIO_NOPULL;
    HAL_GPIO_Init(GPIOA, &GPIO_InitStruct);

    /* Configure GPIO pins: KEY_RESET_Pin */
    GPIO_InitStruct.Pin = KEY_RESET_Pin;
    GPIO_InitStruct.Mode = GPIO_MODE_OUTPUT_OD;
    GPIO_InitStruct.Pull = GPIO_NOPULL;
    GPIO_InitStruct.Speed = GPIO_SPEED_FREQ_LOW;
    HAL_GPIO_Init(KEY_RESET_GPIO_Port, &GPIO_InitStruct);

    /* Configure GPIO pins: PB0 PB1 PB2 PB4 PB9 */
    GPIO_InitStruct.Pin = GPIO_PIN_0|GPIO_PIN_1|GPIO_PIN_2|GPIO_PIN_4|GPIO_PIN_9;
    GPIO_InitStruct.Mode = GPIO_MODE_ANALOG;
    GPIO_InitStruct.Pull = GPIO_NOPULL;
    HAL_GPIO_Init(GPIOB, &GPIO_InitStruct);

    /* Configure GPIO pins: USB_HUB_RESET_Pin USB_DRIVE_VBUS_Pin */
    GPIO_InitStruct.Pin = USB_HUB_RESET_Pin|USB_DRIVE_VBUS_Pin;
    GPIO_InitStruct.Mode = GPIO_MODE_OUTPUT_PP;
    GPIO_InitStruct.Pull = GPIO_NOPULL;
    GPIO_InitStruct.Speed = GPIO_SPEED_FREQ_LOW;
    HAL_GPIO_Init(GPIOB, &GPIO_InitStruct);

    /* Configure GPIO pin: USB_HUB_CLK_Pin */
    GPIO_InitStruct.Pin = USB_HUB_CLK_Pin;
    GPIO_InitStruct.Mode = GPIO_MODE_AF_PP;
    GPIO_InitStruct.Pull = GPIO_NOPULL;
    GPIO_InitStruct.Speed = GPIO_SPEED_FREQ_LOW;
    GPIO_InitStruct.Alternate = GPIO_AF0_MCO;
    HAL_GPIO_Init(USB_HUB_CLK_GPIO_Port, &GPIO_InitStruct);

    /* Configure GPIO pin: RELAY_ENLG_Pin */
    GPIO_InitStruct.Pin = RELAY_ENLG_Pin;
    GPIO_InitStruct.Mode = GPIO_MODE_OUTPUT_PP;
    GPIO_InitStruct.Pull = GPIO_NOPULL;
    GPIO_InitStruct.Speed = GPIO_SPEED_FREQ_LOW;
    HAL_GPIO_Init(RELAY_ENLG_GPIO_Port, &GPIO_InitStruct);

    /* Configure GPIO pin: KEY_INT_Pin */
    GPIO_InitStruct.Pin = KEY_INT_Pin;
    GPIO_InitStruct.Mode = GPIO_MODE_IT_FALLING;
    GPIO_InitStruct.Pull = GPIO_NOPULL;
    HAL_GPIO_Init(KEY_INT_GPIO_Port, &GPIO_InitStruct);
}

void dma_init(void)
{
    /* DMA controller clock enable */
    __HAL_RCC_DMA2_CLK_ENABLE();

    /* DMA interrupt init */
    /* DMA2_Stream6_IRQn interrupt configuration */
    HAL_NVIC_SetPriority(DMA2_Stream6_IRQn, 5, 0);
    HAL_NVIC_EnableIRQ(DMA2_Stream6_IRQn);
}

void i2c1_init(void)
{
    /*
     * I2C1 is used for on-board devices
     */
    hi2c1.Instance = I2C1;
    hi2c1.Init.ClockSpeed = 400000;
    hi2c1.Init.DutyCycle = I2C_DUTYCYCLE_2;
    hi2c1.Init.OwnAddress1 = 0;
    hi2c1.Init.AddressingMode = I2C_ADDRESSINGMODE_7BIT;
    hi2c1.Init.DualAddressMode = I2C_DUALADDRESS_DISABLE;
    hi2c1.Init.OwnAddress2 = 0;
    hi2c1.Init.GeneralCallMode = I2C_GENERALCALL_DISABLE;
    hi2c1.Init.NoStretchMode = I2C_NOSTRETCH_DISABLE;
    if (HAL_I2C_Init(&hi2c1) != HAL_OK) {
        Error_Handler();
    }
}

void i2c2_smbus_init(void)
{
    /*
     * I2C2 is used to configure the on-board USB hub
     */
    hsmbus2.Instance = I2C2;
    hsmbus2.Init.ClockSpeed = 100000;
    hsmbus2.Init.OwnAddress1 = 0;
    hsmbus2.Init.AddressingMode = SMBUS_ADDRESSINGMODE_7BIT;
    hsmbus2.Init.DualAddressMode = SMBUS_DUALADDRESS_DISABLE;
    hsmbus2.Init.OwnAddress2 = 0;
    hsmbus2.Init.GeneralCallMode = SMBUS_GENERALCALL_DISABLE;
    hsmbus2.Init.NoStretchMode = SMBUS_NOSTRETCH_DISABLE;
    hsmbus2.Init.PacketErrorCheckMode = SMBUS_PEC_DISABLE;
    hsmbus2.Init.PeripheralMode = SMBUS_PERIPHERAL_MODE_SMBUS_HOST;
    if (HAL_SMBUS_Init(&hsmbus2) != HAL_OK) {
        Error_Handler();
    }
}

void spi1_init(void)
{
    /*
     * SPI1 is used for the display module
     */
    hspi1.Instance = SPI1;
    hspi1.Init.Mode = SPI_MODE_MASTER;
    hspi1.Init.Direction = SPI_DIRECTION_2LINES;
    hspi1.Init.DataSize = SPI_DATASIZE_8BIT;
    hspi1.Init.CLKPolarity = SPI_POLARITY_LOW;
    hspi1.Init.CLKPhase = SPI_PHASE_1EDGE;
    hspi1.Init.NSS = SPI_NSS_SOFT;
    hspi1.Init.BaudRatePrescaler = SPI_BAUDRATEPRESCALER_8;
    hspi1.Init.FirstBit = SPI_FIRSTBIT_MSB;
    hspi1.Init.TIMode = SPI_TIMODE_DISABLE;
    hspi1.Init.CRCCalculation = SPI_CRCCALCULATION_DISABLE;
    hspi1.Init.CRCPolynomial = 10;
    if (HAL_SPI_Init(&hspi1) != HAL_OK) {
        Error_Handler();
    }
}

void tim1_init(void)
{
    /*
     * TIM1 is used for the rotary encoder
     */
    TIM_Encoder_InitTypeDef sConfig = {0};
    TIM_MasterConfigTypeDef sMasterConfig = {0};

    htim1.Instance = TIM1;
    htim1.Init.Prescaler = 0;
    htim1.Init.CounterMode = TIM_COUNTERMODE_UP;
    htim1.Init.Period = 65535;
    htim1.Init.ClockDivision = TIM_CLOCKDIVISION_DIV1;
    htim1.Init.RepetitionCounter = 0;
    htim1.Init.AutoReloadPreload = TIM_AUTORELOAD_PRELOAD_DISABLE;
    sConfig.EncoderMode = TIM_ENCODERMODE_TI12;
    sConfig.IC1Polarity = TIM_ICPOLARITY_RISING;
    sConfig.IC1Selection = TIM_ICSELECTION_DIRECTTI;
    sConfig.IC1Prescaler = TIM_ICPSC_DIV1;
    sConfig.IC1Filter = 0x0F;
    sConfig.IC2Polarity = TIM_ICPOLARITY_RISING;
    sConfig.IC2Selection = TIM_ICSELECTION_DIRECTTI;
    sConfig.IC2Prescaler = TIM_ICPSC_DIV1;
    sConfig.IC2Filter = 0x0F;
    if (HAL_TIM_Encoder_Init(&htim1, &sConfig) != HAL_OK) {
        Error_Handler();
    }

    sMasterConfig.MasterOutputTrigger = TIM_TRGO_RESET;
    sMasterConfig.MasterSlaveMode = TIM_MASTERSLAVEMODE_DISABLE;

    if (HAL_TIMEx_MasterConfigSynchronization(&htim1, &sMasterConfig) != HAL_OK) {
        Error_Handler();
    }
}

void tim4_init(void)
{
    /*
     * TIM4 is used to generate an interrupt for controlling DMX512
     * signal timing.
     * Each tick of this timer should be 1 microsecond.
     */
    TIM_MasterConfigTypeDef sMasterConfig = {0};
    TIM_OC_InitTypeDef sConfigOC = {0};

    htim4.Instance = TIM4;
    htim4.Init.Prescaler = 89;
    htim4.Init.CounterMode = TIM_COUNTERMODE_UP;
    htim4.Init.Period = 99;
    htim4.Init.ClockDivision = TIM_CLOCKDIVISION_DIV1;
    htim4.Init.AutoReloadPreload = TIM_AUTORELOAD_PRELOAD_DISABLE;
    if (HAL_TIM_OC_Init(&htim4) != HAL_OK) {
        Error_Handler();
    }

    sMasterConfig.MasterOutputTrigger = TIM_TRGO_RESET;
    sMasterConfig.MasterSlaveMode = TIM_MASTERSLAVEMODE_DISABLE;
    if (HAL_TIMEx_MasterConfigSynchronization(&htim4, &sMasterConfig) != HAL_OK) {
        Error_Handler();
    }

    sConfigOC.OCMode = TIM_OCMODE_TIMING;
    sConfigOC.Pulse = 0;
    sConfigOC.OCPolarity = TIM_OCPOLARITY_HIGH;
    sConfigOC.OCFastMode = TIM_OCFAST_DISABLE;
    if (HAL_TIM_OC_ConfigChannel(&htim4, &sConfigOC, TIM_CHANNEL_1) != HAL_OK) {
        Error_Handler();
    }
}

void tim8_init(void)
{
    /*
     * TIM8 has channels that connect to the DMX512 TX/RX pins, and is made
     * available to assist in signal timing.
     * It may replace the current TIM4 ISR approach, but is not currently
     * being used.
     */
    TIM_MasterConfigTypeDef sMasterConfig = {0};
    TIM_OC_InitTypeDef sConfigOC = {0};
    TIM_BreakDeadTimeConfigTypeDef sBreakDeadTimeConfig = {0};

    htim8.Instance = TIM8;
    htim8.Init.Prescaler = 95;
    htim8.Init.CounterMode = TIM_COUNTERMODE_UP;
    htim8.Init.Period = 65535;
    htim8.Init.ClockDivision = TIM_CLOCKDIVISION_DIV1;
    htim8.Init.RepetitionCounter = 0;
    htim8.Init.AutoReloadPreload = TIM_AUTORELOAD_PRELOAD_DISABLE;
    if (HAL_TIM_PWM_Init(&htim8) != HAL_OK) {
        Error_Handler();
    }

    sMasterConfig.MasterOutputTrigger = TIM_TRGO_RESET;
    sMasterConfig.MasterSlaveMode = TIM_MASTERSLAVEMODE_DISABLE;
    if (HAL_TIMEx_MasterConfigSynchronization(&htim8, &sMasterConfig) != HAL_OK) {
        Error_Handler();
    }

    sConfigOC.OCMode = TIM_OCMODE_PWM1;
    sConfigOC.Pulse = 0;
    sConfigOC.OCPolarity = TIM_OCPOLARITY_HIGH;
    sConfigOC.OCNPolarity = TIM_OCNPOLARITY_HIGH;
    sConfigOC.OCFastMode = TIM_OCFAST_DISABLE;
    sConfigOC.OCIdleState = TIM_OCIDLESTATE_RESET;
    sConfigOC.OCNIdleState = TIM_OCNIDLESTATE_RESET;
    if (HAL_TIM_PWM_ConfigChannel(&htim8, &sConfigOC, TIM_CHANNEL_1) != HAL_OK) {
        Error_Handler();
    }

    sBreakDeadTimeConfig.OffStateRunMode = TIM_OSSR_DISABLE;
    sBreakDeadTimeConfig.OffStateIDLEMode = TIM_OSSI_DISABLE;
    sBreakDeadTimeConfig.LockLevel = TIM_LOCKLEVEL_OFF;
    sBreakDeadTimeConfig.DeadTime = 0;
    sBreakDeadTimeConfig.BreakState = TIM_BREAK_DISABLE;
    sBreakDeadTimeConfig.BreakPolarity = TIM_BREAKPOLARITY_HIGH;
    sBreakDeadTimeConfig.AutomaticOutput = TIM_AUTOMATICOUTPUT_DISABLE;
    if (HAL_TIMEx_ConfigBreakDeadTime(&htim8, &sBreakDeadTimeConfig) != HAL_OK) {
        Error_Handler();
    }
}

void tim9_init(void)
{
    /*
     * TIM9 is used to control the piezo buzzer frequency
     */
    TIM_OC_InitTypeDef sConfigOC = {0};

    htim9.Instance = TIM9;
    htim9.Init.Prescaler = 119;
    htim9.Init.CounterMode = TIM_COUNTERMODE_UP;
    htim9.Init.Period = 999;
    htim9.Init.ClockDivision = TIM_CLOCKDIVISION_DIV1;
    htim9.Init.AutoReloadPreload = TIM_AUTORELOAD_PRELOAD_DISABLE;
    if (HAL_TIM_PWM_Init(&htim9) != HAL_OK) {
        Error_Handler();
    }

    sConfigOC.OCMode = TIM_OCMODE_PWM1;
    sConfigOC.Pulse = 500;
    sConfigOC.OCPolarity = TIM_OCPOLARITY_HIGH;
    sConfigOC.OCFastMode = TIM_OCFAST_DISABLE;
    if (HAL_TIM_PWM_ConfigChannel(&htim9, &sConfigOC, TIM_CHANNEL_1) != HAL_OK) {
        Error_Handler();
    }

    HAL_TIM_MspPostInit(&htim9);
}

void tim10_init(void)
{
    /*
     * TIM10 is used to generate an interrupt for orchestrating the
     * countdown timer.
     */
    htim10.Instance = TIM10;
    htim10.Init.Prescaler = 179;
    htim10.Init.CounterMode = TIM_COUNTERMODE_UP;
    htim10.Init.Period = 9999;
    htim10.Init.ClockDivision = TIM_CLOCKDIVISION_DIV1;
    htim10.Init.AutoReloadPreload = TIM_AUTORELOAD_PRELOAD_DISABLE;
    if (HAL_TIM_Base_Init(&htim10) != HAL_OK) {
        Error_Handler();
    }
}

void crc_init(void)
{
    hcrc.Instance = CRC;
    if (HAL_CRC_Init(&hcrc) != HAL_OK) {
        Error_Handler();
    }
}

void usart_deinit(void)
{
    HAL_UART_DeInit(&huart6);
    HAL_UART_DeInit(&huart1);
}

void gpio_deinit(void)
{
    HAL_GPIO_DeInit(KEY_INT_GPIO_Port, KEY_INT_Pin);
    HAL_GPIO_DeInit(RELAY_ENLG_GPIO_Port, RELAY_ENLG_Pin);
    HAL_GPIO_DeInit(USB_HUB_CLK_GPIO_Port, USB_HUB_CLK_Pin);
    HAL_GPIO_DeInit(GPIOB, USB_HUB_RESET_Pin|USB_DRIVE_VBUS_Pin);
    HAL_GPIO_DeInit(GPIOB, GPIO_PIN_1|GPIO_PIN_2|GPIO_PIN_4|GPIO_PIN_9);
    HAL_GPIO_DeInit(GPIOA, GPIO_PIN_3|GPIO_PIN_12);
    HAL_GPIO_DeInit(GPIOA, BUZZ_EN1_Pin|BUZZ_EN2_Pin|DISP_CS_Pin|DISP_DC_Pin|DMX512_RX_EN_Pin);
    HAL_GPIO_DeInit(GPIOC, KEY_RESET_Pin);
    HAL_GPIO_DeInit(GPIOC, LED_RESET_Pin|DISP_RESET_Pin|DMX512_TX_EN_Pin|RELAY_SFLT_Pin);
    HAL_GPIO_DeInit(GPIOC, GPIO_PIN_13|GPIO_PIN_14|GPIO_PIN_15|GPIO_PIN_0|GPIO_PIN_3);

    __HAL_RCC_GPIOC_CLK_DISABLE();
    __HAL_RCC_GPIOH_CLK_DISABLE();
    __HAL_RCC_GPIOA_CLK_DISABLE();
    __HAL_RCC_GPIOB_CLK_DISABLE();
    __HAL_RCC_GPIOD_CLK_DISABLE();
}

void dma_deinit(void)
{
    HAL_NVIC_DisableIRQ(DMA2_Stream6_IRQn);
    __HAL_RCC_DMA2_CLK_DISABLE();
}

void i2c_deinit(void)
{
    HAL_SMBUS_DeInit(&hsmbus2);
    HAL_I2C_DeInit(&hi2c1);
}

void spi_deinit(void)
{
    HAL_SPI_DeInit(&hspi1);
}

void tim_deinit(void)
{
    HAL_TIM_Base_DeInit(&htim10);
    HAL_TIM_PWM_DeInit(&htim9);
    HAL_TIM_PWM_DeInit(&htim8);
    HAL_TIM_OC_DeInit(&htim4);
    HAL_TIM_Encoder_DeInit(&htim1);
}
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
int main(void)
{
    /*
     * Initialize the HAL, which will reset of all peripherals, initialize
     * the Flash interface and the Systick.
     */
    HAL_Init();

    /* Configure the system clock */
    system_clock_config();
    peripheral_common_clock_config();

    /* Initialize the MPU */
    mpu_config();

#ifdef USE_SEGGER_RTT
    SEGGER_RTT_ConfigUpBuffer(0, NULL, NULL, 0, SEGGER_RTT_MODE_NO_BLOCK_SKIP);
#endif

    /* Initialize all configured peripherals */
    usart1_uart_init();
    dma_init();
    usart6_uart_init();
    gpio_init();
    i2c1_init();
    i2c2_smbus_init();
    spi1_init();
    tim1_init();
    tim4_init();
    tim8_init();
    tim9_init();
    tim10_init();
    crc_init();

    /* Initialize the FreeRTOS scheduler */
    osKernelInitialize();

    /* Initialize the logger */
    logger_init();

    /* Create the default task */
    main_task_init();

    /* Start the FreeRTOS scheduler */
    osKernelStart();

    while (1) {
    }
}

/**
 * @brief  Period elapsed callback in non blocking mode
 * @note   This function is called when the TIM11 interrupt takes place,
 * inside HAL_TIM_IRQHandler(). It makes a direct call to HAL_IncTick()
 * to increment a global variable "uwTick" that is used as application
 * time base.
 * @param  htim TIM handle
 */
void HAL_TIM_PeriodElapsedCallback(TIM_HandleTypeDef *htim)
{
    if (htim->Instance == TIM11) {
        HAL_IncTick();
    } else if (htim->Instance == TIM10) {
        main_task_notify_countdown_timer();
    }
}

void HAL_GPIO_EXTI_Callback(uint16_t GPIO_Pin)
{
    gpio_task_notify_gpio_int(GPIO_Pin);
}

void HAL_TIM_IC_CaptureCallback(TIM_HandleTypeDef *htim)
{
    static volatile uint32_t enc_last_tick = 0;
    static volatile uint32_t enc_last_dir = UINT32_MAX;

    if (htim->Instance == TIM1 && HAL_NVIC_GetActive(TIM1_CC_IRQn)
    && !HAL_NVIC_GetActive(TIM1_TRG_COM_TIM11_IRQn)) {
        uint32_t enc_tick = HAL_GetTick();
        uint32_t enc_dir = __HAL_TIM_IS_TIM_COUNTING_DOWN(&htim1);
        if (enc_tick - enc_last_tick < 100 && enc_last_dir == enc_dir) {
            if (enc_dir) {
                gpio_task_notify_gpio_int(ENC_CH1_Pin);
            } else {
                gpio_task_notify_gpio_int(ENC_CH2_Pin);
            }
            enc_last_dir = UINT32_MAX;
        }
        enc_last_tick = enc_tick;
        enc_last_dir = enc_dir;
    }
}

void HAL_TIM_OC_DelayElapsedCallback(TIM_HandleTypeDef *htim)
{
    if (htim->Instance == TIM4) {
        dmx_timer_notify();
    }
}

void HAL_UART_TxCpltCallback(UART_HandleTypeDef *huart)
{
    if (huart->Instance == USART6) {
        dmx_uart_tx_cplt();
    }
}


void Error_Handler(void)
{
    __disable_irq();
    __ASM volatile("BKPT #01");
    while (1) { }
}

#ifdef USE_FULL_ASSERT
/**
 * @brief  Reports the name of the source file and the source line number
 *         where the assert_param error has occurred.
 * @param  file: pointer to the source file name
 * @param  line: assert_param error line source number
 * @retval None
 */
void assert_failed(uint8_t *file, uint32_t line)
{
    printf("Assert failed: file %s on line %ld\r\n", file, line);
}
#endif /* USE_FULL_ASSERT */

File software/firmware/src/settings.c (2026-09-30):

#include "settings.h"

#include <string.h>
#include <math.h>
#include <cmsis_os.h>

#define LOG_TAG "settings"
#include <elog.h>

#include "settings_util.h"
#include "buzzer.h"
#include "m24m01.h"
#include "contrast.h"
#include "util.h"

/*
 * Make sure any length constants, which the memory alignment of
 * settings may depend upon, haven't been changed.
 */
#ifndef __CDT_PARSER__
_Static_assert(PROFILE_NAME_LEN == 32, "PROFILE_NAME_LEN length has been changed");
_Static_assert(CONTRAST_WHOLE_GRADE_COUNT == 7, "CONTRAST_WHOLE_GRADE_COUNT length has been changed");
#endif

#define LATEST_CONFIG_VERSION           1
#define DEFAULT_EXPOSURE_TIME           15000
#define DEFAULT_CONTRAST_GRADE          CONTRAST_GRADE_2
#define DEFAULT_STEP_SIZE               EXPOSURE_ADJ_QUARTER
#define DEFAULT_MENU_TIMEOUT            30000
#define DEFAULT_ENLARGER_FOCUS_TIMEOUT  300000
#define DEFAULT_DISPLAY_BRIGHTNESS      0x0F
#define DEFAULT_LED_BRIGHTNESS          10
#define DEFAULT_BUZZER_VOLUME           BUZZER_VOLUME_MEDIUM
#define DEFAULT_TESTSTRIP_MODE          TESTSTRIP_MODE_INCREMENTAL
#define DEFAULT_TESTSTRIP_PATCHES       TESTSTRIP_PATCHES_7
#define DEFAULT_ENLARGER_CONFIG         0
#define DEFAULT_PAPER_PROFILE           0

#define LATEST_CONFIG2_VERSION          1
#define DEFAULT_SAFELIGHT_CONFIG        { SAFELIGHT_MODE_AUTO, SAFELIGHT_CONTROL_RELAY, 0, false, 255 }

#define LATEST_ENLARGER_CONFIG_VERSION  1
#define LATEST_PAPER_PROFILE_VERSION    2
#define LATEST_STEP_WEDGE_VERSION       1

/* Handle to I2C peripheral used by the EEPROM */
static I2C_HandleTypeDef *eeprom_i2c = NULL;
static osMutexId_t eeprom_i2c_mutex = NULL;

/* Persistent user settings backed by EEPROM values */
static uint32_t setting_default_exposure_time = DEFAULT_EXPOSURE_TIME;
static contrast_grade_t setting_default_contrast_grade = DEFAULT_CONTRAST_GRADE;
static exposure_adjustment_increment_t setting_default_step_size = DEFAULT_STEP_SIZE;
static uint32_t setting_menu_timeout = DEFAULT_MENU_TIMEOUT;
static uint32_t setting_enlarger_focus_timeout = DEFAULT_ENLARGER_FOCUS_TIMEOUT;
static uint8_t setting_display_brightness = DEFAULT_DISPLAY_BRIGHTNESS;
static uint8_t setting_led_brightness = DEFAULT_LED_BRIGHTNESS;
static buzzer_volume_t setting_buzzer_volume = DEFAULT_BUZZER_VOLUME;
static teststrip_mode_t setting_teststrip_mode = DEFAULT_TESTSTRIP_MODE;
static teststrip_patches_t setting_teststrip_patches = DEFAULT_TESTSTRIP_PATCHES;
static uint8_t setting_enlarger_config = DEFAULT_ENLARGER_CONFIG;
static uint8_t setting_paper_profile = DEFAULT_PAPER_PROFILE;
static safelight_config_t setting_safelight_config = DEFAULT_SAFELIGHT_CONFIG;

/**
 * Header Page (256B)
 * Mostly unused at the moment, will be populated if any top-level system
 * data needs to be stored. Unlike other pages, it begins with a magic
 * string.
 */
#define PAGE_HEADER                      0x00000UL
#define PAGE_HEADER_SIZE                 (256U)
#define HEADER_MAGIC                     0 /* "PRINTALYZER\0" */
#define HEADER_START                     16
#define HEADER_VERSION                   1UL

/**
 * Basic configuration page (256B)
 * Contains simple configuration values that are stored
 * as standalone elements.
 */
#define PAGE_CONFIG                      0x00100UL
#define PAGE_CONFIG_SIZE                 (256U)
#define CONFIG_VERSION                   0
#define CONFIG_EXPOSURE_TIME             4
#define CONFIG_CONTRAST_GRADE            8
#define CONFIG_STEP_SIZE                 12
#define CONFIG_MENU_TIMEOUT              16
#define CONFIG_ENLARGER_FOCUS_TIMEOUT    20
#define CONFIG_DISPLAY_BRIGHTNESS        24
#define CONFIG_LED_BRIGHTNESS            28
#define CONFIG_BUZZER_VOLUME             32
#define CONFIG_TESTSTRIP_MODE            36
#define CONFIG_TESTSTRIP_PATCHES         40
#define CONFIG_ENLARGER_CONFIG           44
#define CONFIG_PAPER_PROFILE             48
/* RESERVED                              52*/

/**
 * Detailed configuration page (256B)
 * Contains configuration values that are stored as structures of
 * related elements.
 */
#define PAGE_CONFIG2                     0x00200UL
#define PAGE_CONFIG2_SIZE                (256U)
#define CONFIG2_VERSION                  0
#define CONFIG2_SAFELIGHT_CONTROL        4
#define CONFIG2_SAFELIGHT_CONTROL_SIZE   (12U)
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

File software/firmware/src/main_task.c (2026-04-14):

#include "main_task.h"

#include <FreeRTOS.h>
#include <task.h>
#include <queue.h>
#include <cmsis_os.h>

#include <stdio.h>
#include <stdint.h>
#include <math.h>
#include <machine/endian.h>

#define LOG_TAG "main_task"
#include <elog.h>

#include "exposure_timer.h"
#include "usb_host.h"
#include "display.h"
#include "led.h"
#include "gpio_task.h"
#include "keypad.h"
#include "buzzer.h"
#include "relay.h"
#include "board_config.h"
#include "state_controller.h"
#include "illum_controller.h"
#include "settings.h"
#include "app_descriptor.h"
#include "meter_probe.h"
#include "dmx.h"

/* Peripheral handles initialized before this task is started */
extern UART_HandleTypeDef huart1;
extern I2C_HandleTypeDef hi2c1;
extern SMBUS_HandleTypeDef hsmbus2;
extern SPI_HandleTypeDef hspi1;
extern SPI_HandleTypeDef hspi3;
extern TIM_HandleTypeDef htim1;
extern TIM_HandleTypeDef htim3;
extern TIM_HandleTypeDef htim9;
extern TIM_HandleTypeDef htim10;

static void main_task_run(void *argument);
static void main_task_startup_log();
static void main_task_display_init();
static void main_task_led_init();
static void main_task_buzzer_init();
static void main_task_relay_init();
static void main_task_exposure_timer_init();
static void main_task_keypad_init();
static void main_task_enable_interrupts();
static void main_task_disable_interrupts();
extern void deinit_peripherals();

typedef struct {
    const osThreadFunc_t task_func;
    const osThreadAttr_t task_attrs;
    const uint8_t task_arg;
    osThreadId_t task_handle;
} task_params_t;

static osSemaphoreId_t task_start_semaphore = NULL;
static const osSemaphoreAttr_t task_start_semaphore_attributes = {
    .name = "task_start_semaphore"
};

#define TASK_MAIN_STACK_SIZE        (8192U)
#define TASK_GPIO_STACK_SIZE        (2048U)
#define TASK_KEYPAD_STACK_SIZE      (2048U)
#define TASK_BUZZER_STACK_SIZE      (1024U)
#define TASK_DMX_STACK_SIZE         (2048U)
#define TASK_METER_PROBE_STACK_SIZE (2048U)

static task_params_t task_list[] = {
    {
        .task_func = main_task_run,
        .task_attrs = {
            .name = "main",
            .stack_size = TASK_MAIN_STACK_SIZE,
            .priority = osPriorityNormal
        }
    },
    {
        .task_func = gpio_task_run,
        .task_attrs = {
            .name = "gpio",
            .stack_size = TASK_GPIO_STACK_SIZE,
            .priority = osPriorityNormal
        }
    },
    {
        .task_func = task_keypad_run,
        .task_attrs = {
            .name = "keypad",
            .stack_size = TASK_KEYPAD_STACK_SIZE,
            .priority = osPriorityNormal
        }
    },
    {
        .task_func = task_buzzer_run,
        .task_attrs = {
            .name = "buzzer",
            .stack_size = TASK_BUZZER_STACK_SIZE,
            .priority = osPriorityNormal
        }
    },
    {
        .task_func = task_dmx_run,
        .task_attrs = {
            .name = "dmx",
            .stack_size = TASK_DMX_STACK_SIZE,
            .priority = osPriorityAboveNormal
        }
    },
    {
        .task_func = task_meter_probe_run,
        .task_attrs = {
            .name = "meter_probe",
            .stack_size = TASK_METER_PROBE_STACK_SIZE,
            .priority = osPriorityNormal
        }
    },
    {
        .task_func = task_meter_probe_run,
        .task_attrs = {
            .name = "densistick",
            .stack_size = TASK_METER_PROBE_STACK_SIZE,
            .priority = osPriorityNormal
        }
    }
};

static osMutexId_t i2c1_mutex;
static const osMutexAttr_t i2c1_mutex_attributes = {
    .name = "i2c1_mutex",
    .attr_bits = osMutexRecursive
};

static bool main_task_running = false;

osStatus_t main_task_init()
{
    /* Create the mutex used to protect the I2C1 peripheral */
    i2c1_mutex = osMutexNew(&i2c1_mutex_attributes);
    if (!i2c1_mutex) {
        log_e("i2c1_mutex create error");
        return osErrorNoMemory;
    }

    /* Create the semaphore used to synchronize task startup */
    task_start_semaphore = osSemaphoreNew(1, 0, &task_start_semaphore_attributes);
    if (!task_start_semaphore) {
        log_e("task_start_semaphore create error");
        return osErrorNoMemory;
    }

    /* Create the main task */
    task_list[0].task_handle = osThreadNew(task_list[0].task_func, NULL, &task_list[0].task_attrs);
    if (!task_list[0].task_handle) {
        log_e("main_task create error");
        return osErrorNoMemory;
    }
    return osOK;
}

bool task_main_is_running()
{
    return main_task_running;
}
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

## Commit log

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2020-11-03 Annotated schematic got ERC to pass
    Annotated a few components manually, then let KiCad to the rest
    automatically.
    Added no-connection flags to all intentionally-unused pins.
    Added comments next to no-connection pins that are likely to become used
    soon.
    Fixed USB power switch schematic symbol's output pin type.
    Fixed IEC output jack schematic symbol pin types.
    Rearranged power flags as needed to get ERC to pass.
    In cases where power needs to flow through another component (switch,
    fuse, inductor, etc) a power flag is needed to make ERC happy.
    The Vcap pin on the STM32 schematic symbol seems to be designated as a
    power input, even though this pin is only supposed to connect to a
    capacitor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
    [main-board-front.sch, main-board-input.sch, main-board-power.sch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]
2020-11-03 Fill in BOM data for all known components
    Added BOM assignments for main board components
    Fixed GNDDetect connection on STDC14 connector
    Added more notes to the main board schematic of things that are still
    TBD or need fixing.
    [main-board-front.sch, main-board-input.sch, main-board-power.sch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]
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2020-11-08 Implemented a dedicated symbol/footprint for the NHD-3.12 display
    The footprint combines the pin socket/header connector with correctly
    aligned mounting holes, to make PCB layout easier.
    The symbol labels the pins for the display module's serial interface, to
    make the schematic a little bit nicer.
    Included the STEP model of the display from the NHD website.
    Functionally, its not that different than before.
    [main-board.sch]
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2020-11-12 PCB layout cleanup and minor fixes
    Tweaked traces all over the PCB
    Increased size of capacitor on USB VBUS
    Added ground connections to the crystal case
    Slightly increased the size of the isolated ground around the crystal
    [main-board-front.sch, main-board.kicad_pcb, main-board.sch]
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2020-11-13 Added initial model files for the physical hardware
    The STL files for 3D printing the meter probe enclosure are included.
    The Front Panel Designer files for the enclosure are also included.
    These are initial layouts to (hopefully) get all the mechanical
    dimensions and alignment correct, and do not yet have any artwork.
    [meter-probe-bottom.stl, meter-probe-top.stl]
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2020-11-14 Added "User Label" field to clean up BOM data for labeled common parts
    This change is to prevent things like buttons, connectors, and relays
    from being ungrouped on the BOM.
    [main-board-front.sch, main-board-input.sch, main-board-power.sch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]
2020-11-16 Added proper test points on the TP connections
    Replaced simple plated pads with actual test point inserts.
    Adjusted some trace sizes around the power regulator grounds
    [main-board-power.sch, main-board.kicad_pcb]
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2020-12-04 Added USB HID injection of keypad events
    Picked decent guesses for equivalent keys.
    Made minor tweaks to syscal UART writes.
    Changed keypad enum names to avoid conflicts.
    [main_task.c]
2020-12-04 Added basic driver code for the piezo buzzer
    Nothing yet to actually control the frequency, or manage beep duration,
    but this is a basic starting point.
    [main_task.c]
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2020-12-06 Rotary encoder input implemented
    Detecting rotation with the timer encoder feature on TIM1
    Only triggering on even counts, since we get two interrupts per tick of
    the knob.
    Still some debouncing(ish) issues to resolve, where we'll get a lone event in
    the wrong direction when fiddling with the knob. Likely a quirk of the
    input we can filter out, but something that should be dealt with.
    Detected rotation ticks are injected as key events into the keypad event
    queue.
    No idea what the TIM1 commutation interrupt is used for, but had to
    disable it since it occasionally fires and is at a priority level
    incompatible with FreeRTOS interrupt handling.
    [keypad.c, main.c, main_task.c]
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2020-12-07 Added basic exposure state tracking and stop adjustment
    This is still mostly placeholder code, but does allow for simplistic
    stop-based time adjustment.
    Also made some fixes to default logging configuration, and stopped noisy
    debug logging from the keypad routines.
    [exposure_state.c, keypad.c, main_task.c]
2020-12-08 Redesigned keypad handling to support key combos and repeat events
    Originally, the keypad handler would do its thing directly on the GPIO
    event task and send results to the key event queue. The problem was that
    this couldn't easily deal with timers or other behaviors.
    The new design adds a dedicated keypad task, which acts as an
    intermediary. Raw events from the GPIO event task function (which runs
    in response to controller interrupts) are added to an internal queue.
    This queue is then handled by the dedicated keypad task to produce
    events handled by the rest of the application.
    Additionally, this task/queue allows the addition of keypad timer
    events, which are used to implement key repeat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
    [keypad.c, main_task.c]
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2020-12-10 Fixed encoder interrupt handling to be safer
    Somehow the commutation interrupt was getting triggered even though I
    thought it wasn't being enabled. This breaks FreeRTOS due to its
    priority level. So instead, the new approach is to let it always be
    enabled, but make sure we're not actually handling it in the code that
    dispatches events into FreeRTOS.
    [main.c]
2020-12-10 Added diagnostics menu with some basic on-board hardware tests
    Keypad test shows toggle state of all the buttons.
    LED test allows toggling and brightness control of LEDs
    Also added code to better handle LED brightness changes and state
    control.
    Buzzer test and basic frequency adjustment
    Output relay test
    [led.c, main_task.c]
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2020-12-24 Increase reliability of encoder rotation events
    This is an attempt at filtering out the wonky results that were coming
    from a more simplistic handling of encoder counter interrupts.
    To generate an event, we now must receive two interrupts that both show
    the encoder rotating in the same direction. Furthermore, these
    interrupts must happen within a brief period of each other.
    Doing this appears to keep encoder events to be consistent with
    intentional detent "clicks" by the user, and seems to prevent spurious
    counter-direction events.
    [main.c]
2020-12-25 Another check to prevent the commutation interrupt from getting through
    Apparently there are cases where the commutation interrupt and capture
    compare interrupts happen at the same time, and both flags are active.
    Need to explicitly catch this to avoid hitting the FreeRTOS interrupt
    priority assertion.
    [main.c]
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2021-01-11 Implement entry and editing of burn/dodge adjustments
    Main screen now displays a count of added adjustments
    Short-press on the "add adjustment" button adds an adjustment, while a
    long press lists the added adjustments.
    The first adjustment can be a burn or dodge, and the rest can only be
    burn.
    Adjustments are added in fractions of a stop, using the current
    increment. They default to the base grade, but burning at other grades
    is supported. This will become useful once grade-specific paper
    calibration is implemented.
    Using these adjustments during the exposure process is not yet
    implemented.
    While implementing these features, a number of additional changes were
    made:
    Did a lot of refact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
    [exposure_state.c]
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2021-01-15 Enlarger profile management UI
    Added UI for showing a list of enlarger profiles, selecting the
    active/default profile, and editing profile fields.
    Made the enlarger calibration process plug into the profile management
    list.
    Implemented auto-gain for enlarger calibration, which works by detecting
    the highest gain setting that doesn't saturate the sensor.
    Enlarger profiles now include a display name and a color temperature.
    Not sure yet what the color temperature will be used for, but it at
    least can be used to detect cases where the enlarger light differs
    significantly from what was calibrated (e.g. if the user accidentally
    left a filter in the tray).
    [settings.c]
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2021-01-18 More correctly implement USB keyboard support
    Change USB keyboard event routing so that it is no longer intermingled
    with regular keypad events, even if its distributed via the same queue.
    This now requires key handler code to separately handle events from both
    sources, but has the benefit of allowing them to be treated separately.
    It is necessary to do this to avoid confusing state between the
    different input devices.
    Update u8g2 display input handling routines to deal wih the USB keyboard
    changes.
    Modify display_input_text to support entry via the keyboard, and changed
    the behavior of the "+" and "Menu" buttons on this screen for
    consistency.
    Handle capslock correctly in the USB keyboar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
    [keypad.c]
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2021-01-26 Added basic MPU guard and stack checking
    It might make sense to switch to the complex MPU capabilities in
    FreeRTOS at some point, but this should be sufficient to catch gross
    code errors.
    Likewise, the stack checking uses a constant guard token due to lack of
    an easy random option on this target.
    [main.c]
2021-01-26 Add calibration mode to the device home screen
    Pressing the left/right arrow buttons together allows for
    mode-switching now, with a new "Calibration" mode being added alongside
    the existing "Printing" mode.
    In calibration mode, burn/dodge adjustments are disabled, and PEV values
    are prominently displayed based on the last meter reading.
    Taking a meter reading will calculate an exposure time to achieve a
    decent starting PEV. From this point, exposure time adjustments will
    update the displayed PEV accordingly. Also, the contrast arrows will now
    adjust the PEV and update the exposure time as well.
    When making a test strip, the display will show the PEV for each patch
    of the strip.
    The goal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
    [exposure_state.c]
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2021-01-28 Add max net density to paper profiles
    Calculating the complete characteristic curve for a paper grade requires
    knowing the density values corresponding to all three PEV points. Two of
    these are fixed in the standard. The third is based on the paper's max
    net density (relative Dmax).
    This adds the value to the paper profiles, the profile editor menus, and
    fixes a title bug with one part of the profile editor.
    [settings.c]
2021-01-28 Convert meter reading to array and clean up mode switching
    Meter readings now being kept in an array, to support multiple readings.
    Calibration mode still forces a single reading in this array.
    Changed mode selection state so the exposure state's mode isn't affected
    until the selection is accepted.
    Moved mode-switching behaviors into the exposure state module, which
    includes decisions of what fields get reset as part of which mode
    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
    [exposure_state.c]
2021-01-30 Initial implementation of tone graph and print metering
    Tone graph is computed via one of two methods, depending on how much
    information is available in the paper profile.
    - By evenly dividing the paper's contrast range
    - By evenly dividing the paper's density range, and using an
    interpolation of the paper's characteristic curve to find where those
    points fall on the contrast range scale.
    Metering sets the base exposure to whatever places the lowest reading at
    the D=0.04 (lower bound) point, then populates the tone graph based on
    this and the rest of the values.
    There are a few outstanding issues with this process that should be
    fixed in future commits:
    - Sometimes tones jump between s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
    [exposure_state.c]
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2021-02-15 Add step wedge configuration and settings UI
    This adds the necessary structures, settings code, and UI code, to
    handle a step wedge profile. Only a single configured step wedge is
    supported, but that should be sufficient for the expected use cases.
    The intended use of the step wedge profile is paper calibration, where
    it will be applied to data from an as-yet-unbuilt step wedge exposure
    module under the paper profile settings to automatically calculate paper
    profile values.
    The step wedge profile serves no functional purpose outside of the
    process of creating a new paper profile, but it has to go somewhere
    sensible in the menu system. Its currently a top-level item to prevent
    it from being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
    [settings.c]
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2021-02-19 Add initial build tagging to firmware
    This puts in place some initial bits to include the build date and git
    information inside the firmware image. It is just a starting point, and
    may need refinement to get user-acceptable version numbers in a
    repository that may have hardware and software revision tags mixed
    together.
    While the macros added to the build are setup in the makefile.defs file,
    they needed to be added to the compiler directly inside the Eclipse
    build configuration. Trying to put them all into a single variable for
    inclusion on the Eclipse side had the unintended effect of breaking
    Eclipse's system include file indexer.
    Fixes #8
    [main_task.c]
2021-02-23 Initial integration of bootloader support into the project
    Added in a basic CubeMX code dump, with configuration changes to support
    bootloader needs. This means no FreeRTOS, USB host support just for MSC,
    and enabling the CRC module. Also, the HAL timebase has been changed
    back to SysTick and unnecessary timer peripherals are no longer
    configured.
    Pulled in a cut down version of the u8g2 library. This means that
    instead of dropping the code in as-is, just the csrc portion has been
    added as a pair of "src" and "include" directories. Furthermore, display
    driver code for all display drivers besides the NHD/SSD1322 has been
    removed. Also, all fonts except a version of "pressstart2p" have been
    d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
    [board_config.h, bootloader.c, keypad.c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]
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2021-02-28 Add breakpoint triggers to fault/error/assert handlers
    Any time we end up throwing a fatal error and going into an infinite
    loop, it makes sense to stop an attached debugger at a breakpoint. This
    makes it easier to deal with such situations and find their cause.
    [main.c]
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2021-03-01 Cleanup of MIN/MAX macros
    Since one of the framework headers is now conditionally defining these,
    it makes sense to just use a single set of conditional definitions
    inside "util.h" for the rest of the project. This silences compiler
    redefinition warnings and avoids needless duplication.
    [exposure_state.c]
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2021-03-01 Implement basic densitometer mode
    This adds another mode to the mode selection list, between "Printing"
    and "Calibration."
    Densitometer mode disables all adjustments, and simply compares two
    light readings (the lowest and the most recent) on a log10 scale.
    There is still probably some room for display code refactoring, as more
    modes are being added to the home display. Trying to cram all of them
    into the same data structure keeps making less and less sense. However,
    they at least now have separate draw functions.
    As part of this limited display code cleanup, certain elements (profile
    number, burn/dodge count, tone graph) are no longer displayed in
    calibration mode where they are not relev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
    [exposure_state.c]
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2021-03-06 Basic implementation of device settings import/export
    Provides the basic ability to dump all device settings and profiles to a
    JSON-formatted file on an inserted USB stick.
    Also provides the ability to import these settings from the USB stick,
    selectively deciding which portions to import. This may help with making
    it possible to work with paper profiles off-device, without overwriting
    other device settings.
    Right now this process uses a fixed filename for simplicity, but that
    should be changed as soon as a file browser can be implemented.
    Fixes #1
    [settings.c]
2021-03-06 Move safelight control inside the exposure timer code
    This allows us to turn the safelight back on, and the end of an exposure
    cycle, while the end beep is happing. This should increase apparent
    responsiveness when doing successive exposures, such as with test strips
    or burn/dodge.
    [exposure_timer.c]
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2021-03-09 Add ability to runtime-switch paper profiles
    This adds a long-press action to the "test strip" button that allows
    changing of the active paper profile without any persistence. It may not
    be the ideal placement for this action, but we're out of other good
    options (at least as long as we don't want the menu system to require a
    long-press to enter).
    Fixes #3
    [exposure_state.c]
2021-03-10 Add countdown beeps to burn/dodge exposures
    This adds an approximately 3 second delay before burn/dodge exposures,
    and the ability to cancel during that delay.
    Fixes #2
    [exposure_timer.c]
2021-03-12 Implement a flexible app descriptor to replace the image checksum
    This implements a new application descriptor structure that contains a
    variety of relevant information about the application build, in addition
    ot the simple checksum that existed previously. It is fixed at a known
    location within the binary image, so that it is readable by both the
    regular firmware that contains it and the bootloader. The checksum
    address itself is unchanged.
    The new approach to doing this removes a fair bit of build-time hacks
    that were done in favor of finally figuring out how to make the GNU ld
    linker script behave correctly to our needs. The changes to that linker
    script now do the following:
    - Make sure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
    [main_task.c]
2021-03-13 Add a live-adjusted tone graph to the fine adjustment states
    This shows a tone graph when doing fine adjustment by stops or absolute
    time, and adjusts that graph as the knob is turned.
    Fixes #31
    [exposure_state.c]
2021-03-13 Show an active tone graph on the burn/dodge adjustment editor
    This change makes it easier to visualize how a burn/dodge adjustment
    will affect the measured tones of the image. The basic visualization is
    similar to what's being done for the fine time/stops adjustment states.
    When the burn/dodge is being done at a different grade than the base
    exposure, the graph is recalculated accordingly. Handling this did
    require a fair bit of refactoring to allow using a temporary version of
    the graph marks array. As currently implemented, there is thus a bit of
    a performance penalty when displaying these working-copy modified tone
    graphs. However, this may be small enough to not seriously impact the
    UI.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
    [exposure_state.c]
2021-03-13 Blink added tone graph element
    When a meter reading is taken and a tone graph element is added, blink
    the added element briefly.
    Implementing this took some refactoring on the tone graph element
    calculations, to allow independently determining the element for the
    added reading from the general process of recreating the graph.
    Fixes #30
    [exposure_state.c]
2021-03-14 Add display of color head filter settings for contrast grades
    Completely refactored how contrast grades are represented to avoid
    duplication and dependency loops. The relevant data types are now kept
    in their own dedicated source/header files.
    Added a new element to the paper profiles that represents the type of
    contrast filter being used. Values include "Regular" (normal Ilford
    Multigrade style over/under the lens filters), and a variety of dichroic
    color head filter schemes for which data is available. This element has
    also been added to the paper profile configuration screens and
    configuration import/export.
    Added display of the dichroic settings for a particular contrast grade
    to the m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
    [exposure_state.c]
2021-03-14 Added indication of main exposure time being too short
    Based on the active enlarger profile, it is possible for the exposure
    time to be too short to be timed reliably. In these cases, we should
    alert the user to this.
    The first step was to fix some bugs in how this state was made known to
    the state controller and exposure state. Somehow it was not being set
    correctly when loading the active profile, and wasn't properly being
    converted from milliseconds to seconds. That issue should now be fixed.
    Then an indicator was added to the main printing and calibration timer
    displays when the displayed exposure time is less than what the enlarger
    profile can reliably support.
    There still needs to b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
    [exposure_state.c]
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2023-01-02 Fix meaningless ERC issues
    KiCad 6.0.10 made some power library changes that led to ERC warnings
    all across every existing schematic. This should fix the issues for
    this project.
    There's still one GND net related warning on the main board, which will
    be resolved as part of a future task to review the grounding strategy
    for that board.
    [main-board-front.kicad_sch, main-board-input.kicad_sch, main-board-power.kicad_sch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]
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2023-01-03 Fixed numerous PCB errors newly reported in KiCad v6
    Stray traces/vias caught by cleanup
    Crystal fill ground connection needed some fussing to still work
    Footprint silkscreen glitches and pad overlap issues
    Silkscreen violations
    Silenced silkscreen-vs-edge warnings on edge connector components
    [main-board.kicad_pcb]
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2023-01-05 Initial split of main board into separate main and power boards
    This is a first pass at splitting the main-board project into two
    separate projects. There's still a lot of placeholder bits around the
    inter-board connection, and PCB routing is incomplete.
    The main-board now excludes anything dealing with mains AC power, or the
    device's rear panel. As a result, it got a bit shorter.
    The new power-board contains all of the bits that deal with mains AC
    power input, relay power switching, and anything else that might need to
    connect to the rear panel of the enclosure. It is also now only a
    2-layer board, and it will stay that way unless there is an explicit
    need to do otherwise.
    The purpose o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
    [main-board-power.kicad_sch, main-board.kicad_pcb, main-board.kicad_sch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]
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2023-02-20 Switched AC/DC converter from CUI to Cincon part
    The new part has the same specifications, but is more available and
    slightly lower cost. It also takes less board space, but specifies
    clearance that cancels that out.
    [power-board.kicad_pcb, power-board.kicad_sch]
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2023-03-30 Change piezo driver from PAM8904EJPR to PAM8904JPR
    The former is a discontinued component.
    The latter is a drop-in replacement with the same footprint, but a
    different boost frequency. Hopefully it won't cause problems, but it
    might be worth doing standalone testing.
    [main-board-power.kicad_sch, main-board.kicad_sch]
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2023-03-30 Connect 3.3V rail to debug connector
    This is necessary for certain features of certain debug probes to work
    correctly.
    [main-board.kicad_sch]
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2023-05-02 Add IDC connector to schematic
    This replaces a single 6-pin part with two 3-pin parts
    [meter-probe.kicad_sch]
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2023-05-04 Swap AC/DC converter for IRM-10-12 and update output capacitor
    A bit more comfortable with this option versus the other one, since it
    likely has more protection and filtering. Still may want to rearrange
    and reroute some of the output components, which are a bit cramped at
    the moment.
    [power-board.kicad_pcb, power-board.kicad_sch]
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
